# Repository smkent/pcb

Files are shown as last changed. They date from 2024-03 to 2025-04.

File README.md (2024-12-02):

# PCB designs

A monorepository of my PCB designs created with [KiCAD][kicad] 8.

## Layout and Workflow

Custom symbols and footprints are located in [`libraries`][dir-libraries], which
is shared between PCB projects using [`${KIPRJMOD}`][docs-kiprjmod].

Individual PCB projects (e.g. `*.kicad_pro` and friends) are located within
within [`pcb`][dir-pcb] for active projects, or
[`pcb-archived`][dir-pcb-archived] for archived projects.

When a PCB is ordered from a project, fabrication outputs are created and
in the project's `fab` subdirectory and committed to the repository.

## Setup

Ensure [pipx][pipx] is installed:

```sh
pip install pipx
```

Install [scons][scons]:

```sh
pipx install scons
```

Install KiCAD-related dependencies using the system site packages directory:

```sh
pipx install --system-site-packages kikit interactivehtmlbom
```

## Build

To render all outputs, simply run `scons`.

To render outputs for a particular board, run `scons -u` within that board's
project subdirectory.

## Licenses

Individual hardware designs in this repository may use different licenses.
The following licenses apply unless an included design directory specifies
different license(s).

* Hardware materials and designs are licensed under [CERN Open Hardware License
  version 2.0 Permissive (CERN-OHL-P v2)][license-cern-ohl-p-2.0]
  ([text](/LICENSE.hardware)). The version control history of this repository
  serves as the changes file.
* Software is licensed under the
  [GNU General Public License v3.0 (GPL-3.0)][license-gpl-3.0]
  ([text](/LICENSE.software))
* All documentation is licensed under
  [Creative Commons Attribution-ShareAlike 4.0 International
  (CC-BY-SA-4.0)][license-cc-by-sa-4.0] ([text](/LICENSE.documentation))

The `lcsc` KiCAD [symbols][libraries-lcsc-symbols],
[footprints][libraries-lcsc-pretty], and [3D models][libraries-lcsc-3dshapes]
libraries were created using [easyeda2kicad][easyeda2kicad]
([pypi][easyeda2kicad-pypi]), which are from [LCSC][lcsc]. [More info about
easyeda2kicad][easyeda2kicad-post]

[dir-libraries]: /libraries
[dir-pcb-archived]: /pcb-archived
[dir-pcb]: /pcb
[docs-kiprjmod]: https://docs.kicad.org/8.0/it/pcbnew/pcbnew_footprints_and_libraries.html#fp-path-variable-substitution
[easyeda2kicad-post]: https://hackaday.com/2023/08/08/easyeda2kicad-never-draw-a-footprint-again/
[easyeda2kicad-pypi]: https://pypi.org/project/easyeda2kicad/
[easyeda2kicad]: https://github.com/uPesy/easyeda2kicad.py
[kicad]: https://kicad.org/
[lcsc]: https://lcsc.com
[libraries-lcsc-3dshapes]: /libraries/lcsc.3dshapes
[libraries-lcsc-pretty]: /libraries/lcsc.pretty
[libraries-lcsc-symbols]: /libraries/lcsc.kicad_sym
[license-cc-by-sa-4.0]: https://creativecommons.org/licenses/by-sa/4.0/
[license-cern-ohl-p-2.0]: https://ohwr.org/cern_ohl_p_v2.pdf
[license-gpl-3.0]: https://www.gnu.org/licenses/gpl-3.0.html
[pipx]: https://pipx.pypa.io
[scons]: https://www.scons.org

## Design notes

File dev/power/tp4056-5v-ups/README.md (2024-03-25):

# Li-ion 5V UPS

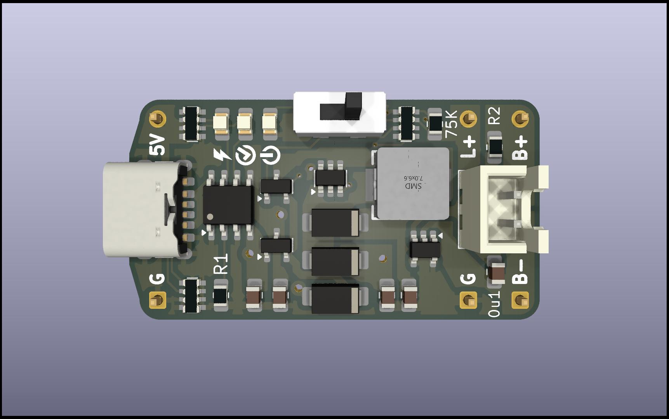
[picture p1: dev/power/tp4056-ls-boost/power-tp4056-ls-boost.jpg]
Render


Features:

* 1A Li-Ion battery charger ([TP4056][tp4056])
* Battery protection with 3V discharge cutoff ([XB5350D0][xb5350d0],
  [english translation](/datasheets/XySemi-XB5307H-en.pdf))
* Load-sharing circuit
* 5V boost converter ([MT3608][mt3608])

## Acknowledgements

Built from scratch using the IC datasheet application circuits, but inspired by
[@wagiminator][wagiminator-power-boards]'s [TP4056 LiPo Charger LS][wagiminator-tp4056-lipo-charger-ls] and
[MT3608 12V Boost Converter Stick][wagiminator-mt3608-12v-boost-converter].

[mt3608]: https://www.olimex.com/Products/Breadboarding/BB-PWR-3608/resources/MT3608.pdf
[tp4056]: https://dlnmh9ip6v2uc.cloudfront.net/datasheets/Prototyping/TP4056.pdf
[wagiminator-mt3608-12v-boost-converter]: https://github.com/wagiminator/Power-Boards/tree/master/Boost_Converter_MT3608
[wagiminator-power-boards]: https://github.com/wagiminator/Power-Boards
[wagiminator-tp4056-lipo-charger-ls]: https://github.com/wagiminator/Power-Boards/tree/master/LiPo_Charger_LS_TP4056
[xb5350d0]: https://www.lcsc.com/datasheet/lcsc_datasheet_2106062205_XySemi-XB5350D0_C2760002.pdf

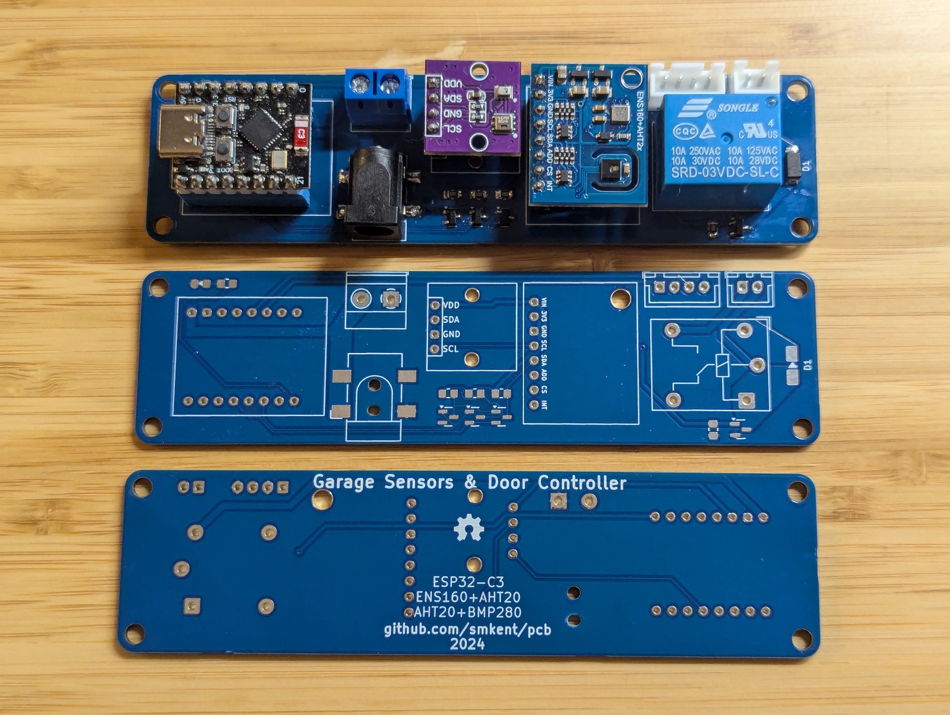
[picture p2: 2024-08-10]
pcb/esphome/garage-door-control/photo.jpg

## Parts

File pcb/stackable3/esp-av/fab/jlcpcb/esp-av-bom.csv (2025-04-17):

Comment | Designator | Footprint | LCSC
JST SH | J10,J17 | connector:JST_SH_SM05B-SRSS-TB_1x05-1MP_P1.00mm_Horizontal | C7433426
ESP32-C3-WROOM-02 | SM1 | module:ESP32-C3-WROOM-02
Qwiic | J12 | connector:Qwiic-SMD-horizontal-logo-bottom-pinout | C19270571
74HC595 | U12,U13 | Package_SO:SOIC-16_3.9x9.9mm_P1.27mm
Tactile 3.3mm | SW2 | electromechanical:SW_Push_1P1T_NO_3.3x3.3mm_MP
MAX809C263NR | U14 | Package_TO_SOT_SMD:SOT-23 | C5223646
GT0104SC | U16 | package:QFN-12-1EP_2x2mm_P0.4mm_EP1.1x1.1mm | C22356898
G2N7002X | Q2,Q8,Q17,Q19 | package:SOT-523 | C5258971
1u | C1,C2,C4,C5 | discrete:C_0603_1608Metric | C5199872
Pin socket | J14 | Connector_PinSocket_2.54mm:PinSocket_1x05_P2.54mm_Vertical
Qwiic | J13 | connector:Qwiic-SMD-vertical | C27636912
100K | RN3,RN4,RN7,RN8,RN9,RN10 | discrete:R_Array_Convex_4x0603 | C110374
Tactile, right-angle | SW1 | electromechanical:SW_Push_1P1T-MP_NO_4.6x3mm_Horizontal | C2888932
10u | C10,C11,C17 | discrete:C_0603_1608Metric | C22367825
22u | C14,C15 | discrete:C_0603_1608Metric | C86295
USBLC6-2P6 | U1 | Package_TO_SOT_SMD:SOT-666 | C29780639
USB_C_Receptacle_USB2.0_16P | J1 | connector:USB_C_Receptacle_GCT_USB4105-xx-A_16P_TopMnt_Horizontal | C2765186
DC-005 | J0 | connector:BarrelJack_DC-005_THT_Horizontal
5K1 | R1,R2,R16,R18,R19,R20,R22 | Resistor_SMD:R_0603_1608Metric | C23186
D_TVS | D0 | package:D_SOD-123F | C7473216
4u7 | L1 | discrete:L_1008_2520Metric | C22471106
1000u/6.3V | C6,C7,C8 | Capacitor_THT:CP_Radial_D8.0mm_P3.50mm | C5379966
100u/35V | C16 | Capacitor_THT:CP_Radial_D6.3mm_P2.50mm | C5379947
XL-1606SURC | LED0 | discrete:LED_SideEmitter_1.7x1.1mm | C965860
330u/6.3V | C9 | Capacitor_THT:CP_Radial_D5.0mm_P2.00mm | C217541
10K | R3,R9 | Resistor_SMD:R_0603_1608Metric | C25804
1K | R4 | Resistor_SMD:R_0603_1608Metric | C21190
DS8242-33SS3 | U2 | Package_TO_SOT_SMD:SOT-23 | C5884134
TPS563201 | U3 | Package_TO_SOT_SMD:SOT-23-6 | C116592
57K6 | R8 | Resistor_SMD:R_0603_1608Metric | C23082
16V 2A | F1 | discrete:Fuse_1206_3216Metric | C2982271
0u1 | C12,C13 | discrete:C_0603_1608Metric | C14663
5K1 | RN1,RN5,RN6,RN11 | discrete:R_Array_Convex_4x0603 | C711414
SK6812SIDE-A | PIX1,PIX2,PIX3,PIX4 | discrete:LED_SK6812SIDE-A_4.0x1.6mm | C2890037
PDNM6ET20V05 | Q1,Q7,Q9,Q10,Q15,Q16 | Package_TO_SOT_SMD:SOT-563 | C918811
XL-1606UGC | LED3,LED4 | discrete:LED_SideEmitter_1.7x1.1mm | C965863
XL-1606UWC | LED1,LED2 | discrete:LED_SideEmitter_1.7x1.1mm | C965866
13K | R37,R38 | Resistor_SMD:R_0603_1608Metric | C22797
Warm White | LED13 | discrete:LED_0603_1608Metric | C2827262
Pink | LED9,LED10,LED11,LED12,LED14,LED15,LED16,LED17,LED18 | discrete:LED_0603_1608Metric | C7496826
1N5819WT | D1,D2,D3,D4,D5,D6,D7 | package:D_SOD-523 | C20754784
SN74LVC1G157DC | U6,U7,U8,U9 | Package_TO_SOT_SMD:SOT-363_SC-70-6 | C22469913
PJ-327U | J2,J3,J4,J5,J6,J7,J8,J9 | connector:Jack_3.5mm_PJ-327U-SMT_Horizontal | C397453
100K | R5,R6,R7,R17,R30,R32,R33,R34,R35 | Resistor_SMD:R_0603_1608Metric | C25803
15R4 | R12,R13,R14,R15,R24,R25,R26,R27 | Resistor_SMD:R_1206_3216Metric | C3013373
Ice Blue | LED5,LED6,LED7,LED8,LED19 | discrete:LED_0603_1608Metric | C7496823
SP2006KT5 | Q11,Q14 | package:SOT-523 | C41355141
24V 50mA | F2,F3,F4,F5 | Fuse:Fuse_0603_1608Metric | C369141
DY-IRMHA384 | U10 | package:IRM_5.0mmx4.2mm_P1.27mm_Horizontal | C6071554
SN74AHC1G08DC | U15 | Package_TO_SOT_SMD:SOT-353_SC-70-5 | C22469964
NC7WZ14P6X | U4,U5 | Package_TO_SOT_SMD:SOT-363_SC-70-6 | C5207816
SP2301DTS | Q3,Q4,Q5,Q6 | Package_TO_SOT_SMD:SOT-23-6 | C41355155
2K2 | R10,R11 | Resistor_SMD:R_0603_1608Metric | C4190
Pin socket | J11 | Connector_PinSocket_2.54mm:PinSocket_1x03_P2.54mm_Vertical

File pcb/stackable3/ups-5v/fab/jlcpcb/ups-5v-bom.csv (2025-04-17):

Comment | Designator | Footprint | LCSC
SW_SPDT_MountingPin | SW1,SW2,SW3 | electromechanical:SW_SPDT_PCM12 | C319020
10K | R1,R2,R6,R7,R8,R9,R13 | Resistor_SMD:R_0603_1608Metric | C25804
2u2 | L1 | discrete:L_1008_2520Metric | C5832372
SP2006KT5 | Q4,Q5 | package:SOT-523 | C41355141
5K1 | R11,R14,R15,R16,R17,R20,R21 | Resistor_SMD:R_0603_1608Metric | C25905
22u | C1 | discrete:C_0603_1608Metric | C86295
10u | C5,C7 | discrete:C_0603_1608Metric | C22367825
22u | C3 | discrete:C_0805_2012Metric | C602037
100K | R18,R19 | Resistor_SMD:R_0603_1608Metric | C25803
22K | R22,R23 | Resistor_SMD:R_0603_1608Metric | C31850
JST SH | J5,J6 | connector:JST_SH_SM02B-SRSS-TB_1x02-1MP_P1.00mm_Horizontal | C7433423
D_TVS | D2,D4 | Diode_SMD:D_SOD-882 | C45961
68u/16V | C8,C9 | Capacitor_THT:CP_Radial_D6.3mm_P2.50mm | C2976197
Red | LED5,LED6 | discrete:LED_0603_1608Metric | C7371906
100R | R12 | Resistor_SMD:R_0603_1608Metric | C25076
USB_C_Receptacle_PowerOnly_6P | J1,J2 | connector:USB_C_Receptacle_GCT_USB4125-xx-x_6P_TopMnt_Horizontal_HandSolder | C2927029
MAX17048 | U3 | package:TDFN-8-1EP_2x2mm_P0.5mm_EP0.8x1.2mm | C2682616
Qwiic | J3 | connector:Qwiic-SMD-horizontal-logo | C19270571
G2N7002X | Q3 | package:SOT-523 | C5258971
XL-1606UBC | LED4 | discrete:LED_SideEmitter_1.7x1.1mm | C965865
1u | C2,C4,C6 | discrete:C_0603_1608Metric | C5199872
75K | R10 | Resistor_SMD:R_0603_1608Metric | C23242
18650 | BT1 | connector:BatteryHolder_1x18650_THT
10V | D3 | package:D_SOD-523 | C2832579
1N5819WT | D5,D6 | package:D_SOD-523 | C20754784
XB3306D | U2 | Package_TO_SOT_SMD:SOT-23 | C2759992
470R | R5 | Resistor_SMD:R_0603_1608Metric | C23179
XL-1606SURC | LED3 | discrete:LED_SideEmitter_1.7x1.1mm | C965860
4u7 | L2 | discrete:L_1008_2520Metric | C22471106
BAT60A | D1 | package:D_SOD-323 | C7502695
XL-1606UWC | LED1 | discrete:LED_SideEmitter_1.7x1.1mm | C965866
ETA6003 | U1 | package:QFN-16-1EP_3x3mm_P0.5mm_EP1.7x1.7mm_ThermalVias_ETA6003 | C5455585
2K2 | R4 | Resistor_SMD:R_0603_1608Metric | C4190
DMP1045U | Q1,Q2 | Package_TO_SOT_SMD:SOT-23 | C177033
MT3608 | U4 | Package_TO_SOT_SMD:SOT-23-6 | C84817
5K1 | R3 | Resistor_SMD:R_0603_1608Metric | C23186
JST PH | J4 | connector:JST_PH_S2B-PH-SM4-TB_1x02-1MP_P2.00mm_Horizontal | C18221575
XL-1606UGC | LED2 | discrete:LED_SideEmitter_1.7x1.1mm | C965863

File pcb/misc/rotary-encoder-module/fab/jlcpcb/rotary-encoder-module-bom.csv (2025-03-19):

Comment | Designator | Footprint | LCSC
Green | LED3 | LED_SMD:LED_0402_1005Metric_Pad0.77x0.64mm_HandSolder | C7496801
RotaryEncoder_Switch_MP | SW1 | electromechanical:RotaryEncoder_Alps_EC11E-Switch_Vertical_H20mm
Ice Blue | LED1 | LED_SMD:LED_0402_1005Metric_Pad0.77x0.64mm_HandSolder | C7496805
White | LED2 | LED_SMD:LED_0402_1005Metric_Pad0.77x0.64mm_HandSolder | C20613596
10K | RN1,RN2 | discrete:R_Array_Convex_4x0603 | C110924
JST SH | J1 | connector:JST_SH_SM05B-SRSS-TB_1x05-1MP_P1.00mm_Horizontal | C7433426
10n | C2,C3 | discrete:C_0603_1608Metric_Pad1.08x0.95mm_HandSolder | C1589
Pin headers | J2 | custom:PinHeader_1x05_P2.54mm_Vertical_simple_pad1gnd
1u | C1 | discrete:C_0603_1608Metric_Pad1.08x0.95mm_HandSolder | C5199872

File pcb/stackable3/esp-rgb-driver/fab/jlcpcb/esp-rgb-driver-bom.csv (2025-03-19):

Comment | Designator | Footprint | LCSC
30V 2A | F1 | Fuse:Fuse_1812_4532Metric | C22366122
13K | R2 | Resistor_SMD:R_0603_1608Metric | C22797
INA226 | U2 | Package_SO:VSSOP-10_3x3mm_P0.5mm | C49851
22u | C5,C6,C7 | discrete:C_0603_1608Metric | C86295
5K1 | R3,R6 | Resistor_SMD:R_0402_1005Metric | C25905
0u1 | C3,C4,C8 | discrete:C_0402_1005Metric | C152814
1u | C9 | discrete:C_0402_1005Metric | C52923
SW_Push | SW1 | Button_Switch_SMD:SW_SPST_PTS647_Sx50 | C22459537
2N7002DW | Q4 | Package_TO_SOT_SMD:SOT-363_SC-70-6 | C5190214
Ice Blue | LED1 | discrete:LED_0603_1608Metric | C7496823
22u | L1 | discrete:L_1008_2520Metric | C5832391
Red | LED2 | discrete:LED_0402_1005Metric | C779449
Pink | LED3 | discrete:LED_0402_1005Metric
Qwiic | J8 | connector:Qwiic-SMD-horizontal-logo | C19270571
~ | SM1 | module:ESP32-C3-Super-Mini-Castellated-SMD-only
JST SH | J3 | connector:JST_SH_SM05B-SRSS-TB_1x05-1MP_P1.00mm_Horizontal | C7433426
10u | C1,C2 | discrete:C_0603_1608Metric | C22367825
3.3mm | SW2,SW3,SW4 | electromechanical:SW_Push_1P1T_NO_3.3x3.3mm_MP
100K | R1 | Resistor_SMD:R_0603_1608Metric | C25803
10K | RN1,RN2,RN3,RN4 | discrete:R_Array_Convex_4x0603 | C110924
DC-005 | J0 | connector:BarrelJack_DC-005_THT_Horizontal
IRM | U5 | package:IRM_5.0x5.0mm_SIP-3_P1.27mm_THT | C7433078
10R | R5,R8 | Resistor_SMD:R_0402_1005Metric | C25077
1K | R4,R7,R11,R12,R13,R14,R15 | Resistor_SMD:R_0402_1005Metric | C11702
D_TVS | D1 | package:D_SOD-123F | C7473232
R020 | SR1 | Resistor_SMD:R_2512_6332Metric_Pad1.40x3.35mm_HandSolder | C5375467
100u | C0 | Capacitor_THT:CP_Radial_D6.3mm_P2.50mm | C5379947
TPS54202DDCR | U1 | Package_TO_SOT_SMD:SOT-23-6 | C191884
WS2811F | U3,U4 | package:FSOP-8_3.3x1.7mm_P0.80mm | C5446692
ZC010DNG | Q1,Q2,Q3 | package:PDFN-8_L3.2-W3.1-P0.65-LS3.4-BL-EP2 | C36499170
JST PH | J1,J2 | connector:JST_PH_S4B-PH-SM4-TB_1x04-1MP_P2.00mm_Horizontal | C5343396
NC7WZ14P6X | U7,U8,U9 | Package_TO_SOT_SMD:SOT-363_SC-70-6 | C5207816
STEMMA-Signal | J5,J6 | connector:STEMMA-Signal-SMD-horizontal | C5372880
10K | R9,R10 | Resistor_SMD:R_0402_1005Metric | C25744
XL-B1010RGBT-HF | LED4,LED5 | discrete:LED_RGB_XL-B1010RGBT-HF_1.0x1.0mm | C22464515
SP2006KT5 | Q6 | package:SOT-523 | C41355141
G2N7002X | Q5 | package:SOT-523 | C5258971

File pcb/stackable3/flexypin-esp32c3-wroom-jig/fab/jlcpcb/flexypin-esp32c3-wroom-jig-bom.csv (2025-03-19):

Comment | Designator | Footprint | LCSC
5K1 | RN3,RN4,RN5,RN6 | discrete:R_Array_Convex_4x0402_HandSolder | C425290
Ice Blue | LED2,LED3,LED4,LED5,LED6,LED7,LED8,LED9,LED10,LED11,LED14,LED15,LED16 | discrete:LED_0402_1005Metric | C7496805
10u | C1,C2 | discrete:C_0402_1005Metric | C315248
G2N7002X | Q1 | package:SOT-523 | C5258971
Pin socket | J2,J3 | Connector_PinSocket_2.54mm:PinSocket_1x08_P2.54mm_Vertical
White | LED12,LED13 | discrete:LED_0402_1005Metric | C20613596
ME6211C33M5 | U1 | Package_TO_SOT_SMD:SOT-23-5 | C82942
Boot | SW1,SW2 | electromechanical:SW_Push_1P1T_NO_3.3x3.3mm_MP
5K1 | R1,R2 | Resistor_SMD:R_0603_1608Metric | C23186
USB_C_Receptacle_USB2.0_16P | J1 | connector:USB_C_Receptacle_GCT_USB4105-xx-A_16P_TopMnt_Horizontal | C2765186
Pink | LED0,LED1 | discrete:LED_0402_1005Metric | C779449
5K1 | R3 | Resistor_SMD:R_0402_1005Metric | C25905
SK6812 | PIX1 | discrete:LED_SK6812_PLCC4_5.0x5.0mm_P3.2mm
ESP32-C3-WROOM-02 | SM1 | module:ESP32-C3-WROOM-02-FlexyPin
10K | R4,R5 | Resistor_SMD:R_0603_1608Metric | C25804
USBLC6-2P6 | U2 | Package_TO_SOT_SMD:SOT-666 | C29780639
100K | RN2 | discrete:R_Array_Convex_4x0402_HandSolder | C110374
1u | C3 | discrete:C_0402_1005Metric | C52923

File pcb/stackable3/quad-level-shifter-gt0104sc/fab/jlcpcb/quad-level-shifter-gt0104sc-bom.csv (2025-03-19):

Comment | Designator | Footprint | LCSC
LED | LED1,LED2,LED3,LED4,LED5,LED6,LED7,LED8 | discrete:LED_0603_1608Metric
5K1 | RN3,RN4 | discrete:R_Array_Convex_4x0402_HandSolder | C425290
Pin socket | J2,J3 | Connector_PinSocket_2.54mm:PinSocket_1x06_P2.54mm_Vertical
10u | C1,C2 | discrete:C_0402_1005Metric | C315248
ME6211C33M5 | U1 | Package_TO_SOT_SMD:SOT-23-5 | C82942
G2N7002X | Q1,Q2 | package:SOT-523 | C5258971
100K | RN1,RN2 | discrete:R_Array_Convex_4x0402_HandSolder | C326786
MAX809C263NR | U3 | Package_TO_SOT_SMD:SOT-23 | C5223646
10K | R3,R4 | Resistor_SMD:R_0402_1005Metric | C25744
100K | R5 | Resistor_SMD:R_0402_1005Metric | C25741
SW_SPDT_MountingPin | SW1 | electromechanical:SW_SPDT_PCM12 | C319020
5K1 | R1,R2 | Resistor_SMD:R_0603_1608Metric | C23186
USB_C_Receptacle_PowerOnly_6P | J1 | connector:USB_C_Receptacle_GCT_USB4125-xx-x_6P_TopMnt_Horizontal_HandSolder | C2927029
GT0104SC | U2 | package:QFN-12-1EP_2x2mm_P0.4mm_EP1.1x1.1mm | C22356898

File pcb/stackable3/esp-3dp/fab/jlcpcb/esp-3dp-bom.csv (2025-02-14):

Comment | Designator | Footprint | LCSC
0u1 | C3,C4,C10,C11 | discrete:C_0402_1005Metric
SN74LVC1T45Z6 | U4,U5 | Package_TO_SOT_SMD:SOT-563 | C441819
22u | L1 | discrete:L_Power_7.0x6.6mm_0630
SK6812SIDE-A | PIX1,PIX2,PIX3,PIX4,PIX5 | discrete:LED_SK6812SIDE-A_4.0x1.6mm | C2890037
TPS563201 | U2 | Package_TO_SOT_SMD:SOT-23-6 | C116592
DC-005 | J0,J1 | connector:BarrelJack_DC-005_THT_Horizontal
22u | C5,C6 | discrete:C_0805_2012Metric
~ | SM1 | module:ESP32-C3-Super-Mini-Castellated-SMD
100u | C14,C16 | Capacitor_SMD:CP_Elec_5x5.4 | C4054379
XL-1606SURC | LED2 | discrete:LED_SideEmitter_1.7x1.1mm | C965860
5K1 | R0,R2 | Resistor_SMD:R_0603_1608Metric
4u7 | L2 | discrete:L_1008_2520Metric | C22471106
57K6 | R4 | Resistor_SMD:R_0603_1608Metric | C23082
10u | C1,C2,C8,C9 | discrete:C_0603_1608Metric
Qwiic | J5 | connector:Qwiic-SMD-horizontal | C19270571
17K4 | R12 | Resistor_SMD:R_0603_1608Metric | C22819
100R | RN2 | discrete:R_Array_Convex_4x0603_HandSolder | C270393
2N7002DW | Q1 | package:SOT-363_SC-70-6_HandSolder | C5190214
10K | RN1 | discrete:R_Array_Convex_4x0603_HandSolder | C110924
30V 2A | F1 | Fuse:Fuse_1812_4532Metric | C22366122
JST SH | J2,J3 | connector:JST_SH_SM05B-SRSS-TB_1x05-1MP_P1.00mm_Horizontal | C7433426
DSK34W | D1 | package:D_SOD-123F | C3014041
470u | C7 | Capacitor_SMD:CP_Elec_8x10 | C7471889
100K | R1 | Resistor_SMD:R_0603_1608Metric
AO3401A | Q3 | Package_TO_SOT_SMD:SOT-23
10V | D3 | package:D_SOD-523 | C2832579
TPS54202DDCR | U1 | Package_TO_SOT_SMD:SOT-23-6 | C191884
1000u | C15 | Capacitor_SMD:CP_Elec_8x10 | C311227
22u | C12,C13 | discrete:C_0603_1608Metric
D_TVS | D2 | package:D_SOD-123F | C7473232
10K | R6,R7 | Resistor_SMD:R_0603_1608Metric
KF2510 | M1 | connector:FanPinHeader_1x04_P2.54mm_Horizontal
XL-1606UWC | LED1 | discrete:LED_SideEmitter_1.7x1.1mm | C965866
STEMMA-Signal | J4 | connector:STEMMA-Signal-SMD-horizontal | C5372880
1K | R3 | Resistor_SMD:R_0603_1608Metric

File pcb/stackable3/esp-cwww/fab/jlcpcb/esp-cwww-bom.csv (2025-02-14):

Comment | Designator | Footprint | LCSC
STEMMA-Signal | J5 | connector:STEMMA-Signal-SMD-horizontal | C5372880
100u | C12 | Capacitor_SMD:CP_Elec_5x5.4 | C4054379
XL-1606UWC | LED0 | discrete:LED_SideEmitter_1.7x1.1mm | C965866
D_TVS | D1 | package:D_SOD-123F | C7473216
JST SH | J3 | connector:JST_SH_SM05B-SRSS-TB_1x05-1MP_P1.00mm_Horizontal | C7433426
~ | SM1 | module:ESP32-C3-Super-Mini-Castellated-SMD
2N7002DW | Q2 | package:SOT-363_SC-70-6_HandSolder | C5190214
SK6812SIDE-A | PIX1,PIX2,PIX3,PIX4,PIX5,PIX6 | discrete:LED_SK6812SIDE-A_4.0x1.6mm | C2890037
57K6 | R1 | Resistor_SMD:R_0603_1608Metric | C23082
0u1 | C3,C4 | discrete:C_0603_1608Metric
5K1 | R0 | Resistor_SMD:R_0603_1608Metric
10K | RN1,RN2 | discrete:R_Array_Convex_4x0603_HandSolder | C110924
0u1 | C9 | discrete:C_0402_1005Metric | C152814
10u | C1,C2 | discrete:C_0603_1608Metric
16V 2A | F1 | discrete:Fuse_1206_3216Metric | C2982271
DC-005 | J0 | connector:BarrelJack_DC-005_THT_Horizontal
22u | C5,C6 | discrete:C_0603_1608Metric
10n | C7,C8 | discrete:C_0603_1608Metric
Qwiic | J2 | connector:Qwiic-SMD-horizontal-logo | C19270571
INA226 | U2 | Package_SO:VSSOP-10_3x3mm_P0.5mm | C49851
10R | R6,R7 | Resistor_SMD:R_0402_1005Metric | C25077
4u7 | L1 | discrete:L_1008_2520Metric | C22471106
XL-1606SURC | LED1 | discrete:LED_SideEmitter_1.7x1.1mm | C965860
R020 | SR1 | Resistor_SMD:R_2512_6332Metric_Pad1.40x3.35mm_HandSolder | C5375467
470u | C11 | Capacitor_SMD:CP_Elec_8x10 | C7471889
JST PH | J1 | connector:STEMMA-Signal-SMD-horizontal | C5372880
1K | R8 | Resistor_SMD:R_0603_1608Metric
ZC010DNG | Q1 | package:PDFN-8_L3.2-W3.1-P0.65-LS3.4-BL-EP2 | C36499170
10K | R4,R5 | Resistor_SMD:R_0402_1005Metric
10K | R2,R3 | Resistor_SMD:R_0603_1608Metric
JST PH | J6 | connector:JST_PH_S4B-PH-SM4-TB_1x04-1MP_P2.00mm_Horizontal | C5343396
JST PH | J4 | connector:JST_PH_S6B-PH-SM4-TB_1x06-1MP_P2.00mm_Horizontal | C7433652
RotaryEncoder_Switch_MP | SW1 | electromechanical:RotaryEncoder_Alps_EC11-Switch_Horizontal_H20mm
TPS563201 | U1 | package:SOT-23-6 | C116592
1u | C10 | discrete:C_0402_1005Metric

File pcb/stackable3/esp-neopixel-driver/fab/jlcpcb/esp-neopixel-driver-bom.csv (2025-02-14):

Comment | Designator | Footprint | LCSC
JST SH | J4,J5 | connector:JST_SH_SM05B-SRSS-TB_1x05-1MP_P1.00mm_Horizontal | C7433426
5K1 | R0,R1 | Resistor_SMD:R_0402_1005Metric | C25905
XL-1606UWC | LED0 | discrete:LED_SideEmitter_1.7x1.1mm | C965866
100u | C1 | Capacitor_SMD:CP_Elec_5x5.4 | C4054379
XL-1606UGC | LED2 | discrete:LED_SideEmitter_1.7x1.1mm | C965863
Qwiic | J1 | connector:Qwiic-SMD-horizontal-logo | C19270571
~ | SM1 | module:ESP32-C3-Super-Mini-Castellated-SMD-only
5K36 | RN2 | Resistor_SMD:R_Array_Convex_2x0402 | C425352
XL-1606UBC | LED1 | discrete:LED_SideEmitter_1.7x1.1mm | C965865
10K | RN1 | Resistor_SMD:R_Array_Convex_4x0402 | C7422173
STEMMA-Signal | J2,J3 | connector:STEMMA-Signal-SMD-horizontal | C5372880
PDNM6ET20V05 | Q1 | Package_TO_SOT_SMD:SOT-563 | C918811
VEML7700 | U1 | discrete:Sensor_VEML7700-TR | C504893
10K | R2 | Resistor_SMD:R_0402_1005Metric | C25744

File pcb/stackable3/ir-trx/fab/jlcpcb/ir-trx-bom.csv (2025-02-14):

Comment | Designator | Footprint | LCSC
51R | R1,R2,R3,R4,R5,R6,R7,R8,R9,R10 | Resistor_SMD:R_1206_3216Metric | C149687
PJ-327U | J1 | connector:Jack_3.5mm_PJ-327U-SMT_Horizontal_EdgeCut | C397453
1N4148WS | D1 | package:D_SOD-323
SW_SPDT_MountingPin | SW1 | electromechanical:SW_Slide_SPDT_Straight_CK_OS102011MS2Q
DMG6968U | Q3 | Package_TO_SOT_SMD:SOT-23 | C150759
1K | R11,R12,R13,R15 | Resistor_SMD:R_0402_1005Metric
DY-IR333-A | LED7,LED8,LED9,LED10 | LED_THT:LED_D5.0mm_IRGrey | C396674
DMP1045U | Q2 | Package_TO_SOT_SMD:SOT-23 | C177033
100u | C1 | Capacitor_SMD:CP_Elec_5x5.4
G2N7002X | Q1 | package:SOT-523 | C5258971
DY-IRMHA384 | U1 | package:IRM_5.0mmx4.2mm_P1.27mm_Horizontal | C6071554
XL-1606SURC | LED11 | discrete:LED_SideEmitter_1.7x1.1mm | C965860
100R | R14 | Resistor_SMD:R_0603_1608Metric
5K1 | R0,R16 | Resistor_SMD:R_0402_1005Metric
XYC-IR26C-LX4 | LED1,LED2,LED3,LED4,LED5,LED6 | discrete:LED_IR_SideEmitter_1206_3216Metric | C396674
XL-1606UBC | LED0 | discrete:LED_SideEmitter_1.7x1.1mm | C965865
Warm White | LED12 | discrete:LED_0603_1608Metric
1u | C2 | discrete:C_0402_1005Metric

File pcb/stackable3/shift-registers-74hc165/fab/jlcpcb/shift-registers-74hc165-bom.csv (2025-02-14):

Comment | Designator | Footprint | LCSC
Tactile 3.3mm | SW2,SW3,SW4,SW5,SW6,SW7 | electromechanical:SW_Push_1P1T_NO_3.3x3.3mm_MP
LED | LED1,LED2,LED3,LED4,LED5,LED6,LED7,LED8 | discrete:LED_0402_1005Metric
AO3401A | Q1 | Package_TO_SOT_SMD:SOT-23
74HC165 | U1 | Package_SO:SO-16_3.9x9.9mm_P1.27mm
JST SH | J6,J7 | connector:JST_SH_SM05B-SRSS-TB_1x05-1MP_P1.00mm_Horizontal | C7433426
10K | RN3,RN4 | discrete:R_Array_Convex_4x0402 | C7422173
Tactile, right-angle | SW1,SW8 | electromechanical:SW_Push_1P1T-MP_NO_4.6x3mm_Horizontal | C2888932
10K | RN0 | discrete:R_Array_Convex_4x0603_HandSolder | C110924
SW_SPDT_MountingPin | SW0 | electromechanical:SW_SPDT_PCM12 | C319020
10K | R1 | Resistor_SMD:R_0402_1005Metric
Pin headers | J1 | connector:PinHeader_1x07_P2.54mm_Horizontal
5K1 | RN1,RN2 | discrete:R_Array_Convex_4x0402 | C425290
Pin socket | J2 | connector:PinSocket_1x07_P2.54mm_Horizontal
Pin headers | J3 | connector:PinHeader_2x08_P2.54mm_Vertical

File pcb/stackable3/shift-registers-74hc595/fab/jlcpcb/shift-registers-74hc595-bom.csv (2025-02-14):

Comment | Designator | Footprint | LCSC
74HC595 | U1,U2 | Package_SO:SOIC-16_3.9x9.9mm_P1.27mm
LED | LED1,LED2,LED3,LED4,LED5,LED6,LED7,LED8,LED9,LED10,LED11,LED12,LED13,LED14,LED15,LED16 | discrete:LED_0603_1608Metric
JST SH | J3,J4 | connector:JST_SH_SM05B-SRSS-TB_1x05-1MP_P1.00mm_Horizontal | C7433426
2K2 | RN1,RN2,RN3,RN4 | discrete:R_Array_Convex_4x0603_HandSolder
10K | RN0 | discrete:R_Array_Convex_4x0402 | C110924
Pin headers | J1 | connector:PinHeader_1x07_P2.54mm_Horizontal
10K | R1 | Resistor_SMD:R_0402_1005Metric
DMG6968U | Q1 | Package_TO_SOT_SMD:SOT-23 | C150759
Pin socket | J2 | connector:PinSocket_1x07_P2.54mm_Horizontal
SW_SPDT_MountingPin | SW0 | electromechanical:SW_SPDT_PCM12 | C319020
Pin socket | J5 | connector:PinHeader_2x10_P2.54mm_Vertical
G2N7002X | Q2 | package:SOT-523 | C5258971

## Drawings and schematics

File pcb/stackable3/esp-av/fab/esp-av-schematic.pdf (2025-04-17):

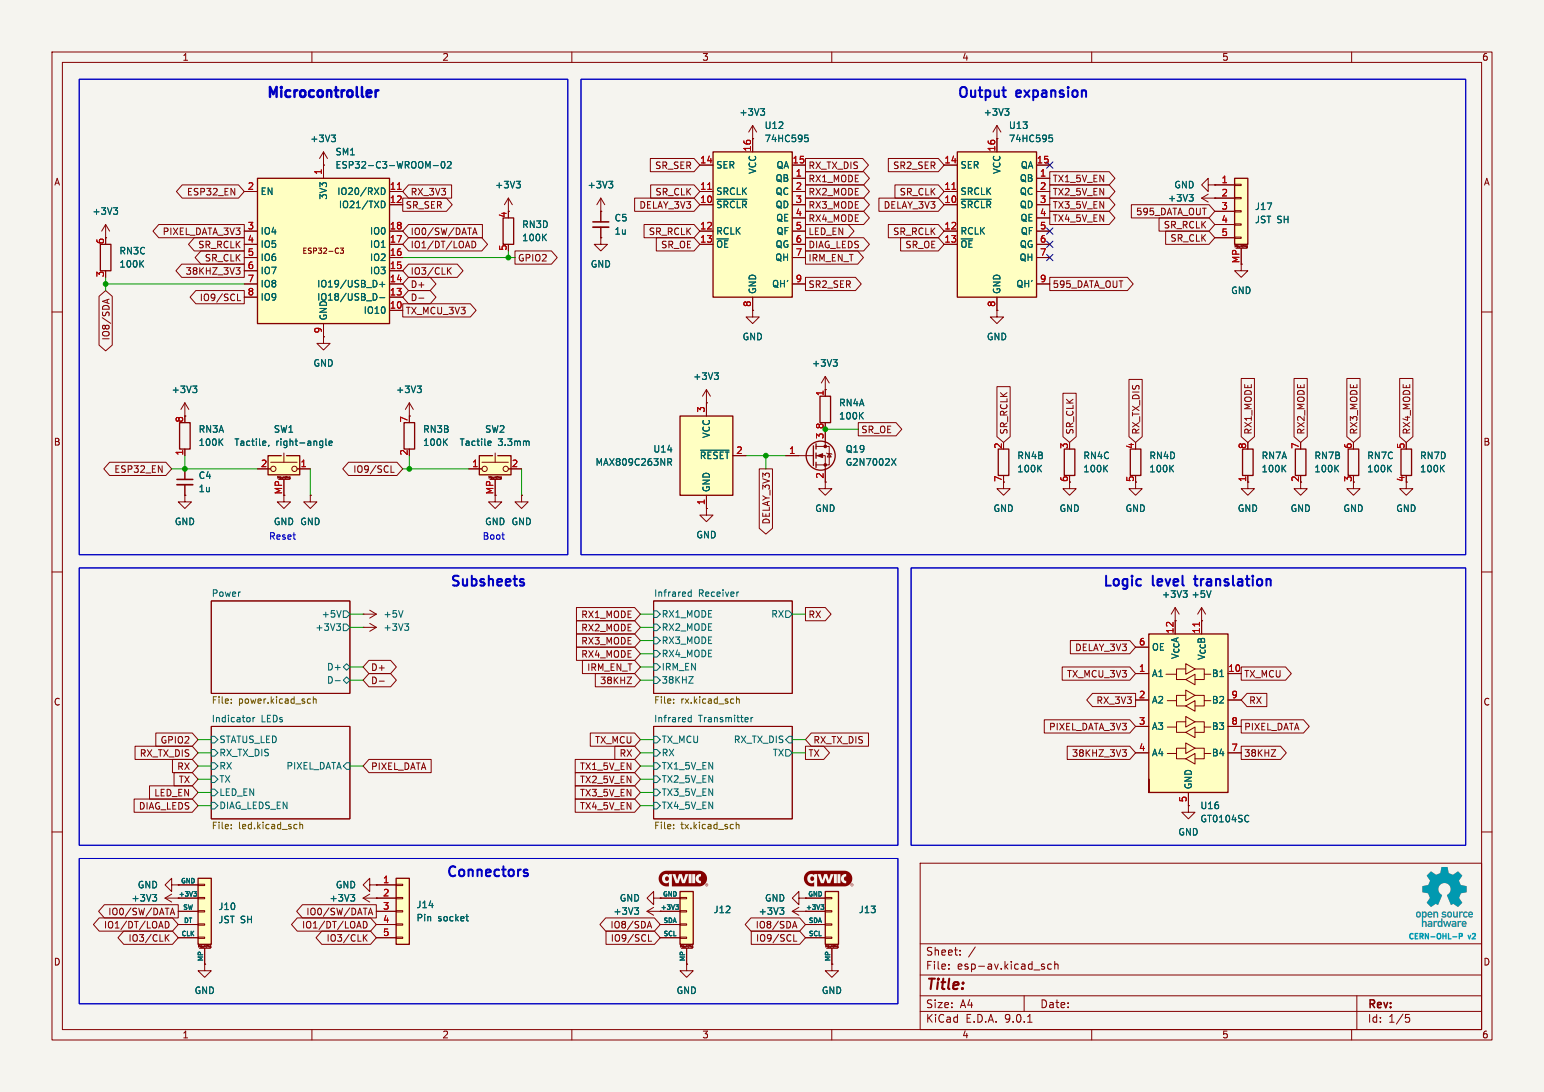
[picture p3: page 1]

8 QA 15 QB 1 QC 2 QD 3 QE 4 QF 5 QG 6 QH 7 QH' 9 +3V3 GND

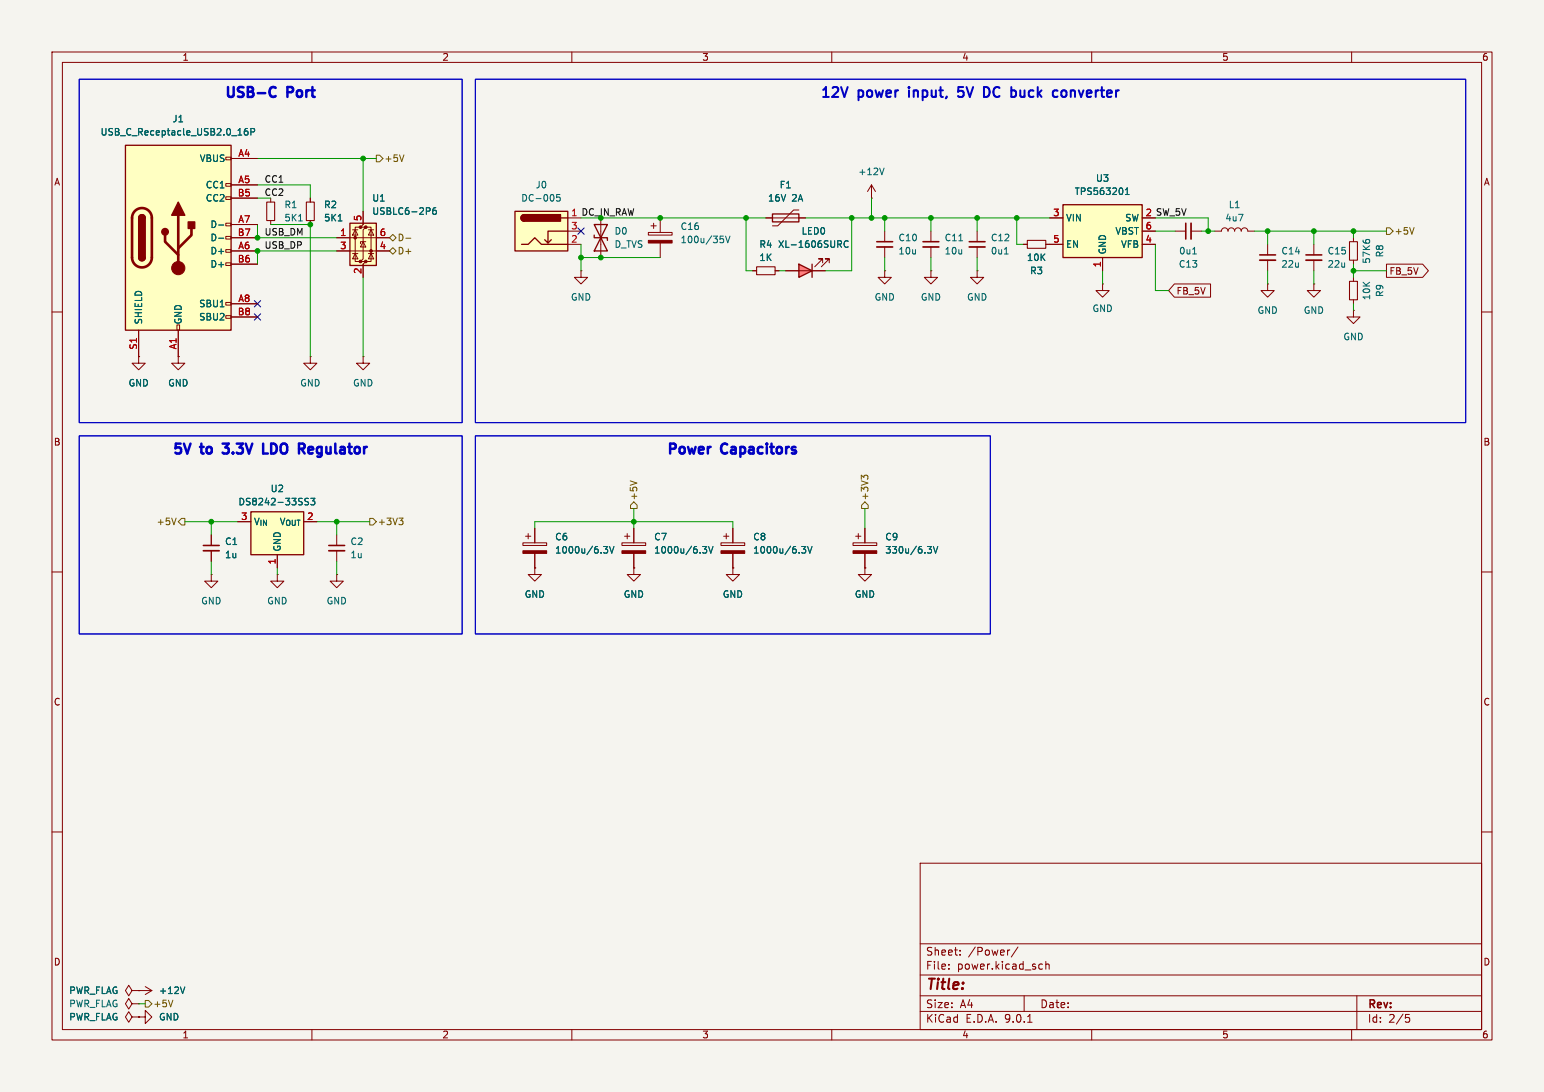
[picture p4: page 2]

12V power input, 5V DC buck converter

1 SW 2 VBST 6 VFB 4 U3 TPS563201 GND R8 57K6 C14

Id: 2/5 Title: File: power.kicad_sch Sheet: /Power/

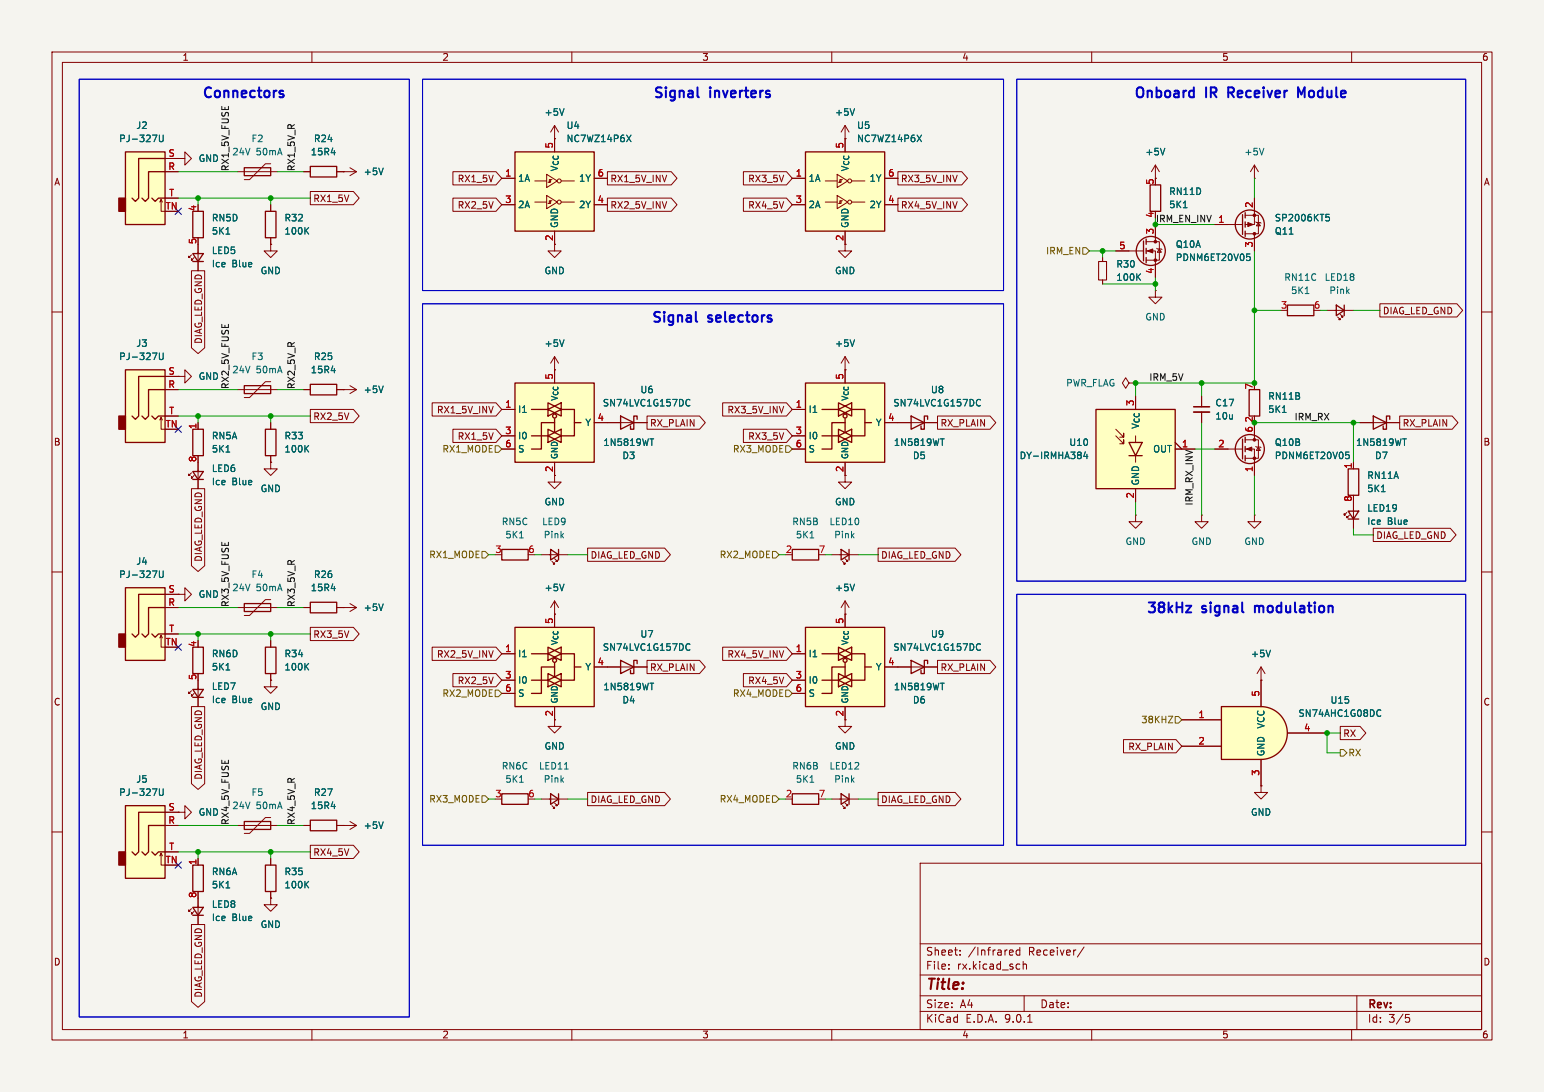
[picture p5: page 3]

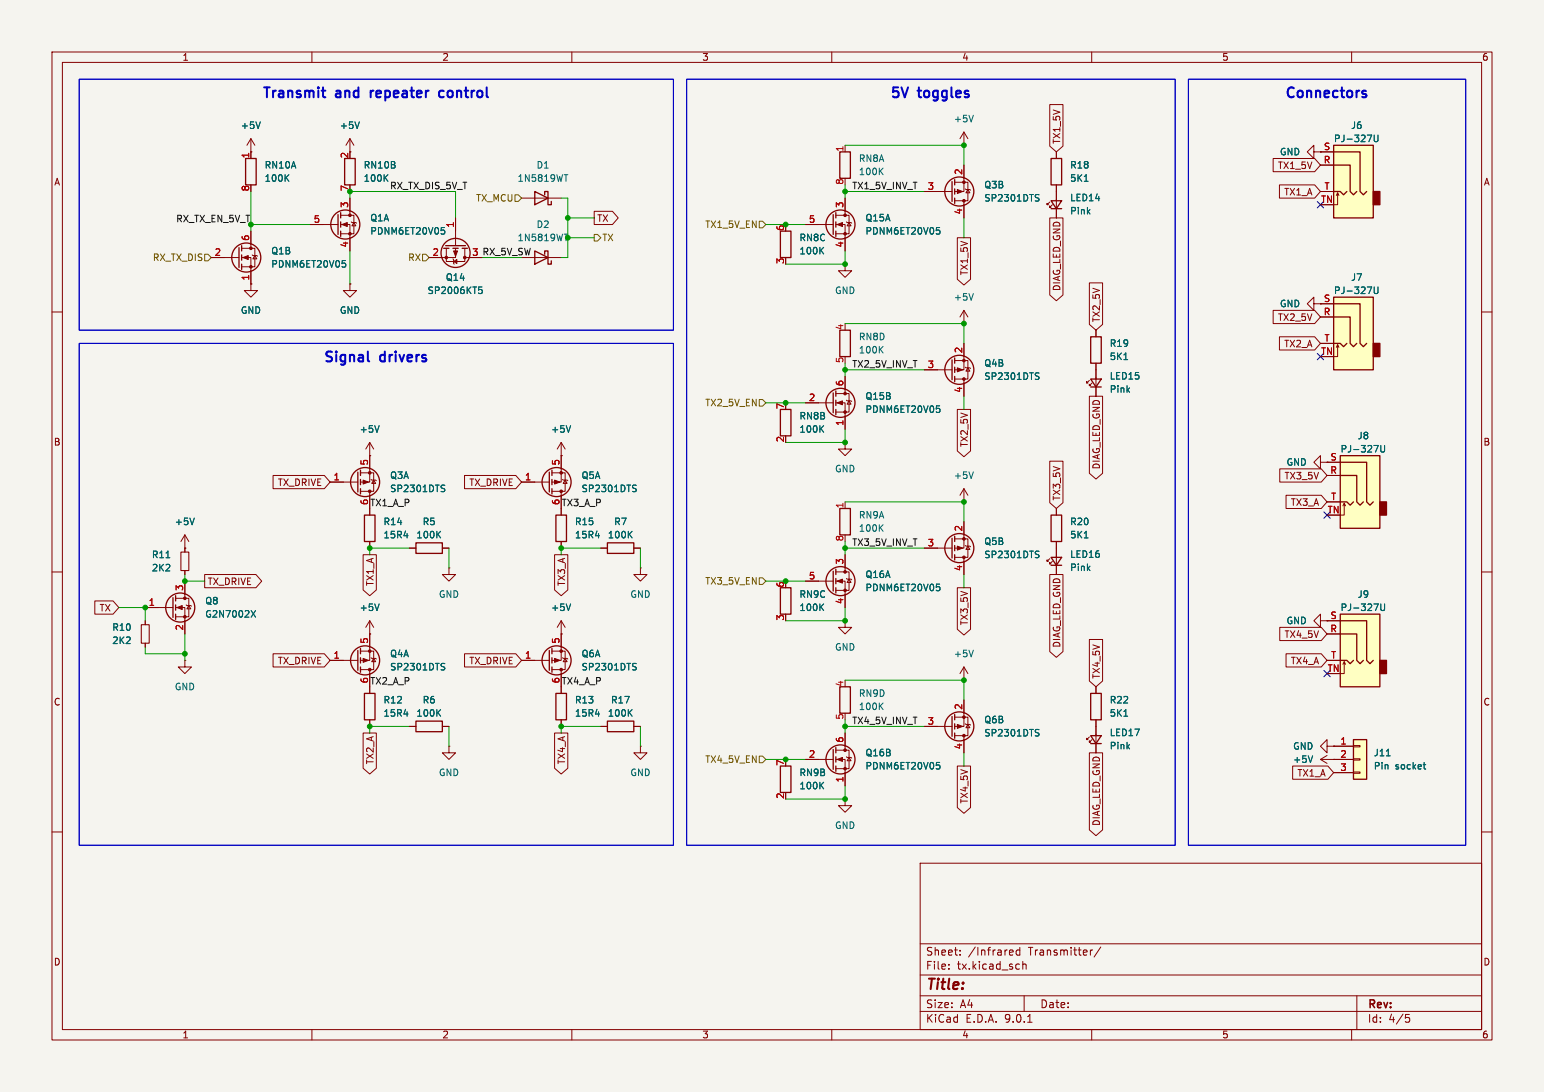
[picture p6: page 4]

J6 PJ-327U SRT
J8 PJ-327U SRT
J7 PJ-327U GND GND GNDGND

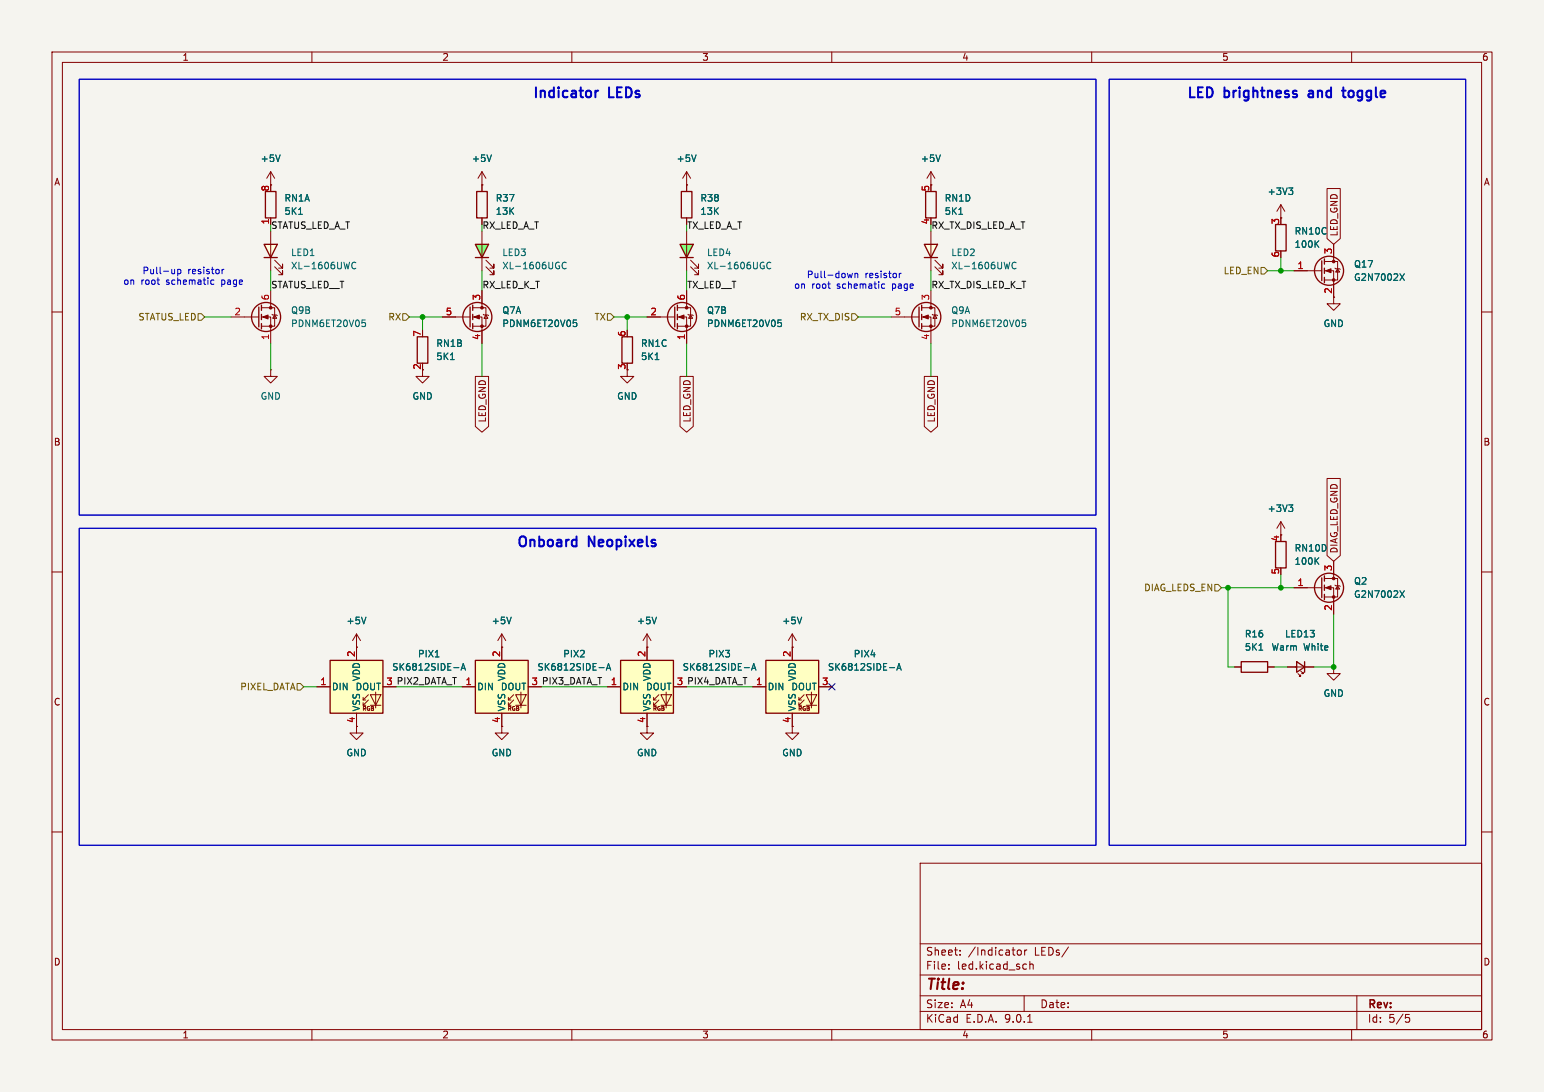
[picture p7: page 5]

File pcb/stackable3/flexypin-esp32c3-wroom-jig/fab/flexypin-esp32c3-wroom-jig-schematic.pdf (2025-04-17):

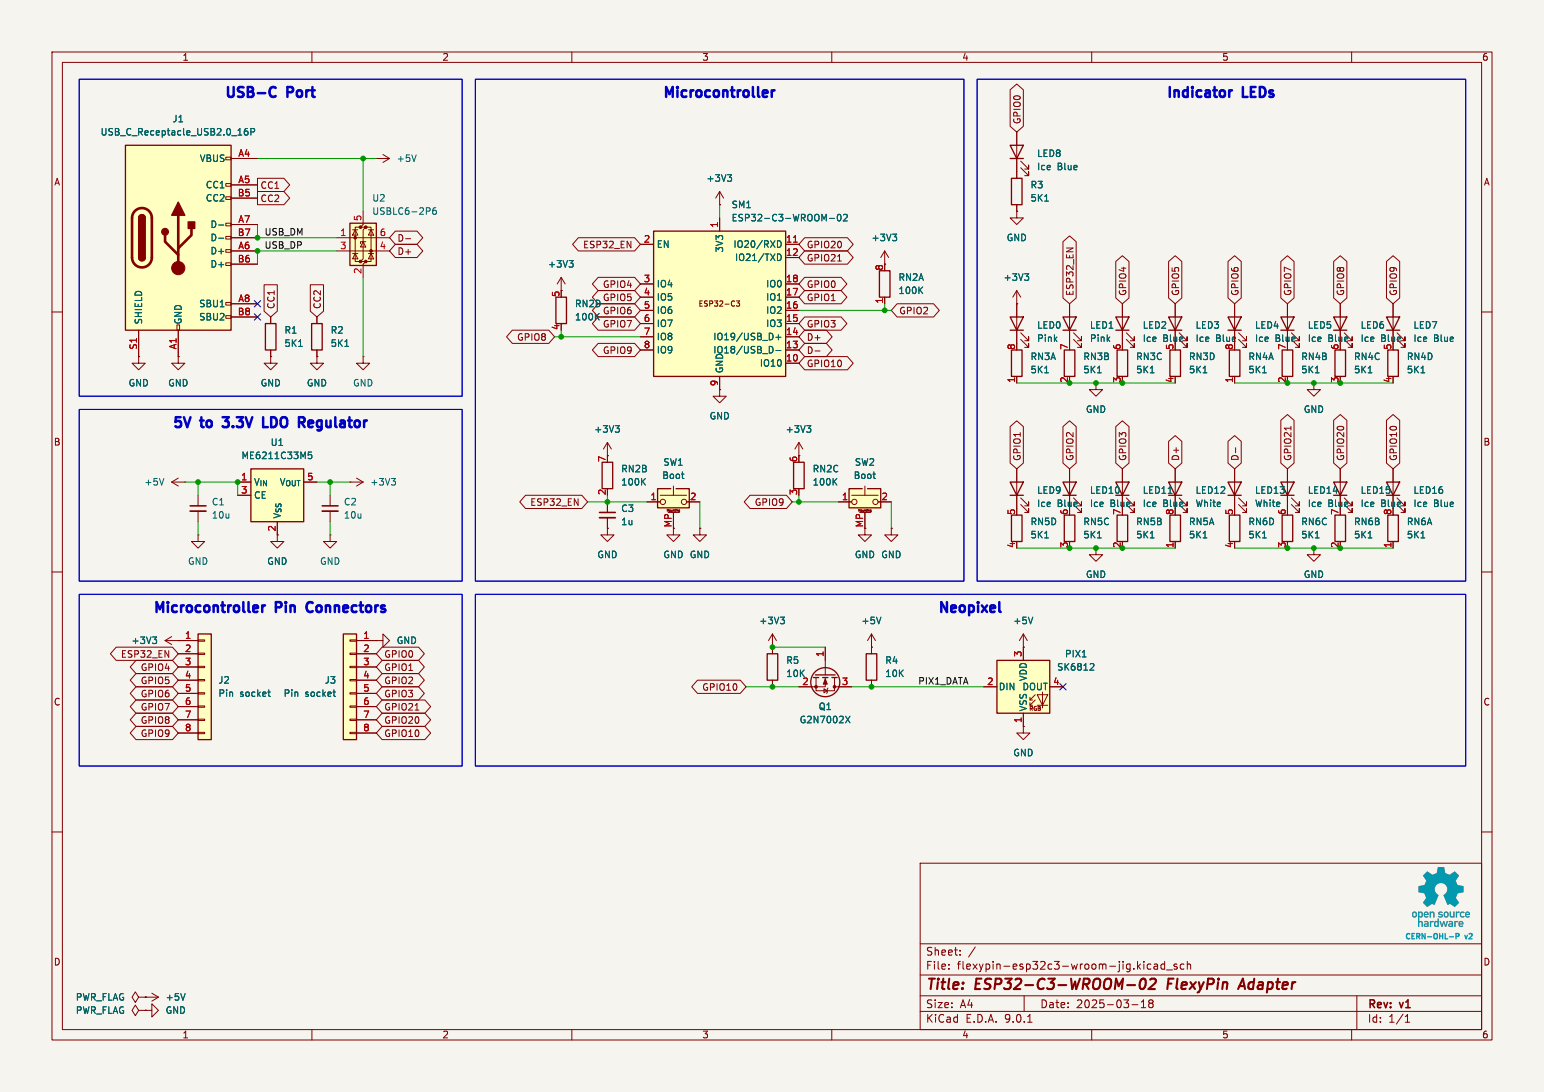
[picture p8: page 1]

Ice Blue SM1 ESP32-C3-WROOM-02 EN 2

Ice Blue GND GND GND

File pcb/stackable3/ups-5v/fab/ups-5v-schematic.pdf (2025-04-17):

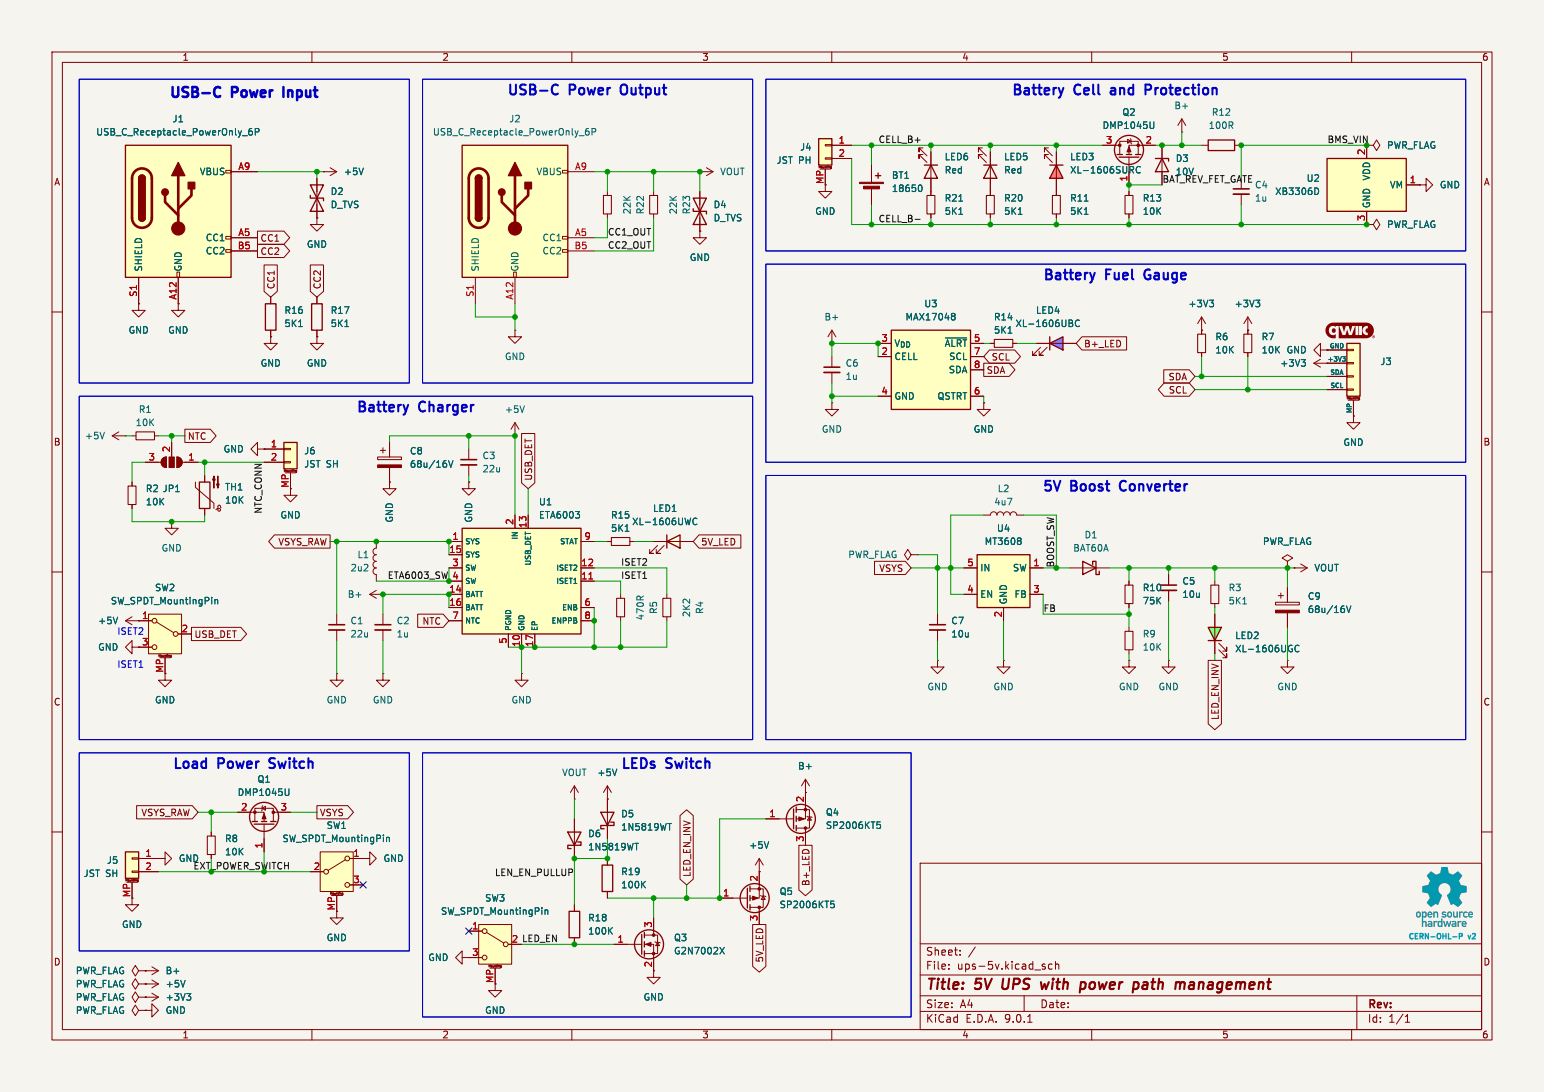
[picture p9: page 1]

Battery Cell and Protection

Id: 1/1 Title: 5V UPS with power path management File: ups-5v.kicad_sch Sheet: /

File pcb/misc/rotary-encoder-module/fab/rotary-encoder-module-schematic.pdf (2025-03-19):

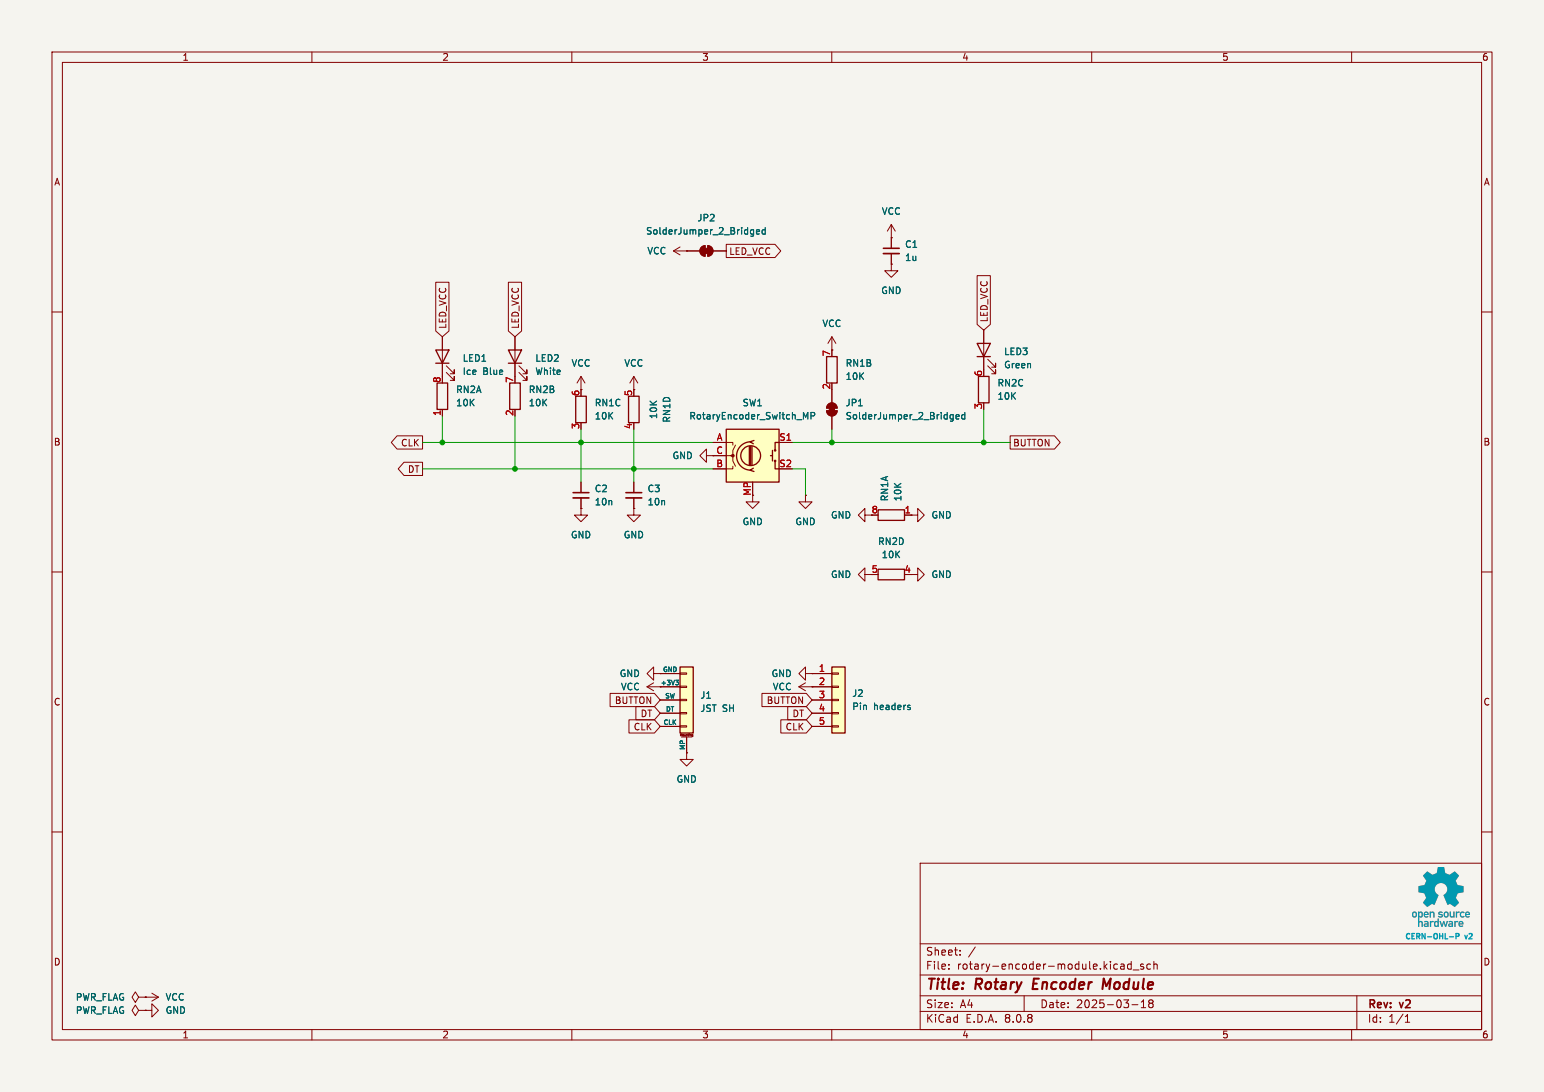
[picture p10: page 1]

Id: 1/1 Title: Rotary Encoder Module

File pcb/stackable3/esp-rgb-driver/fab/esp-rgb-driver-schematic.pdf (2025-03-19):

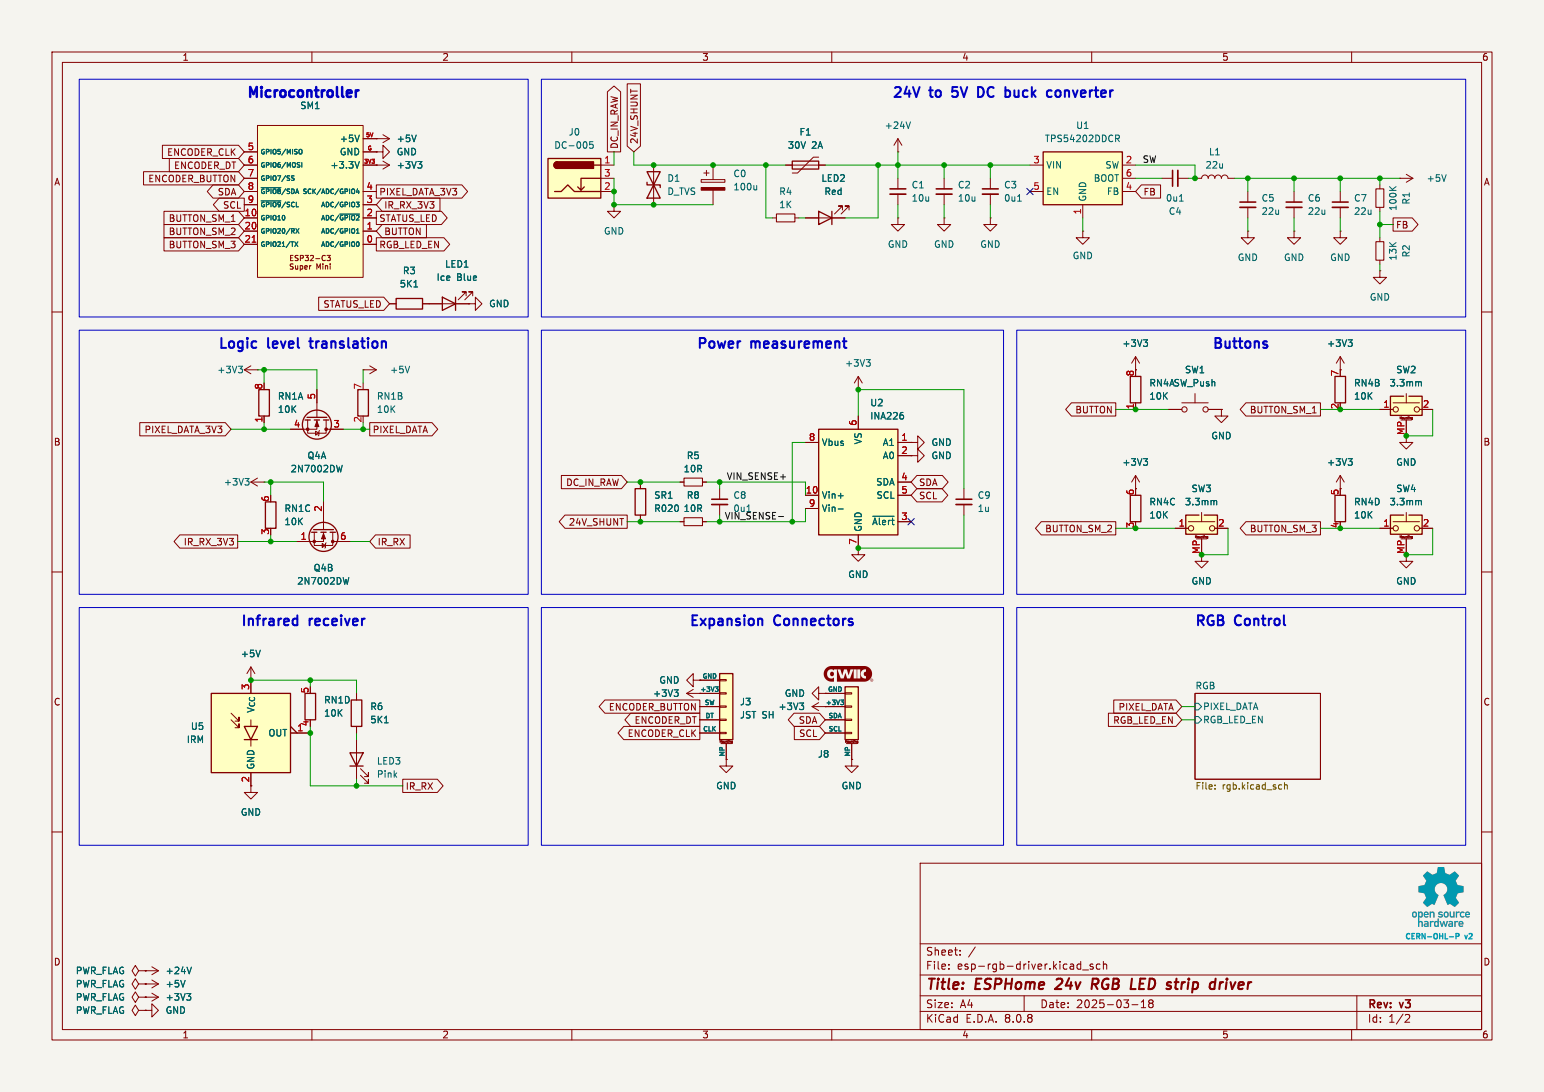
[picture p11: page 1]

24V to 5V DC buck converter F1
10u GND GND

1 SW 2 VIN 3 FB 4 EN 5 BOOT 6 U1 TPS54202DDCR GND
1uGND GND

7 Vbus 8 Vin- 9 +3V3 GND GND GND

DT CLK MP GND

JST SH OUT 1 GND

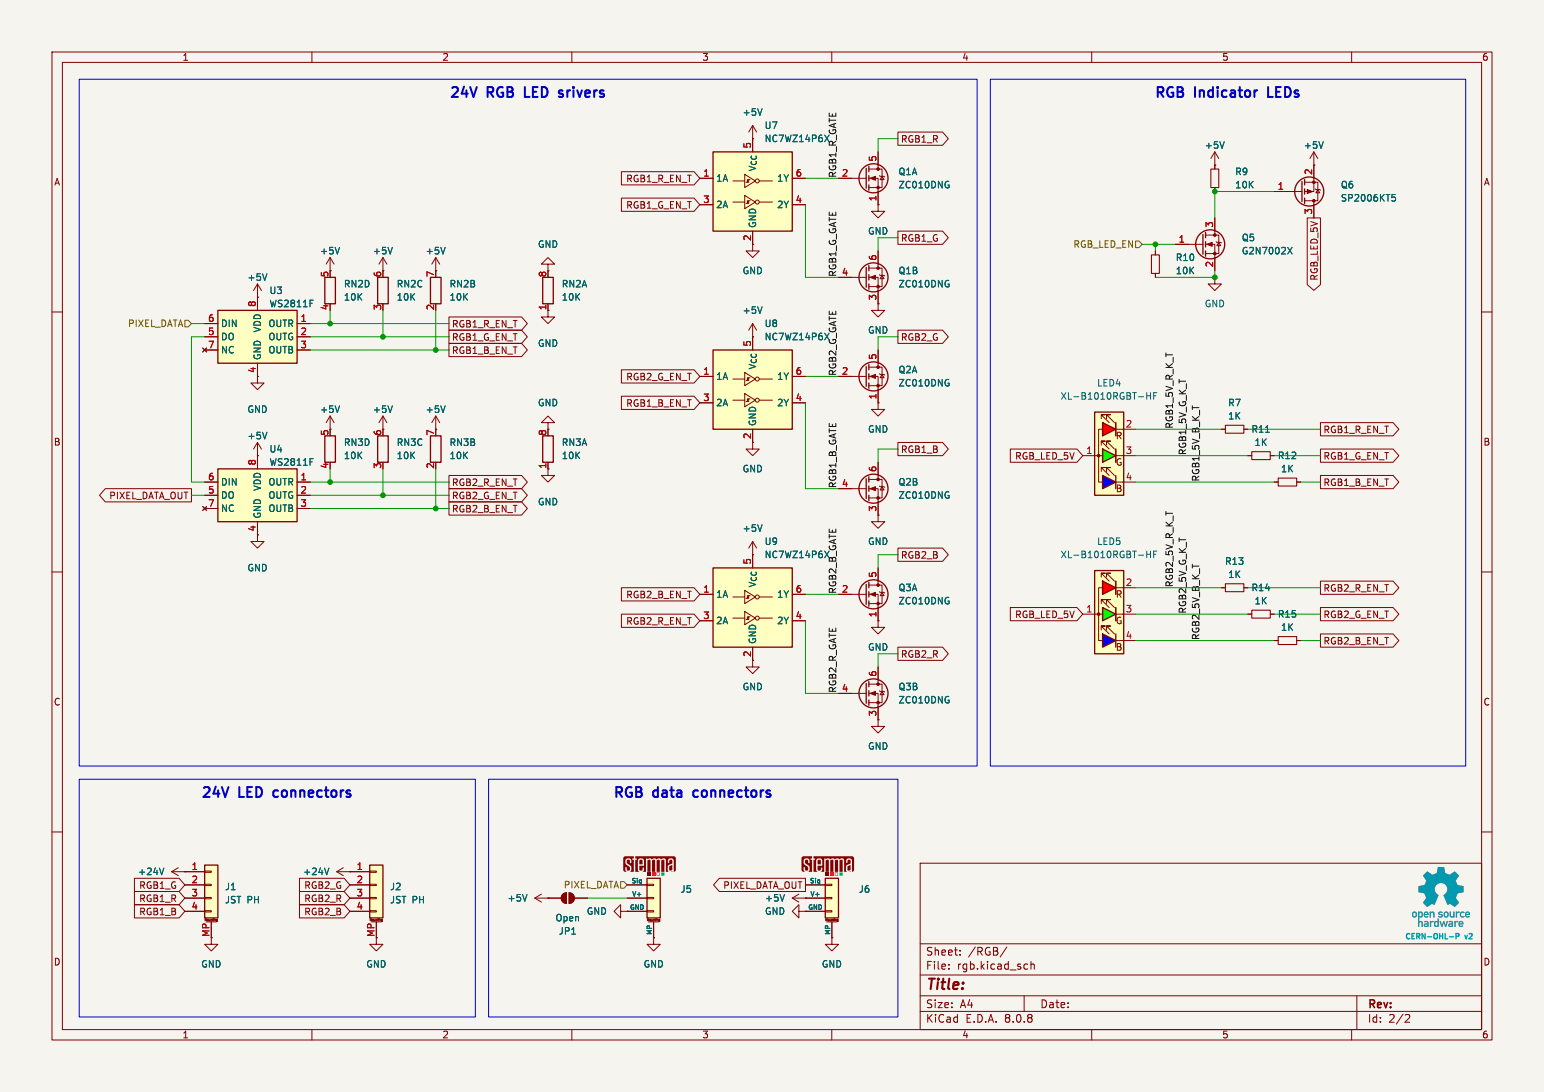
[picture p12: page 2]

2 7 U3 WS2811F OUTR 1 OUTG 2 OUTB 3 GND

4 DO 5 DIN 6 NC 7 VDD

Sig V+ GND MP GND

Id: 2/2 Title: File: rgb.kicad_sch Sheet: /RGB/

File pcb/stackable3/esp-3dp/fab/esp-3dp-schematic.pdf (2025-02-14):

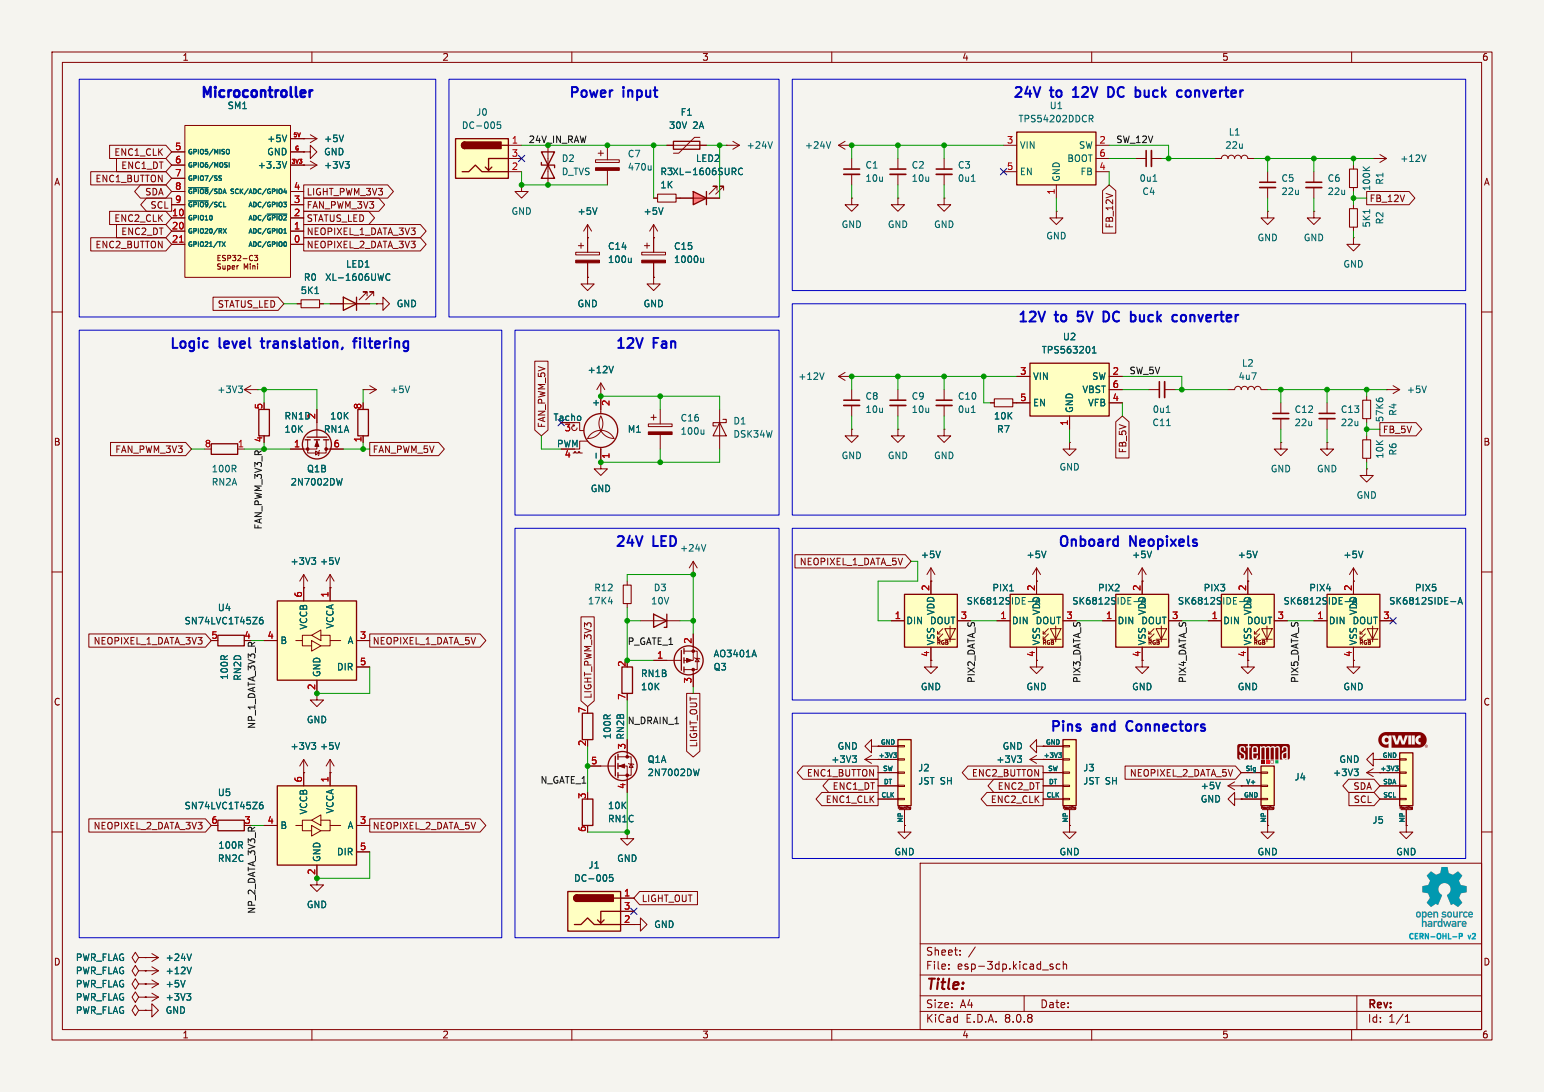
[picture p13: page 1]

1 SW 2 VIN 3 FB 4 EN 5 BOOT 6 U1 TPS54202DDCR

1 SW 2 VIN 3 VFB 4 EN 5 VBST 6 U2 TPS563201 GND

12V to 5V DC buck converter

1 SW 2 VIN 3 VFB 4 EN 5 VBST 6 +5V +5V R7
NEOPIXEL_2_DATA_5V FB_5V

Id: 1/1 Title: File: esp-3dp.kicad_sch Sheet: /

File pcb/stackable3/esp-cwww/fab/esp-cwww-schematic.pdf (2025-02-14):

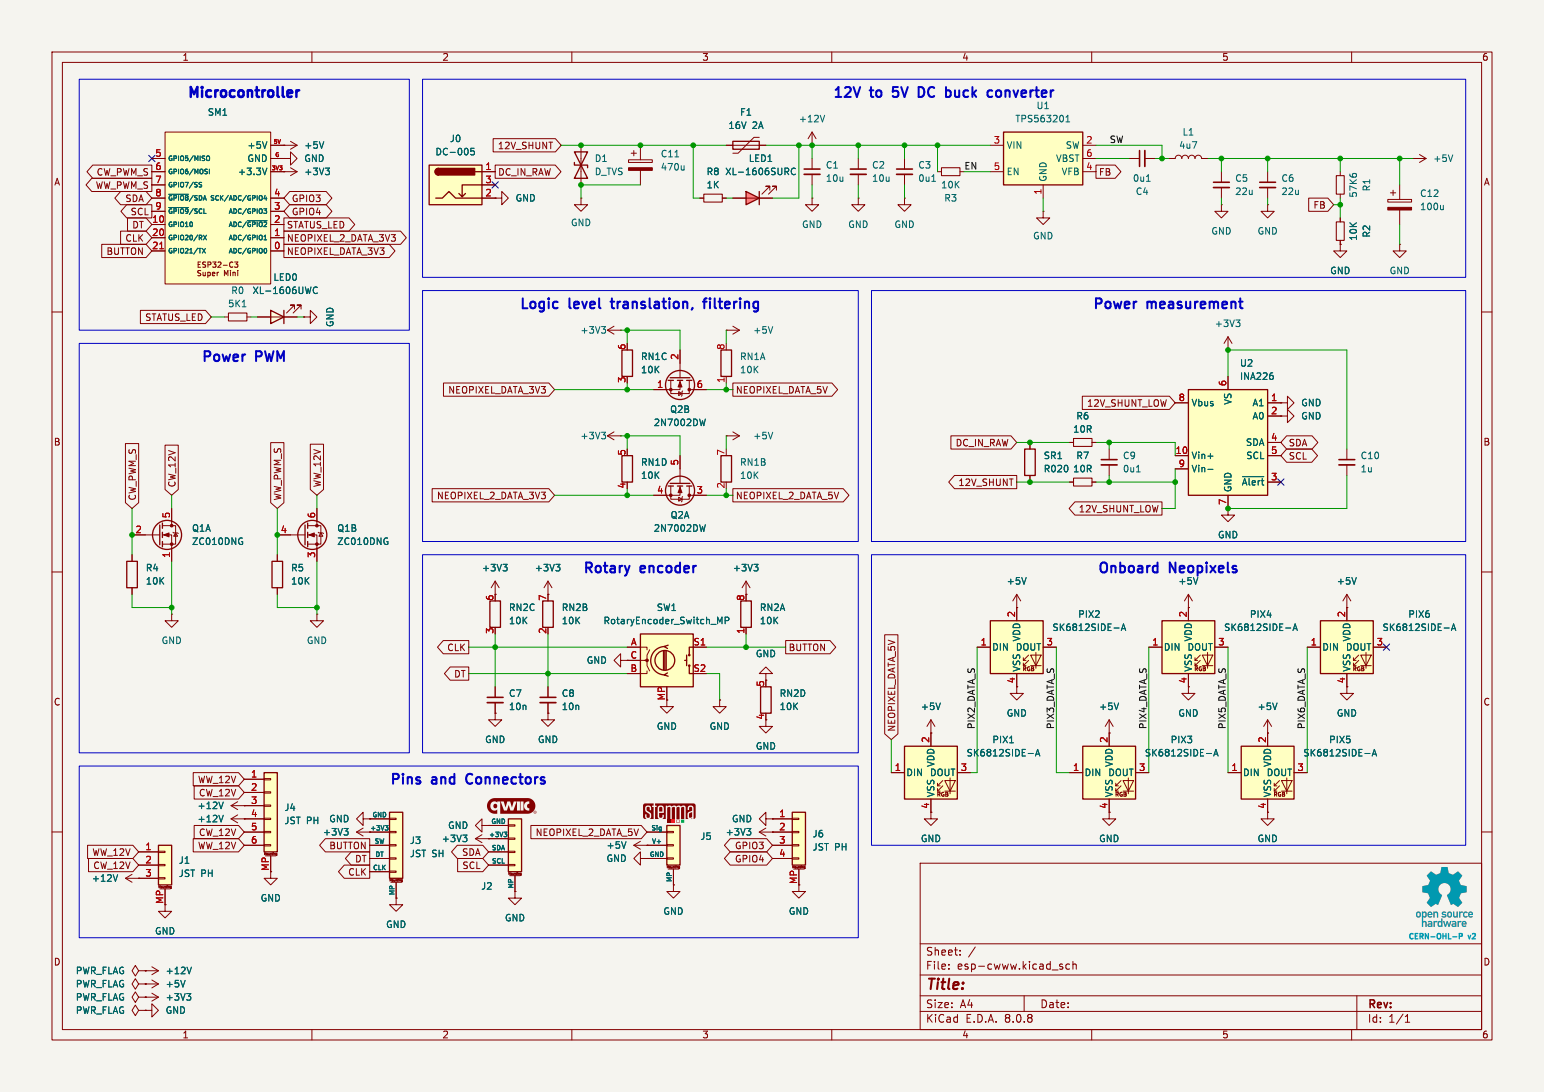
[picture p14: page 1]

12V to 5V DC buck converter

1 SW 2 VIN 3 VFB 4 EN 5 VBST 6 U1 TPS563201 GND

GND GND GND R2 10K GND

Id: 1/1 Title: File: esp-cwww.kicad_sch Sheet: / R5

4 5 GND GND GND GND

4 MP GND GND
Sig V+ GND MP GND

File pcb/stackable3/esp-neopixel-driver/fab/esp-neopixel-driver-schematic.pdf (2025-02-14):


DT CLK MP GND

Id: 1/1 Title: File: esp-neopixel-driver.kicad_sch Sheet: /

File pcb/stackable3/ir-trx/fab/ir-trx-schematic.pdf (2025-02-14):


Id: 1/1 Title: File: ir-trx.kicad_sch Sheet: / VCC

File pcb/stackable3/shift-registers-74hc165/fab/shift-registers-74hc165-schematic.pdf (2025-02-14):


Id: 1/1 Title: File: shift-registers-74hc165.kicad_sch Sheet: /

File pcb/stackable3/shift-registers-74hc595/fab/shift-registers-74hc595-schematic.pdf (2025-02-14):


File: shift-registers-74hc595.kicad_sch Sheet: /
Id: 1/1 Title: Shift Registers 74HC595


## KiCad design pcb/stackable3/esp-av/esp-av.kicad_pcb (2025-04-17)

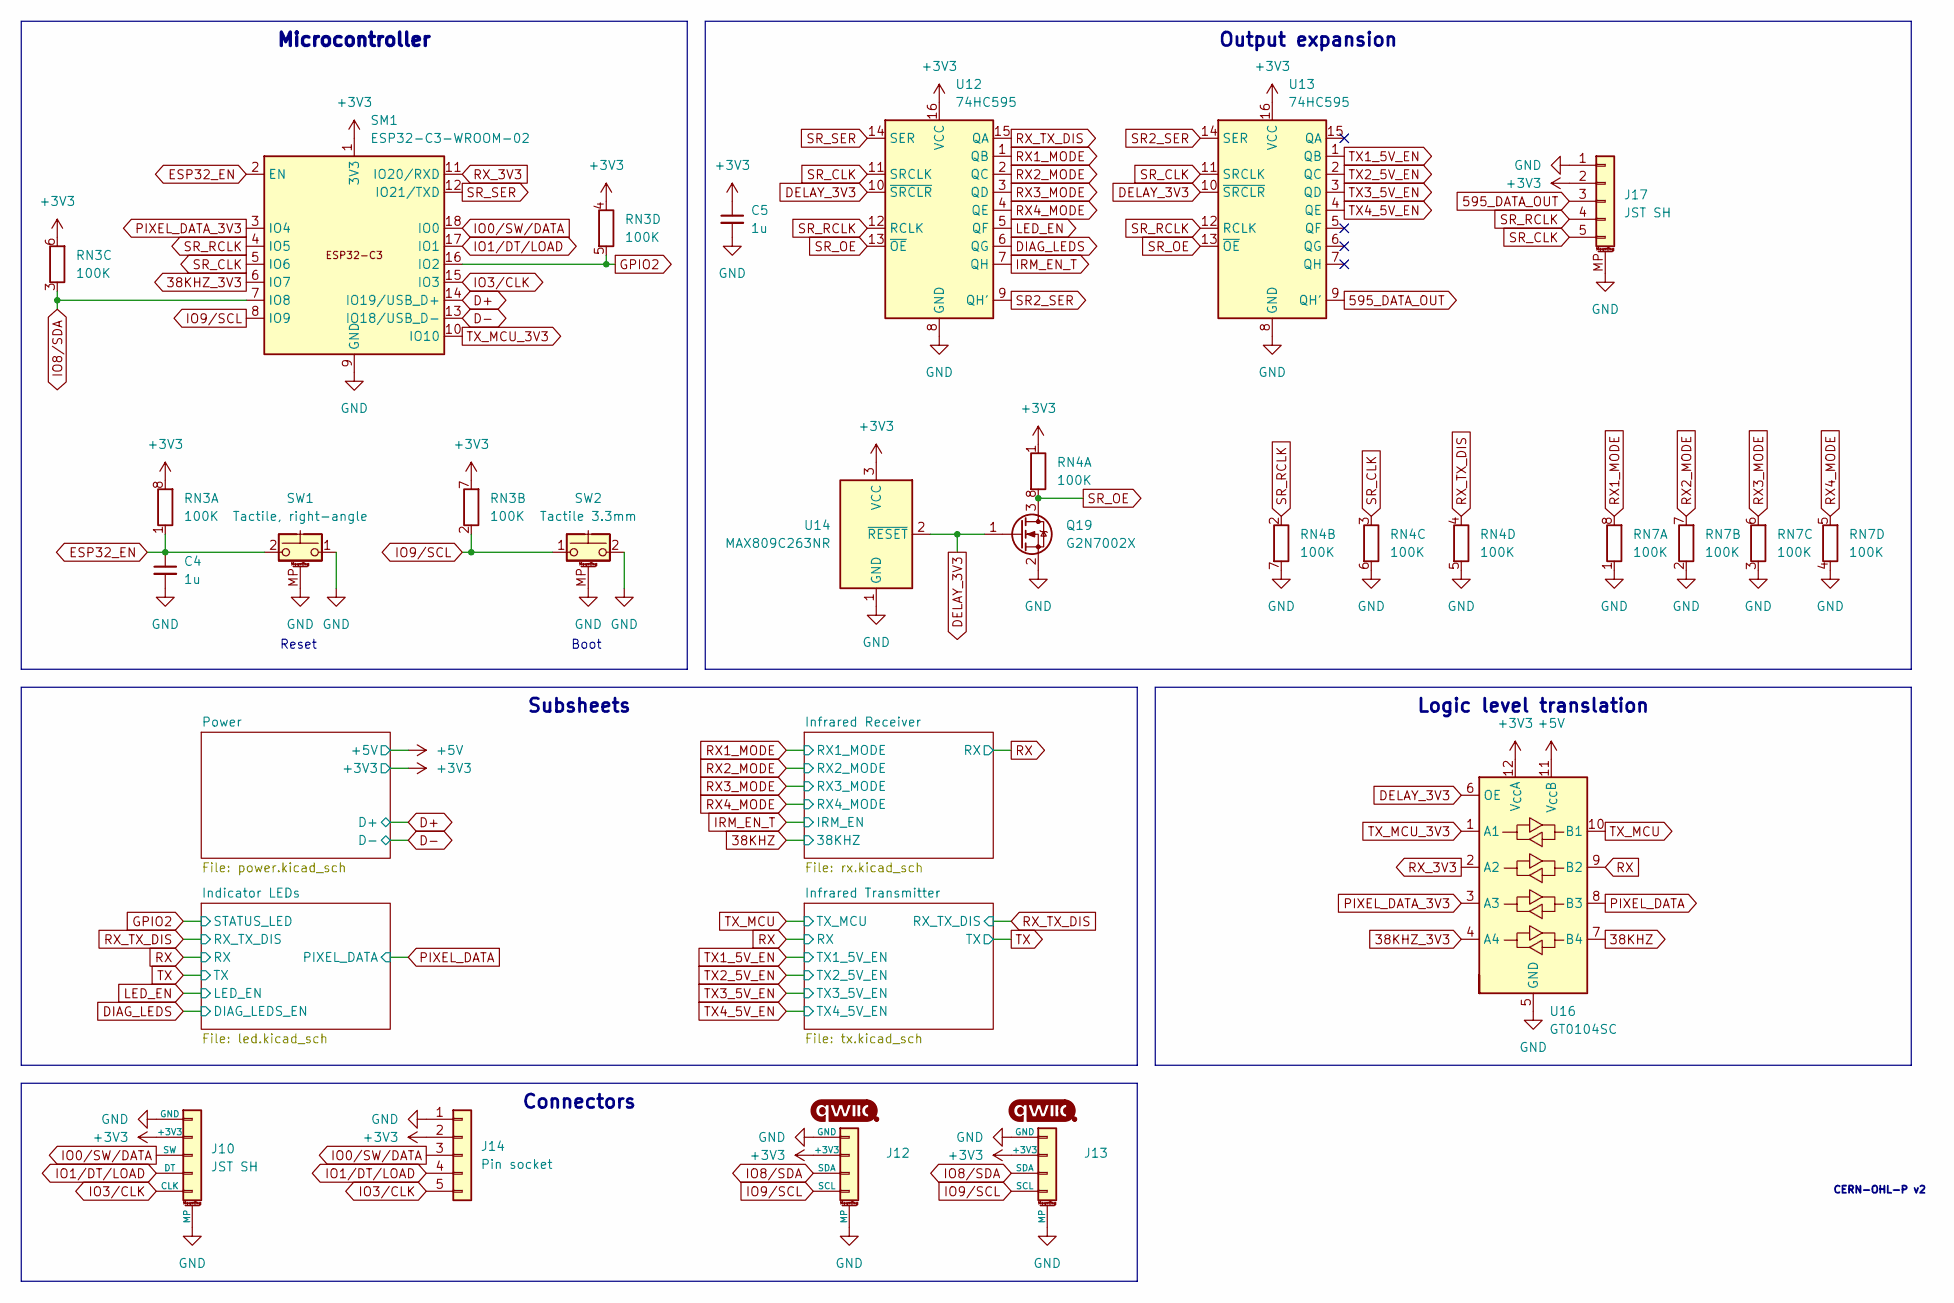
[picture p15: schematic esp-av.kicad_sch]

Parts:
C4, C5: 1u; C_0603_1608Metric; LCSC Part C5199872
J10, J17: JST SH; JST_SH_SM05B-SRSS-TB_1x05-1MP_P1.00mm_Horizontal; LCSC Part C7433426
J12: Qwiic; Qwiic-SMD-horizontal-logo-bottom-pinout; LCSC Part C19270571
J13: Qwiic; Qwiic-SMD-vertical; LCSC Part C27636912
J14: Pin socket; PinSocket_1x05_P2.54mm_Vertical
Q19: G2N7002X; SOT-523; LCSC Part C5258971
RN3, RN4, RN7: 100K; R_Array_Convex_4x0603; LCSC Part C110374
SM1: ESP32-C3-WROOM-02
SW1: Tactile, right-angle; SW_Push_1P1T-MP_NO_4.6x3mm_Horizontal; LCSC Part C2888932
SW2: Tactile 3.3mm; SW_Push_1P1T_NO_3.3x3.3mm_MP
U12, U13: 74HC595; SOIC-16_3.9x9.9mm_P1.27mm
U14: MAX809C263NR; SOT-23; LCSC Part C5223646
U16: GT0104SC; QFN-12-1EP_2x2mm_P0.4mm_EP1.1x1.1mm; LCSC Part C22356898

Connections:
38KHZ: U16.7 (B4); also elsewhere on the board
38KHZ_3V3: SM1.6 (IO7), U16.4 (A4)
595_DATA_OUT: J17.3, U13.9 (QH')
+3V3: C5.1, J10.2 (+3V3), J12.2 (+3V3), J13.2 (+3V3), J14.2, J17.2, RN3.4 (R4.1), RN3.6 (R3.2), RN3.7 (R2.2), RN3.8 (R1.2), RN4.1 (R1.1), SM1.1 (3V3), U12.16 (VCC), U13.16 (VCC), U14.3 (VCC), U16.12 (V_{CC}A); also elsewhere on the board
+5V: U16.11 (V_{CC}B); also elsewhere on the board
D+: SM1.14 (IO19/USB_D+); also elsewhere on the board
D-: SM1.13 (IO18/USB_D-); also elsewhere on the board
DELAY_3V3: Q19.1 (G), U12.10 (~SRCLR), U13.10 (~SRCLR), U14.2 (~RESET), U16.6 (OE)
DIAG_LEDS: U12.6 (QG); also elsewhere on the board
ESP32_EN: C4.1, RN3.1 (R1.1), SM1.2 (EN), SW1.2
GND: C4.2, C5.2, J10.1 (GND), J10.MP, J12.1 (GND), J12.MP, J13.1 (GND), J13.MP, J14.1, J17.1, J17.MP (MountPin), Q19.2 (S), RN4.5 (R4.2), RN4.6 (R3.2), RN4.7 (R2.2), RN7.1 (R1.1), RN7.2 (R2.1), RN7.3 (R3.1), RN7.4 (R4.1), SM1.9 (GND), SM1.19 (GND), SW1.1, SW1.MP (MountPin), SW2.2, SW2.MP (MountPin), U12.8 (GND), U13.8 (GND), U14.1 (GND), U16.5 (GND), U16.13 (Pad); also elsewhere on the board
GPIO2: RN3.5 (R4.2), SM1.16 (IO2); also elsewhere on the board
IO0/SW/DATA: J10.3 (SW), J14.3, SM1.18 (IO0)
IO1/DT/LOAD: J10.4 (DT), J14.4, SM1.17 (IO1)
IO3/CLK: J10.5 (CLK), J14.5, SM1.15 (IO3)
IO8/SDA: J12.3 (SDA), J13.3 (SDA), RN3.3 (R3.1), SM1.7 (IO8)
IO9/SCL: J12.4 (SCL), J13.4 (SCL), RN3.2 (R2.1), SM1.8 (IO9), SW2.1
IRM_EN_T: U12.7 (QH); also elsewhere on the board
LED_EN: U12.5 (QF); also elsewhere on the board
PIXEL_DATA: U16.8 (B3); also elsewhere on the board
PIXEL_DATA_3V3: SM1.3 (IO4), U16.3 (A3)
RX: U16.9 (B2); also elsewhere on the board
RX1_MODE: RN7.8 (R1.2), U12.1 (QB); also elsewhere on the board
RX2_MODE: RN7.7 (R2.2), U12.2 (QC); also elsewhere on the board
RX3_MODE: RN7.6 (R3.2), U12.3 (QD); also elsewhere on the board
RX4_MODE: RN7.5 (R4.2), U12.4 (QE); also elsewhere on the board
RX_3V3: SM1.11 (IO20/RXD), U16.2 (A2)
RX_TX_DIS: RN4.4 (R4.1), U12.15 (QA); also elsewhere on the board
SR2_SER: U12.9 (QH'), U13.14 (SER)
SR_CLK: J17.5, RN4.3 (R3.1), SM1.5 (IO6), U12.11 (SRCLK), U13.11 (SRCLK)
SR_OE: Q19.3 (D), RN4.8 (R1.2), U12.13 (~OE), U13.13 (~OE)
SR_RCLK: J17.4, RN4.2 (R2.1), SM1.4 (IO5), U12.12 (RCLK), U13.12 (RCLK)
SR_SER: SM1.12 (IO21/TXD), U12.14 (SER)
TX1_5V_EN: U13.1 (QB); also elsewhere on the board
TX2_5V_EN: U13.2 (QC); also elsewhere on the board
TX3_5V_EN: U13.3 (QD); also elsewhere on the board
TX4_5V_EN: U13.4 (QE); also elsewhere on the board
TX_MCU: U16.10 (B1); also elsewhere on the board
TX_MCU_3V3: SM1.10 (IO10), U16.1 (A1)

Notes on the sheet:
Boot
CERN-OHL-P v2
Reset
Connectors
Output expansion
Subsheets
Logic level translation
Microcontroller

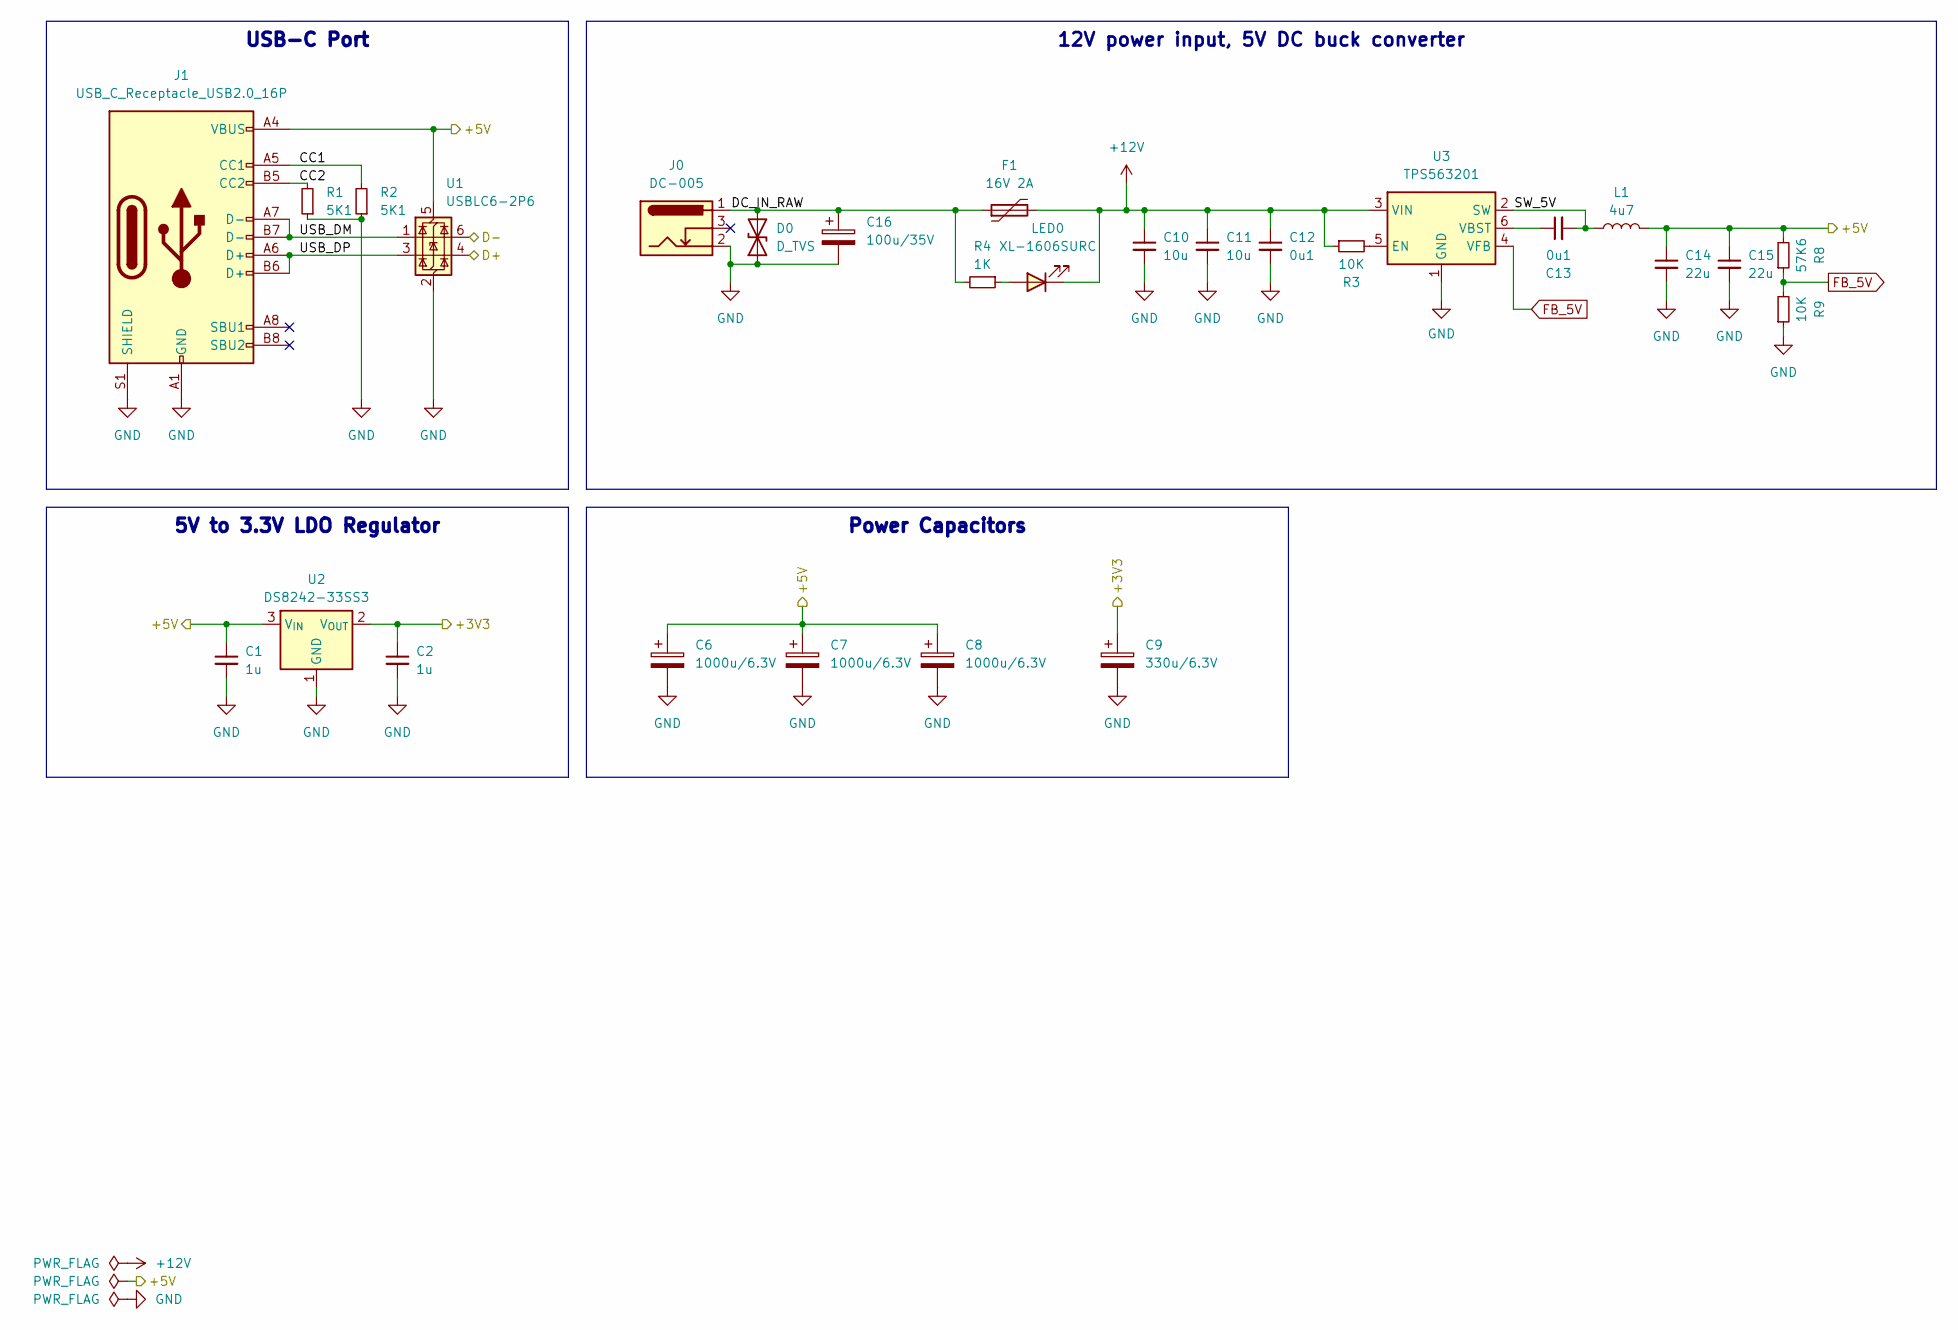
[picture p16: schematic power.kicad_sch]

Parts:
C1, C2: 1u; C_0603_1608Metric; LCSC Part C5199872
C6, C7, C8: 1000u/6.3V; CP_Radial_D8.0mm_P3.50mm; LCSC Part C5379966
C9: 330u/6.3V; CP_Radial_D5.0mm_P2.00mm; LCSC Part C217541
C10, C11: 10u; C_0603_1608Metric; LCSC Part C22367825
C12, C13: 0u1; C_0603_1608Metric; LCSC Part C14663
C14, C15: 22u; C_0603_1608Metric; LCSC Part C86295
C16: 100u/35V; CP_Radial_D6.3mm_P2.50mm; LCSC Part C5379947
D0: D_TVS; D_SOD-123F; LCSC Part C7473216
F1: 16V 2A; Fuse_1206_3216Metric; LCSC Part C2982271
J0: DC-005; BarrelJack_DC-005_THT_Horizontal
J1: USB_C_Receptacle_USB2.0_16P; USB_C_Receptacle_GCT_USB4105-xx-A_16P_TopMnt_Horizontal; LCSC Part C2765186
L1: 4u7; L_1008_2520Metric; LCSC Part C22471106
LED0: XL-1606SURC; LED_SideEmitter_1.7x1.1mm; LCSC Part C965860
R1, R2: 5K1; R_0603_1608Metric; LCSC Part C23186
R3, R9: 10K; R_0603_1608Metric; LCSC Part C25804
R4: 1K; R_0603_1608Metric; LCSC Part C21190
R8: 57K6; R_0603_1608Metric; LCSC Part C23082
U1: USBLC6-2P6; SOT-666; LCSC Part C29780639
U2: DS8242-33SS3; SOT-23; LCSC Part C5884134
U3: TPS563201; SOT-23-6; LCSC Part C116592

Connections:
+3V3: C2.1, C9.1, U2.2 (V_{OUT}); also elsewhere on the board
+5V: C1.1, C6.1, C7.1, C8.1, C14.1, C15.1, J1.A4 (VBUS), J1.A9 (VBUS), J1.B4 (VBUS), J1.B9 (VBUS), L1.2, R8.2, U1.5 (VBUS), U2.3 (V_{IN}); also elsewhere on the board
+12V: C10.1, C11.1, C12.1, F1.2, LED0.1 (K), R3.1, U3.3 (VIN)
/Power/CC1: J1.A5 (CC1), R2.2
/Power/CC2: J1.B5 (CC2), R1.2
/Power/DC_IN_RAW: C16.1, D0.2 (A2), F1.1, J0.1, R4.2
/Power/SW_5V: C13.2, L1.1, U3.2 (SW)
/Power/USB_DM: J1.A7 (D-), J1.B7 (D-), U1.1 (I/O1)
/Power/USB_DP: J1.A6 (D+), J1.B6 (D+), U1.3 (I/O2)
D+: U1.4 (I/O2); also elsewhere on the board
D-: U1.6 (I/O1); also elsewhere on the board
FB_5V: R8.1, R9.2, U3.4 (VFB)
GND: C1.2, C2.2, C6.2, C7.2, C8.2, C9.2, C10.2, C11.2, C12.2, C14.2, C15.2, C16.2, D0.1 (A1), J0.2, J1.A1 (GND), J1.A12 (GND), J1.B1 (GND), J1.B12 (GND), J1.S1 (SHIELD), R1.1, R2.1, R9.1, U1.2 (GND), U2.1 (GND), U3.1 (GND); also elsewhere on the board
unnamed: LED0.2 (A), R4.1
unnamed: R3.2, U3.5 (EN)
unnamed: C13.1, U3.6 (VBST)

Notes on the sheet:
12V power input, 5V DC buck converter
Power Capacitors
USB-C Port
5V to 3.3V LDO Regulator

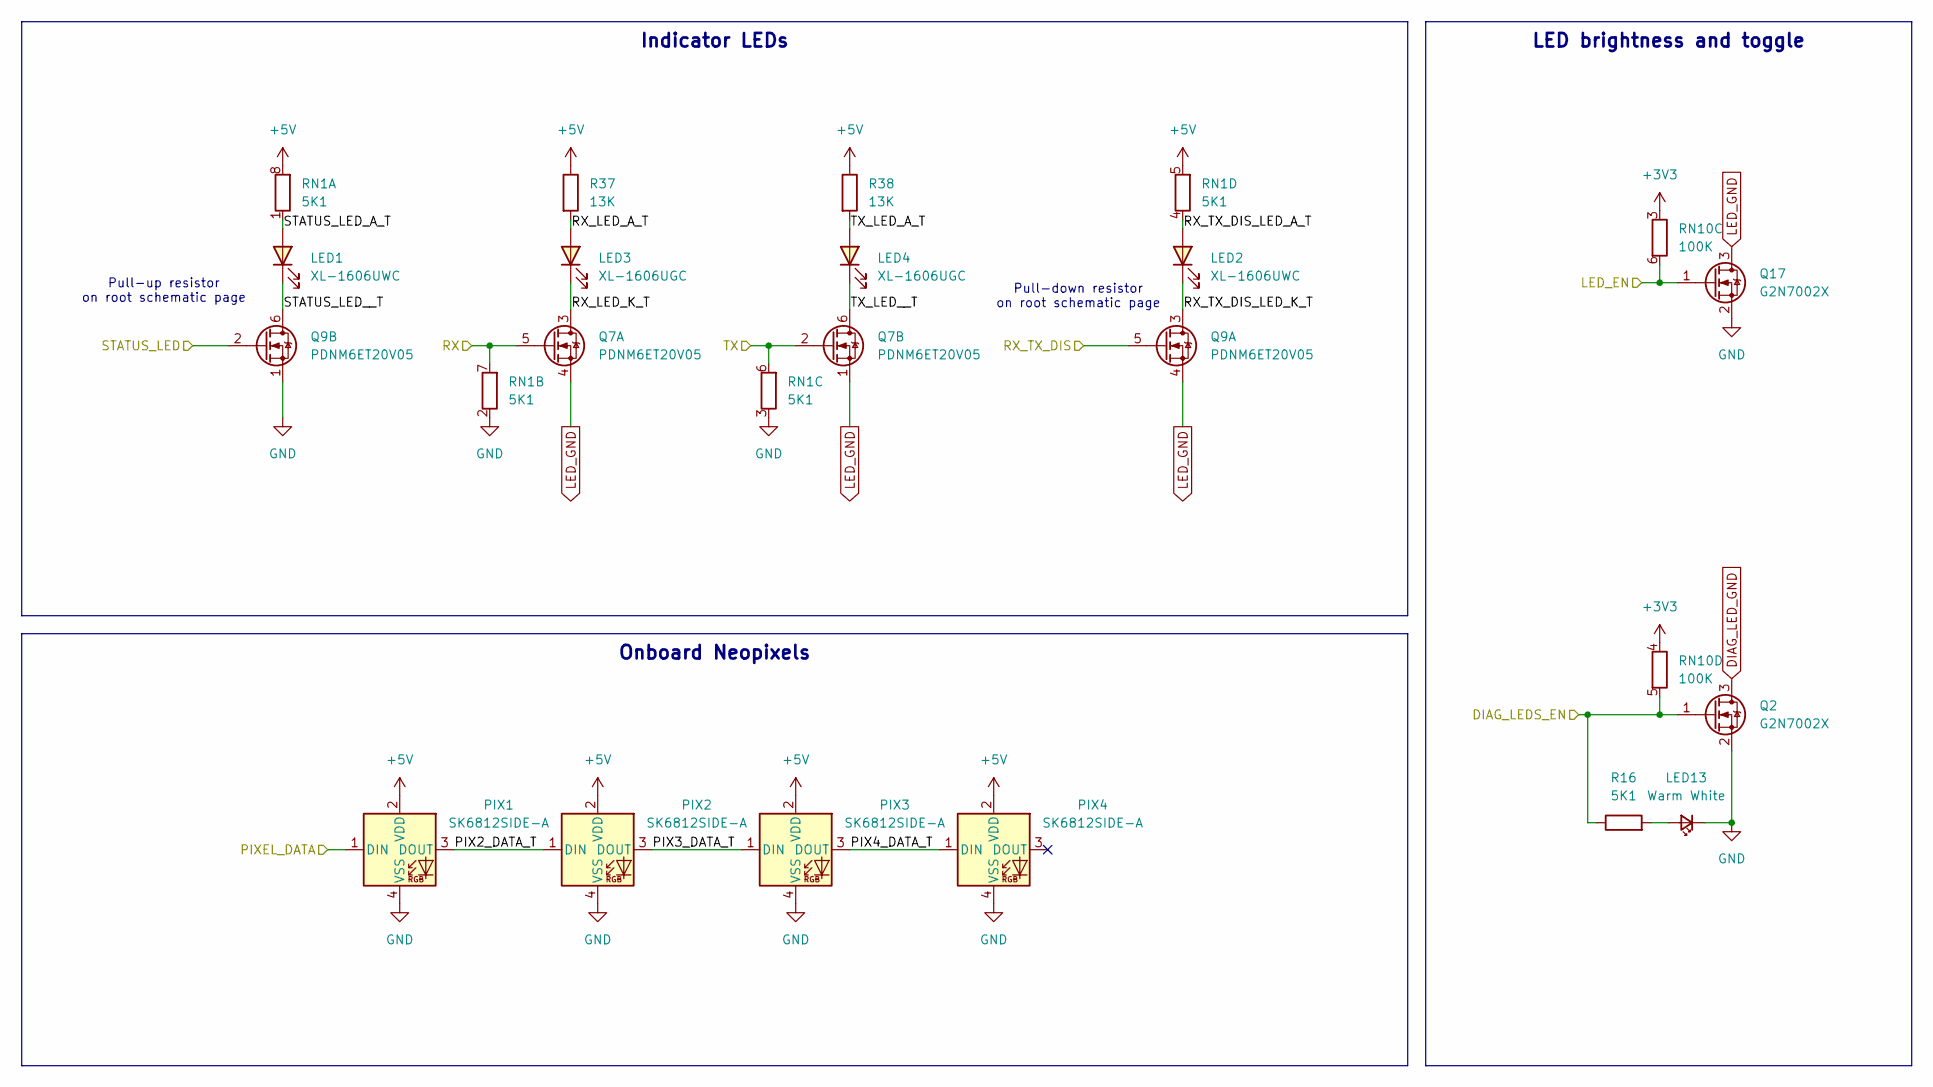
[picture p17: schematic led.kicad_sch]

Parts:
LED1, LED2: XL-1606UWC; LED_SideEmitter_1.7x1.1mm; LCSC Part C965866
LED3, LED4: XL-1606UGC; LED_SideEmitter_1.7x1.1mm; LCSC Part C965863
LED13: Warm White; LED_0603_1608Metric; LCSC Part C2827262
PIX1, PIX2, PIX3, PIX4: SK6812SIDE-A; LED_SK6812SIDE-A_4.0x1.6mm; LCSC Part C2890037
Q2, Q17: G2N7002X; SOT-523; LCSC Part C5258971
Q7, Q9: PDNM6ET20V05; SOT-563; LCSC Part C918811
R16: 5K1; R_0603_1608Metric; LCSC Part C23186
R37, R38: 13K; R_0603_1608Metric; LCSC Part C22797
RN1: 5K1; R_Array_Convex_4x0603; LCSC Part C711414
RN10: 100K; R_Array_Convex_4x0603; LCSC Part C110374

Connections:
+3V3: RN10.3 (R3.1), RN10.4 (R4.1); also elsewhere on the board
+5V: PIX1.2 (VDD), PIX2.2 (VDD), PIX3.2 (VDD), PIX4.2 (VDD), R37.1, R38.1, RN1.5 (R4.2), RN1.8 (R1.2); also elsewhere on the board
/Indicator LEDs/PIX2_DATA_T: PIX1.3 (DOUT), PIX2.1 (DIN)
/Indicator LEDs/PIX3_DATA_T: PIX2.3 (DOUT), PIX3.1 (DIN)
/Indicator LEDs/PIX4_DATA_T: PIX3.3 (DOUT), PIX4.1 (DIN)
/Indicator LEDs/RX_LED_A_T: LED3.2 (A), R37.2
/Indicator LEDs/RX_LED_K_T: LED3.1 (K), Q7.3 (D)
/Indicator LEDs/RX_TX_DIS_LED_A_T: LED2.2 (A), RN1.4 (R4.1)
/Indicator LEDs/RX_TX_DIS_LED_K_T: LED2.1 (K), Q9.3 (D)
/Indicator LEDs/STATUS_LED_A_T: LED1.2 (A), RN1.1 (R1.1)
/Indicator LEDs/STATUS_LED__T: LED1.1 (K), Q9.6 (D)
/Indicator LEDs/TX_LED_A_T: LED4.2 (A), R38.2
/Indicator LEDs/TX_LED__T: LED4.1 (K), Q7.6 (D)
DIAG_LEDS: Q2.1 (G), R16.1, RN10.5 (R4.2); also elsewhere on the board
DIAG_LED_GND: Q2.3 (D); also elsewhere on the board
GND: LED13.1 (K), PIX1.4 (VSS), PIX2.4 (VSS), PIX3.4 (VSS), PIX4.4 (VSS), Q2.2 (S), Q9.1 (S), Q17.2 (S), RN1.2 (R2.1), RN1.3 (R3.1); also elsewhere on the board
GPIO2: Q9.2 (G); also elsewhere on the board
LED_EN: Q17.1 (G), RN10.6 (R3.2); also elsewhere on the board
LED_GND: Q7.1 (S), Q7.4 (S), Q9.4 (S), Q17.3 (D)
unnamed: LED13.2 (A), R16.2
PIXEL_DATA: PIX1.1 (DIN); also elsewhere on the board
RX: Q7.5 (G), RN1.7 (R2.2); also elsewhere on the board
RX_TX_DIS: Q9.5 (G); also elsewhere on the board
TX: Q7.2 (G), RN1.6 (R3.2); also elsewhere on the board

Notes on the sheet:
Pull-up resistor on root schematic page
Pull-down resistor on root schematic page
LED brightness and toggle
Onboard Neopixels
Indicator LEDs

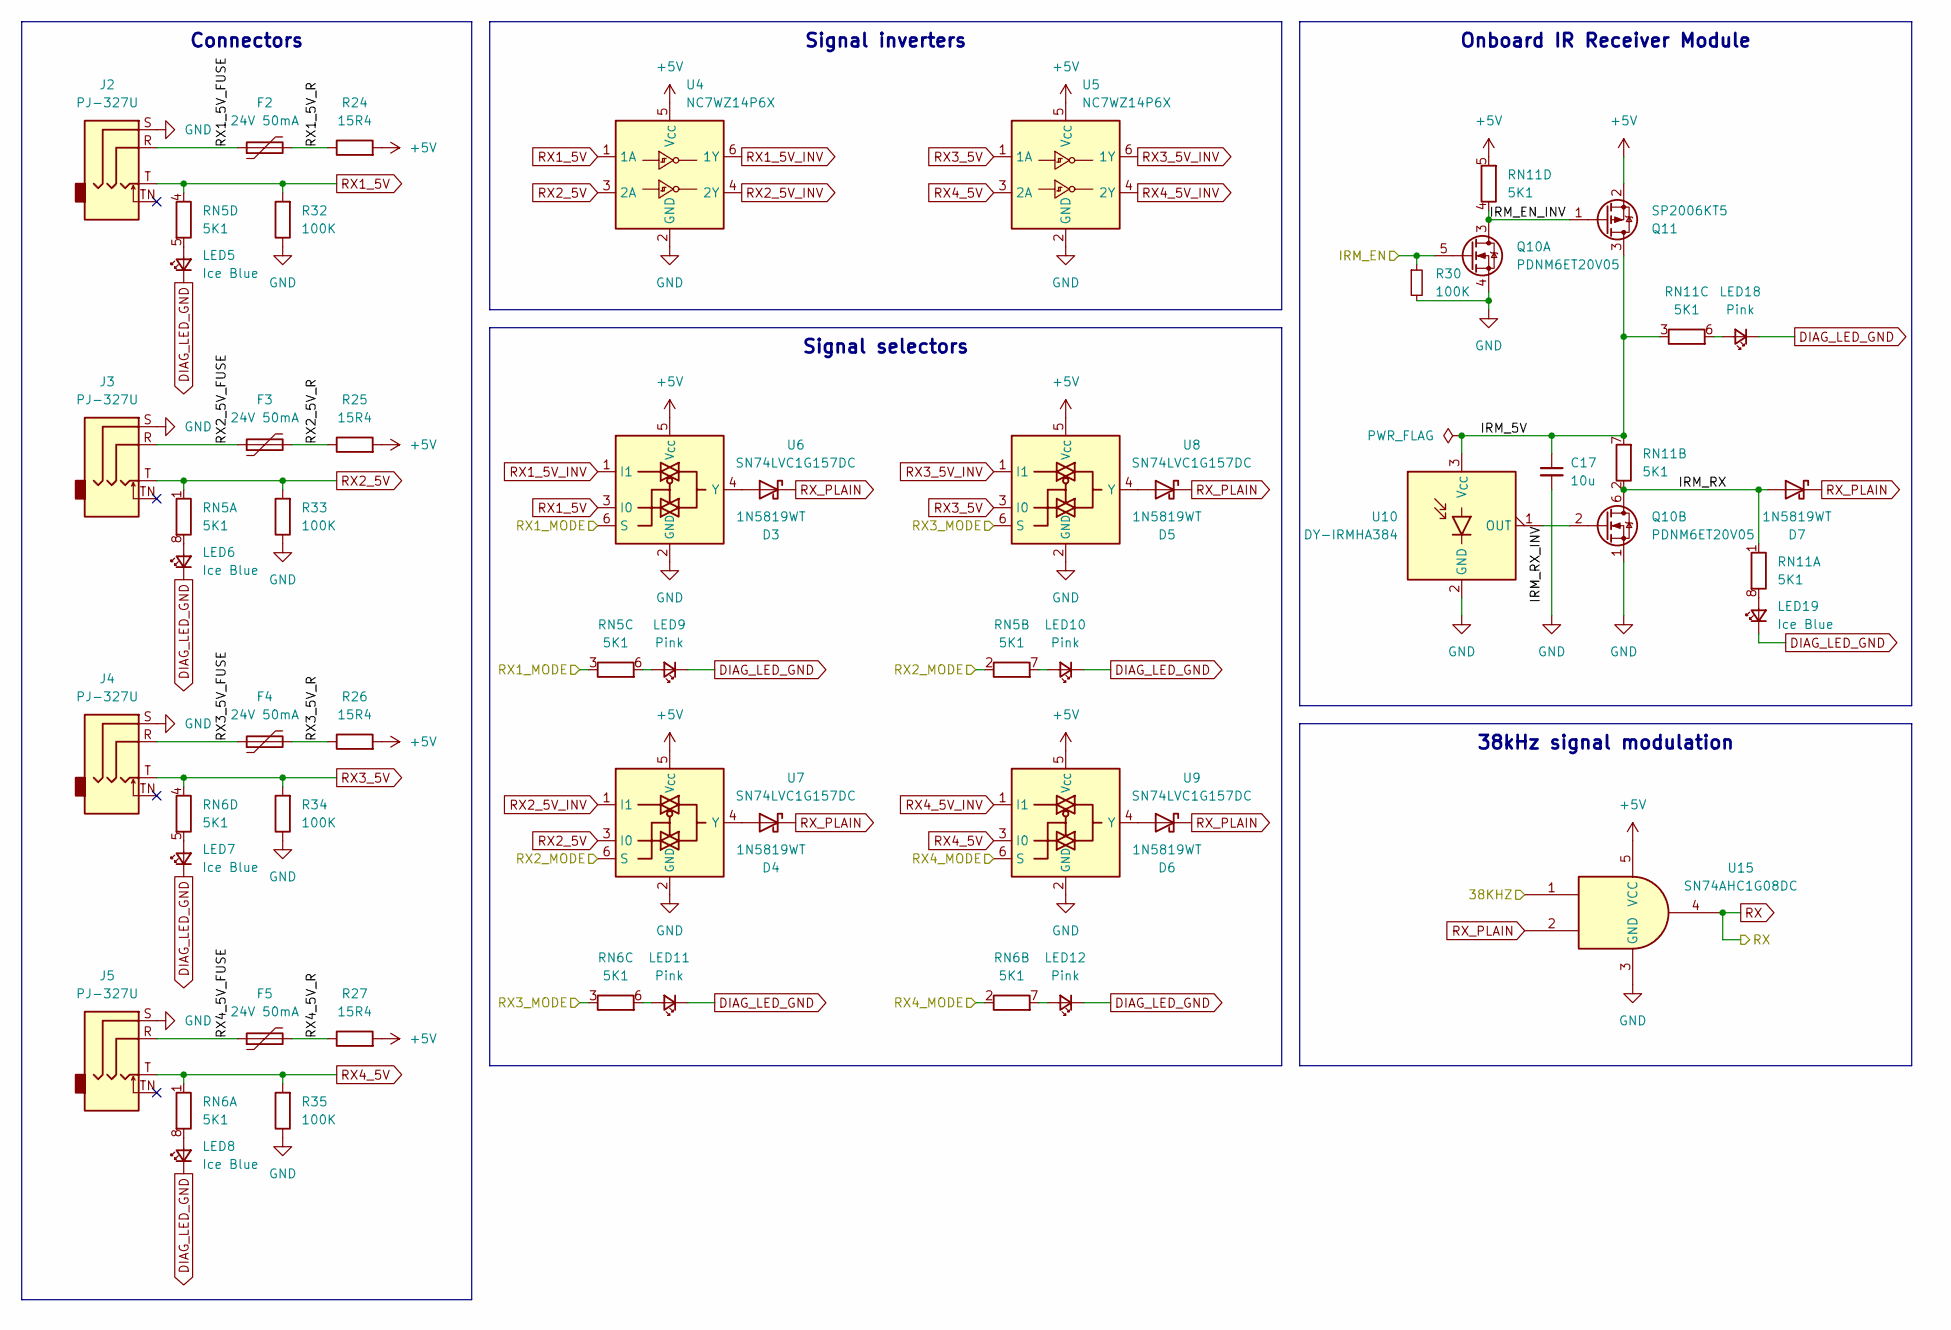
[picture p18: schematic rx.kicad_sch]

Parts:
C17: 10u; C_0603_1608Metric; LCSC Part C22367825
D3, D4, D5, D6, D7: 1N5819WT; D_SOD-523; LCSC Part C20754784
F2, F3, F4, F5: 24V 50mA; Fuse_0603_1608Metric; LCSC Part C369141
J2, J3, J4, J5: PJ-327U; Jack_3.5mm_PJ-327U-SMT_Horizontal; LCSC Part C397453
LED5, LED6, LED7, LED8, LED19: Ice Blue; LED_0603_1608Metric; LCSC Part C7496823
LED9, LED10, LED11, LED12, LED18: Pink; LED_0603_1608Metric; LCSC Part C7496826
Q10: PDNM6ET20V05; SOT-563; LCSC Part C918811
Q11: SP2006KT5; SOT-523; LCSC Part C41355141
R24, R25, R26, R27: 15R4; R_1206_3216Metric; LCSC Part C3013373
R30, R32, R33, R34, R35: 100K; R_0603_1608Metric; LCSC Part C25803
RN5, RN6, RN11: 5K1; R_Array_Convex_4x0603; LCSC Part C711414
U4, U5: NC7WZ14P6X; SOT-363_SC-70-6; LCSC Part C5207816
U6, U7, U8, U9: SN74LVC1G157DC; SOT-363_SC-70-6; LCSC Part C22469913
U10: DY-IRMHA384; IRM_5.0mmx4.2mm_P1.27mm_Horizontal; LCSC Part C6071554
U15: SN74AHC1G08DC; SOT-353_SC-70-5; LCSC Part C22469964

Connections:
38KHZ: U15.1; also elsewhere on the board
+5V: Q11.2 (S), R24.2, R25.2, R26.2, R27.2, RN11.5 (R4.2), U4.5 (V_{CC}), U5.5 (V_{CC}), U6.5 (V_{CC}), U7.5 (V_{CC}), U8.5 (V_{CC}), U9.5 (V_{CC}), U15.5 (VCC); also elsewhere on the board
/Infrared Receiver/IRM_5V: C17.1, Q11.3 (D), RN11.3 (R3.1), RN11.7 (R2.2), U10.3 (V_{CC})
/Infrared Receiver/IRM_EN_INV: Q10.3 (D), Q11.1 (G), RN11.4 (R4.1)
/Infrared Receiver/IRM_RX: D7.2 (A), Q10.6 (D), RN11.1 (R1.1), RN11.2 (R2.1)
/Infrared Receiver/IRM_RX_INV: Q10.2 (G), U10.1 (OUT)
/Infrared Receiver/RX1_5V_FUSE: F2.1, J2.R
/Infrared Receiver/RX1_5V_R: F2.2, R24.1
/Infrared Receiver/RX2_5V_FUSE: F3.1, J3.R
/Infrared Receiver/RX2_5V_R: F3.2, R25.1
/Infrared Receiver/RX3_5V_FUSE: F4.1, J4.R
/Infrared Receiver/RX3_5V_R: F4.2, R26.1
/Infrared Receiver/RX4_5V_FUSE: F5.1, J5.R
/Infrared Receiver/RX4_5V_R: F5.2, R27.1
DIAG_LED_GND: LED5.1 (K), LED6.1 (K), LED7.1 (K), LED8.1 (K), LED9.1 (K), LED10.1 (K), LED11.1 (K), LED12.1 (K), LED18.1 (K), LED19.1 (K); also elsewhere on the board
GND: C17.2, J2.S, J3.S, J4.S, J5.S, Q10.1 (S), Q10.4 (S), R30.2, R32.1, R33.1, R34.1, R35.1, U4.2 (GND), U5.2 (GND), U6.2 (GND), U7.2 (GND), U8.2 (GND), U9.2 (GND), U10.2 (GND), U15.3 (GND); also elsewhere on the board
IRM_EN_T: Q10.5 (G), R30.1; also elsewhere on the board
unnamed: D3.2 (A), U6.4 (Y)
unnamed: D4.2 (A), U7.4 (Y)
unnamed: D5.2 (A), U8.4 (Y)
unnamed: D6.2 (A), U9.4 (Y)
unnamed: LED5.2 (A), RN5.5 (R4.2)
unnamed: LED6.2 (A), RN5.8 (R1.2)
unnamed: LED7.2 (A), RN6.5 (R4.2)
unnamed: LED8.2 (A), RN6.8 (R1.2)
unnamed: LED9.2 (A), RN5.6 (R3.2)
unnamed: LED10.2 (A), RN5.7 (R2.2)
unnamed: LED11.2 (A), RN6.6 (R3.2)
unnamed: LED12.2 (A), RN6.7 (R2.2)
unnamed: LED18.2 (A), RN11.6 (R3.2)
unnamed: LED19.2 (A), RN11.8 (R1.2)
RX: U15.4; also elsewhere on the board
RX1_5V: J2.T, R32.2, RN5.4 (R4.1), U4.1 (1A), U6.3 (I0)
RX1_5V_INV: U4.6 (1Y), U6.1 (I1)
RX1_MODE: RN5.3 (R3.1), U6.6 (S); also elsewhere on the board
RX2_5V: J3.T, R33.2, RN5.1 (R1.1), U4.3 (2A), U7.3 (I0)
RX2_5V_INV: U4.4 (2Y), U7.1 (I1)
RX2_MODE: RN5.2 (R2.1), U7.6 (S); also elsewhere on the board
RX3_5V: J4.T, R34.2, RN6.4 (R4.1), U5.1 (1A), U8.3 (I0)
RX3_5V_INV: U5.6 (1Y), U8.1 (I1)
RX3_MODE: RN6.3 (R3.1), U8.6 (S); also elsewhere on the board
RX4_5V: J5.T, R35.2, RN6.1 (R1.1), U5.3 (2A), U9.3 (I0)
RX4_5V_INV: U5.4 (2Y), U9.1 (I1)
RX4_MODE: RN6.2 (R2.1), U9.6 (S); also elsewhere on the board
RX_PLAIN: D3.1 (K), D4.1 (K), D5.1 (K), D6.1 (K), D7.1 (K), U15.2

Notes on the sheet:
Signal inverters
Connectors
Onboard IR Receiver Module
38kHz signal modulation
Signal selectors

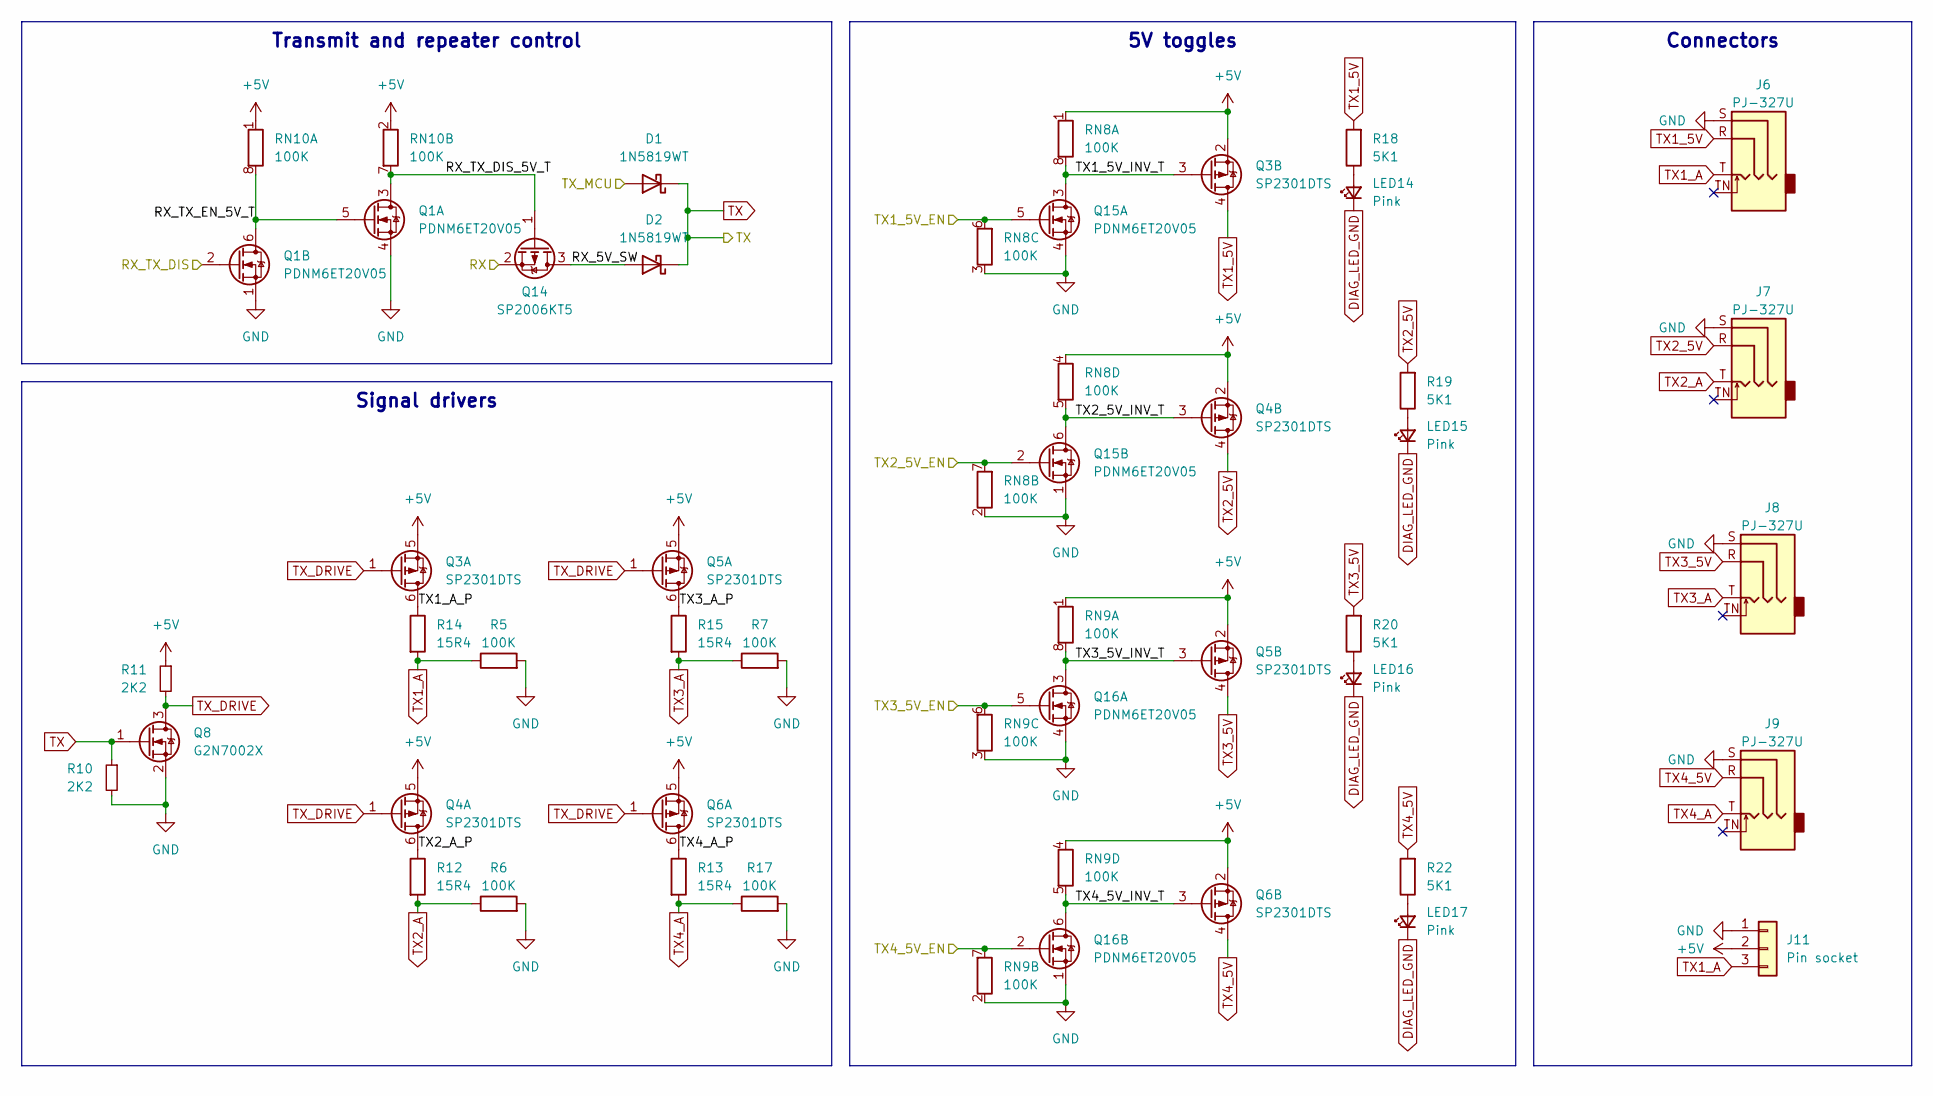
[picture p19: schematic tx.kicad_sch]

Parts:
D1, D2: 1N5819WT; D_SOD-523; LCSC Part C20754784
J6, J7, J8, J9: PJ-327U; Jack_3.5mm_PJ-327U-SMT_Horizontal; LCSC Part C397453
J11: Pin socket; PinSocket_1x03_P2.54mm_Vertical
LED14, LED15, LED16, LED17: Pink; LED_0603_1608Metric; LCSC Part C7496826
Q1, Q15, Q16: PDNM6ET20V05; SOT-563; LCSC Part C918811
Q3, Q4, Q5, Q6: SP2301DTS; SOT-23-6; LCSC Part C41355155
Q8: G2N7002X; SOT-523; LCSC Part C5258971
Q14: SP2006KT5; SOT-523; LCSC Part C41355141
R5, R6, R7, R17: 100K; R_0603_1608Metric; LCSC Part C25803
R10, R11: 2K2; R_0603_1608Metric; LCSC Part C4190
R12, R13, R14, R15: 15R4; R_1206_3216Metric; LCSC Part C3013373
R18, R19, R20, R22: 5K1; R_0603_1608Metric; LCSC Part C23186
RN8, RN9, RN10: 100K; R_Array_Convex_4x0603; LCSC Part C110374

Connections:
+5V: J11.2, Q3.2 (S2), Q3.5 (S1), Q4.2 (S2), Q4.5 (S1), Q5.2 (S2), Q5.5 (S1), Q6.2 (S2), Q6.5 (S1), R11.1, RN8.1 (R1.1), RN8.4 (R4.1), RN9.1 (R1.1), RN9.4 (R4.1), RN10.1 (R1.1), RN10.2 (R2.1); also elsewhere on the board
/Infrared Transmitter/RX_5V_SW: D2.2 (A), Q14.3 (D)
/Infrared Transmitter/RX_TX_DIS_5V_T: Q1.3 (D), Q14.1 (G), RN10.7 (R2.2)
/Infrared Transmitter/RX_TX_EN_5V_T: Q1.5 (G), Q1.6 (D), RN10.8 (R1.2)
/Infrared Transmitter/TX1_5V_INV_T: Q3.3 (G2), Q15.3 (D), RN8.8 (R1.2)
/Infrared Transmitter/TX1_A_P: Q3.6 (D1), R14.1
/Infrared Transmitter/TX2_5V_INV_T: Q4.3 (G2), Q15.6 (D), RN8.5 (R4.2)
/Infrared Transmitter/TX2_A_P: Q4.6 (D1), R12.1
/Infrared Transmitter/TX3_5V_INV_T: Q5.3 (G2), Q16.3 (D), RN9.8 (R1.2)
/Infrared Transmitter/TX3_A_P: Q5.6 (D1), R15.1
/Infrared Transmitter/TX4_5V_INV_T: Q6.3 (G2), Q16.6 (D), RN9.5 (R4.2)
/Infrared Transmitter/TX4_A_P: Q6.6 (D1), R13.1
DIAG_LED_GND: LED14.1 (K), LED15.1 (K), LED16.1 (K), LED17.1 (K); also elsewhere on the board
GND: J6.S, J7.S, J8.S, J9.S, J11.1, Q1.1 (S), Q1.4 (S), Q8.2 (S), Q15.1 (S), Q15.4 (S), Q16.1 (S), Q16.4 (S), R5.2, R6.2, R7.2, R10.2, R17.2, RN8.2 (R2.1), RN8.3 (R3.1), RN9.2 (R2.1), RN9.3 (R3.1); also elsewhere on the board
unnamed: LED14.2 (A), R18.1
unnamed: LED15.2 (A), R19.1
unnamed: LED16.2 (A), R20.1
unnamed: LED17.2 (A), R22.1
RX: Q14.2 (S); also elsewhere on the board
RX_TX_DIS: Q1.2 (G); also elsewhere on the board
TX: D1.1 (K), D2.1 (K), Q8.1 (G), R10.1; also elsewhere on the board
TX1_5V: J6.R, Q3.4 (D2), R18.2
TX1_5V_EN: Q15.5 (G), RN8.6 (R3.2); also elsewhere on the board
TX1_A: J6.T, J11.3, R5.1, R14.2
TX2_5V: J7.R, Q4.4 (D2), R19.2
TX2_5V_EN: Q15.2 (G), RN8.7 (R2.2); also elsewhere on the board
TX2_A: J7.T, R6.1, R12.2
TX3_5V: J8.R, Q5.4 (D2), R20.2
TX3_5V_EN: Q16.5 (G), RN9.6 (R3.2); also elsewhere on the board
TX3_A: J8.T, R7.1, R15.2
TX4_5V: J9.R, Q6.4 (D2), R22.2
TX4_5V_EN: Q16.2 (G), RN9.7 (R2.2); also elsewhere on the board
TX4_A: J9.T, R13.2, R17.1
TX_DRIVE: Q3.1 (G1), Q4.1 (G1), Q5.1 (G1), Q6.1 (G1), Q8.3 (D), R11.2
TX_MCU: D1.2 (A); also elsewhere on the board

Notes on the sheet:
Transmit and repeater control
Connectors
5V toggles
Signal drivers

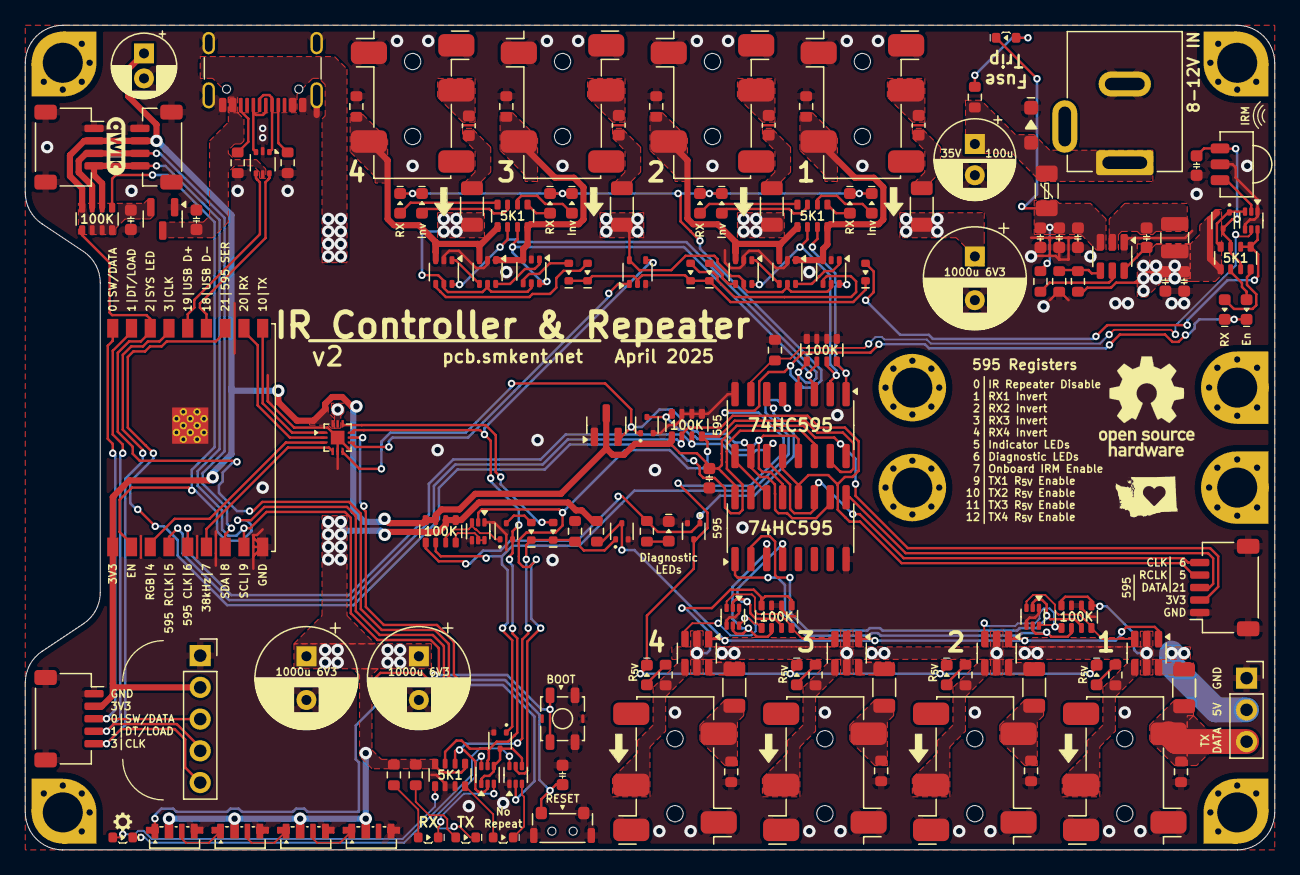
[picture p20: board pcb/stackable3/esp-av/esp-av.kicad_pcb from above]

Board: 2 copper layers, 100.0 x 66.0 mm, 146 parts (0 on the bottom side), 124 nets.

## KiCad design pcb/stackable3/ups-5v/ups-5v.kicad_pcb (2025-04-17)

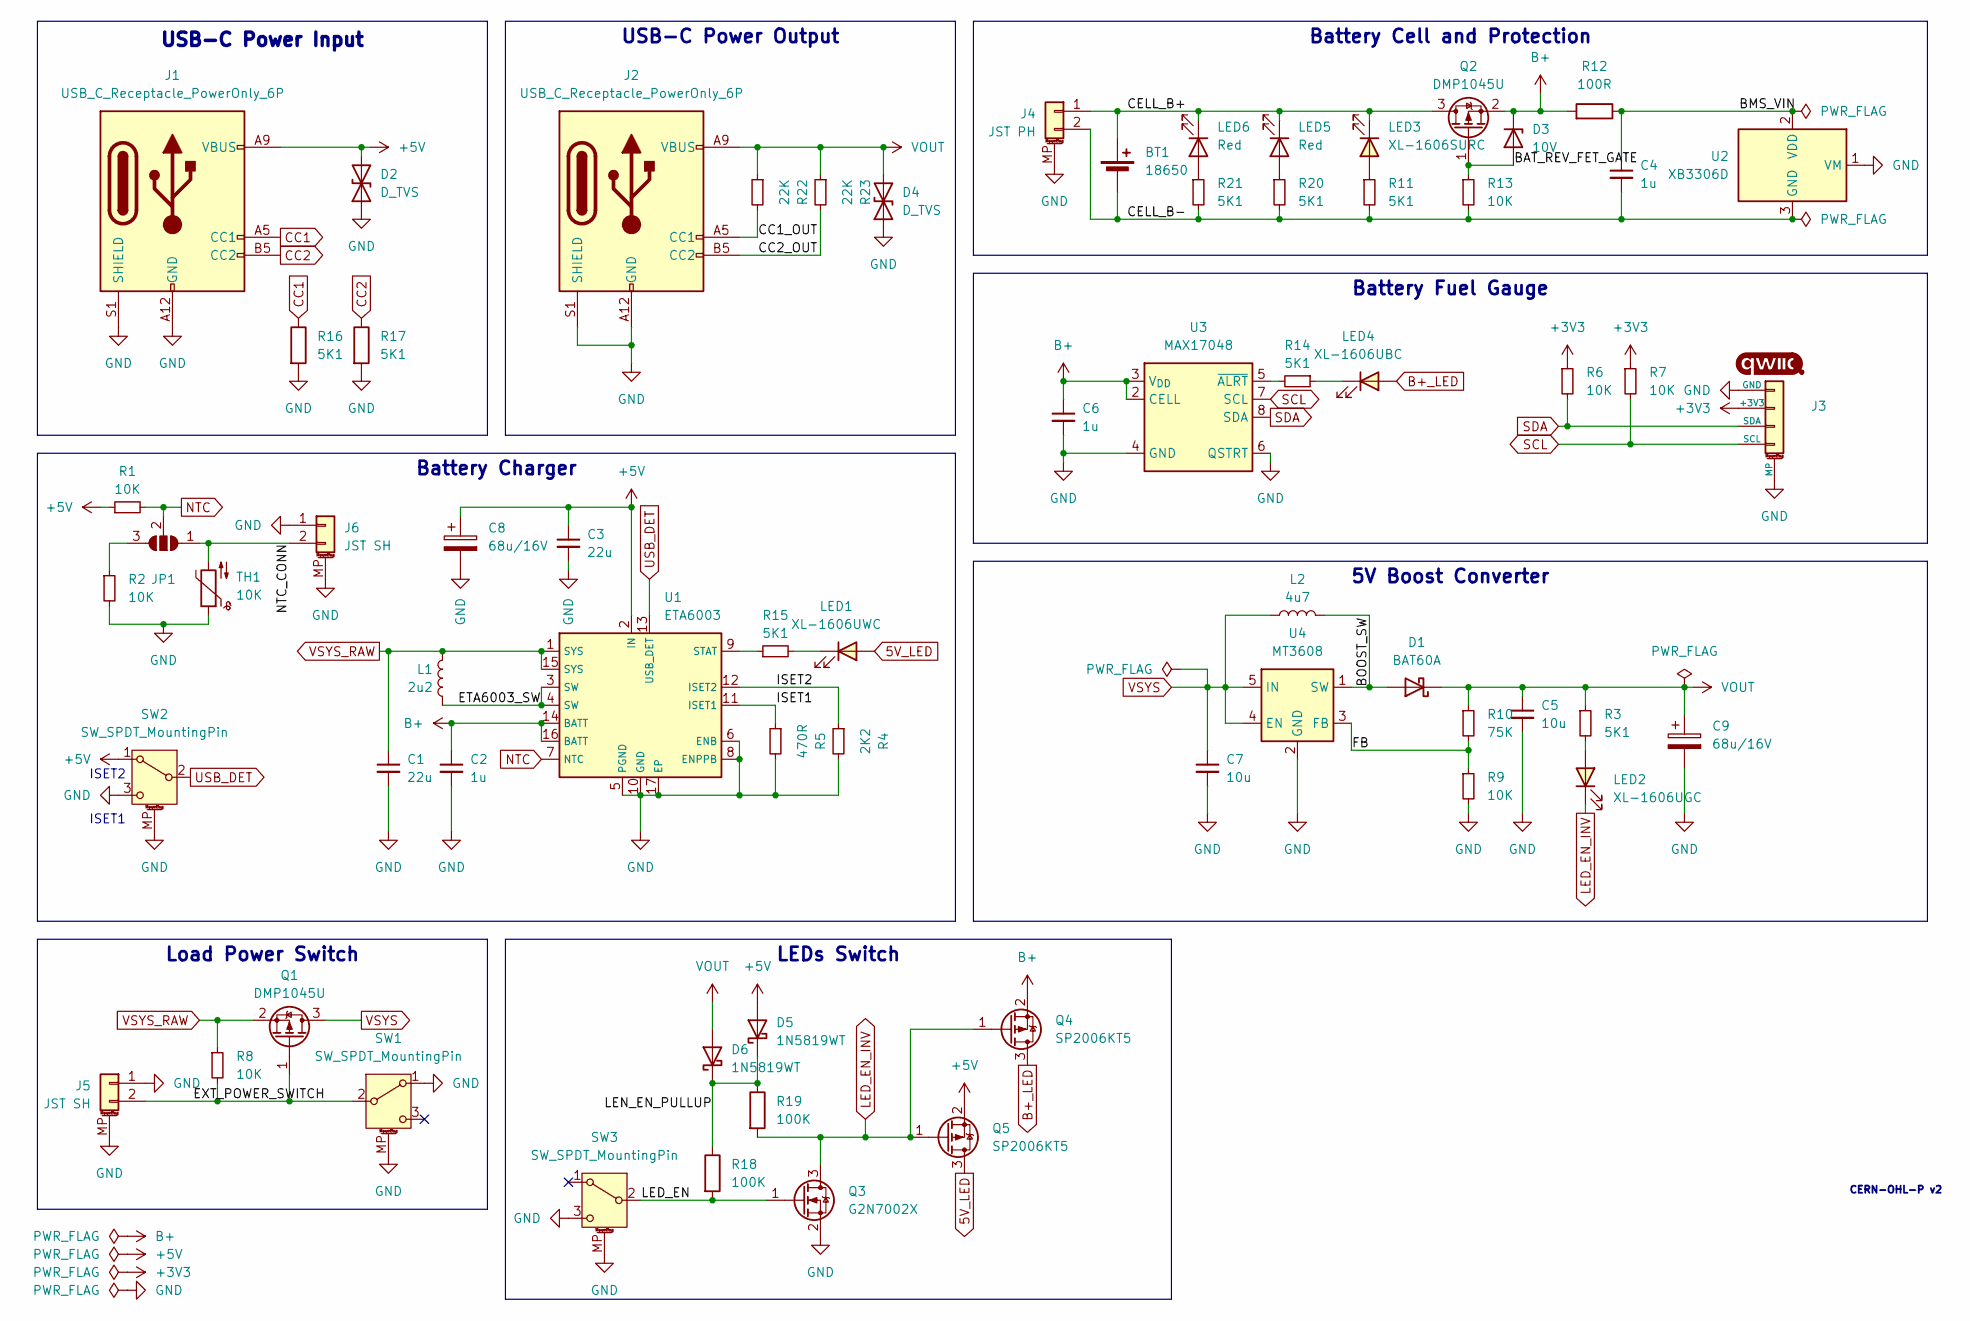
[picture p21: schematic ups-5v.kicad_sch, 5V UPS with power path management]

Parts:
BT1: 18650; BatteryHolder_1x18650_THT
C1: 22u; C_0603_1608Metric; LCSC Part C86295
C2, C4, C6: 1u; C_0603_1608Metric; LCSC Part C5199872
C3: 22u; C_0805_2012Metric; LCSC Part C602037
C5, C7: 10u; C_0603_1608Metric; LCSC Part C22367825
C8, C9: 68u/16V; CP_Radial_D6.3mm_P2.50mm; LCSC Part C2976197
D1: BAT60A; D_SOD-323; LCSC Part C7502695
D2, D4: D_TVS; D_SOD-882; LCSC Part C45961
D3: 10V; D_SOD-523; LCSC Part C2832579
D5, D6: 1N5819WT; D_SOD-523; LCSC Part C20754784
J1, J2: USB_C_Receptacle_PowerOnly_6P; USB_C_Receptacle_GCT_USB4125-xx-x_6P_TopMnt_Horizontal_Hand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; LCSC Part C2927029
J3: Qwiic; Qwiic-SMD-horizontal-logo; LCSC Part C19270571
J4: JST PH; JST_PH_S2B-PH-SM4-TB_1x02-1MP_P2.00mm_Horizontal; LCSC Part C18221575
J5, J6: JST SH; JST_SH_SM02B-SRSS-TB_1x02-1MP_P1.00mm_Horizontal; LCSC Part C7433423
JP1: SolderJumper_3_Open; SolderJumper-3_P1.3mm_Open_RoundedPad1.0x1.5mm
L1: 2u2; L_1008_2520Metric; LCSC Part C5832372
L2: 4u7; L_1008_2520Metric; LCSC Part C22471106
LED1: XL-1606UWC; LED_SideEmitter_1.7x1.1mm; LCSC Part C965866
LED2: XL-1606UGC; LED_SideEmitter_1.7x1.1mm; LCSC Part C965863
LED3: XL-1606SURC; LED_SideEmitter_1.7x1.1mm; LCSC Part C965860
LED4: XL-1606UBC; LED_SideEmitter_1.7x1.1mm; LCSC Part C965865
LED5, LED6: Red; LED_0603_1608Metric; LCSC Part C7371906
Q1, Q2: DMP1045U; SOT-23; LCSC Part C177033
Q3: G2N7002X; SOT-523; LCSC Part C5258971
Q4, Q5: SP2006KT5; SOT-523; LCSC Part C41355141
R1, R2, R6, R7, R8, R9, R13: 10K; R_0603_1608Metric; LCSC Part C25804
R3: 5K1; R_0603_1608Metric; LCSC Part C23186
R4: 2K2; R_0603_1608Metric; LCSC Part C4190
R5: 470R; R_0603_1608Metric; LCSC Part C23179
R10: 75K; R_0603_1608Metric; LCSC Part C23242
R11, R14, R15, R16, R17, R20, R21: 5K1; R_0603_1608Metric; LCSC Part C25905
R12: 100R; R_0603_1608Metric; LCSC Part C25076
R18, R19: 100K; R_0603_1608Metric; LCSC Part C25803
R22, R23: 22K; R_0603_1608Metric; LCSC Part C31850
SW1, SW2, SW3: SW_SPDT_MountingPin; SW_SPDT_PCM12; LCSC Part C319020
TH1: 10K; JST_SH_SM02B-SRSS-TB_1x02-1MP_P1.00mm_Horizontal
U1: ETA6003; QFN-16-1EP_3x3mm_P0.5mm_EP1.7x1.7mm_ThermalVias_ETA6003; LCSC Part C5455585
U2: XB3306D; SOT-23; LCSC Part C2759992
U3: MAX17048; TDFN-8-1EP_2x2mm_P0.5mm_EP0.8x1.2mm; LCSC Part C2682616
U4: MT3608; SOT-23-6; LCSC Part C84817

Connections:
5V_LED: LED1.2 (A), Q5.3 (D)
+3V3: J3.2 (+3V3), R6.1, R7.1
+5V: C3.1, C8.1, D2.2 (A2), D5.2 (A), J1.A9 (VBUS), J1.B9 (VBUS), Q5.2 (S), R1.1, SW2.1 (A), U1.2 (IN)
/BAT_REV_FET_GATE: D3.2 (A), Q2.1 (G), R13.1
/BMS_VIN: C4.1, R12.1, U2.2 (VDD)
/BOOST_SW: D1.2 (A), L2.2, U4.1 (SW)
/CC1_OUT: J2.A5 (CC1), R22.2
/CC2_OUT: J2.B5 (CC2), R23.2
/CELL_B+: BT1.1 (+), J4.1, LED3.1 (K), LED5.1 (K), LED6.1 (K), Q2.3 (D)
/CELL_B-: BT1.2 (-), C4.2, J4.2, R11.2, R13.2, R20.2, R21.2, U2.3 (GND)
/ETA6003_SW: L1.2, U1.3 (SW), U1.4 (SW)
/EXT_POWER_SWITCH: J5.2, Q1.1 (G), R8.2, SW1.2 (B)
/FB: R9.1, R10.2, U4.3 (FB)
/ISET1: R5.1, U1.11 (ISET1)
/ISET2: R4.1, U1.12 (ISET2)
/LED_EN: Q3.1 (G), R18.2, SW3.2 (B)
/LEN_EN_PULLUP: D5.1 (K), D6.1 (K), R18.1, R19.1
/NTC_CONN: J6.2, JP1.1 (A), TH1.2
B+: C2.1, C6.1, D3.1 (K), Q2.2 (S), Q4.2 (S), R12.2, U1.14 (BATT), U1.16 (BATT), U3.2 (CELL), U3.3 (V_{DD})
B+_LED: LED4.2 (A), Q4.3 (D)
CC1: J1.A5 (CC1), R16.1
CC2: J1.B5 (CC2), R17.1
GND: C1.2, C2.2, C3.2, C5.2, C6.2, C7.2, C8.2, C9.2, D2.1 (A1), D4.1 (A1), J1.A12 (GND), J1.B12 (GND), J1.S1 (SHIELD), J2.A12 (GND), J2.B12 (GND), J2.S1 (SHIELD), J3.1 (GND), J3.MP, J4.MP (MountPin), J5.1, J5.MP (MountPin), J6.1, J6.MP (MountPin), Q3.2 (S), R2.2, R4.2, R5.2, R9.2, R16.2, R17.2, SW1.1 (A), SW1.MP (MountPin), SW2.3 (C), SW2.MP (MountPin), SW3.3 (C), SW3.MP (MountPin), TH1.1, U1.5 (PGND), U1.6 (ENB), U1.8 (ENPPB), U1.10 (GND), U1.17 (EP), U2.1 (VM), U3.1 (CTG), U3.4 (GND), U3.6 (QSTRT), U3.9 (EP), U4.2 (GND)
LED_EN_INV: LED2.1 (K), Q3.3 (D), Q4.1 (G), Q5.1 (G), R19.2
NTC: JP1.2 (C), R1.2, U1.7 (NTC)
unnamed: JP1.3 (B), R2.1
unnamed: LED1.1 (K), R15.2
unnamed: LED2.2 (A), R3.2
unnamed: LED3.2 (A), R11.1
unnamed: LED4.1 (K), R14.1
unnamed: LED5.2 (A), R20.1
unnamed: LED6.2 (A), R21.1
unnamed: R15.1, U1.9 (STAT)
unnamed: R14.2, U3.5 (~ALRT)
SCL: J3.4 (SCL), R7.2, U3.7 (SCL)
SDA: J3.3 (SDA), R6.2, U3.8 (SDA)
USB_DET: SW2.2 (B), U1.13 (USB_DET)
VOUT: C5.1, C9.1, D1.1 (K), D4.2 (A2), D6.2 (A), J2.A9 (VBUS), J2.B9 (VBUS), R3.1, R10.1, R22.1, R23.1
VSYS: C7.1, L2.1, Q1.3 (D), U4.4 (EN), U4.5 (IN)
VSYS_RAW: C1.1, L1.1, Q1.2 (S), R8.1, U1.1 (SYS), U1.15 (SYS)

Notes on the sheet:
CERN-OHL-P v2
ISET1
ISET2
5V Boost Converter
USB-C Power Output
Battery Fuel Gauge
USB-C Power Input
Battery Cell and Protection
LEDs Switch
Load Power Switch
Battery Charger

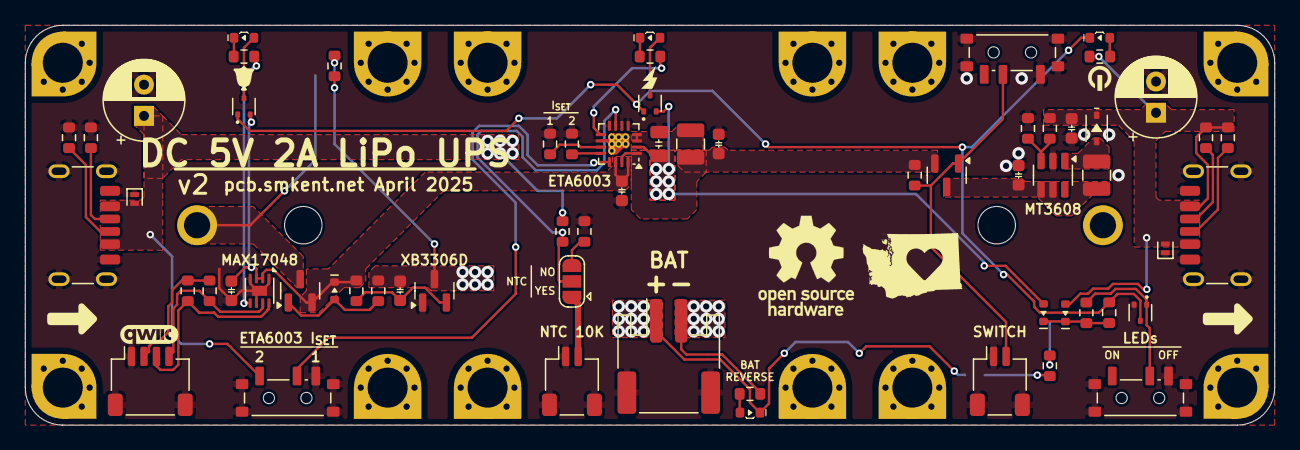
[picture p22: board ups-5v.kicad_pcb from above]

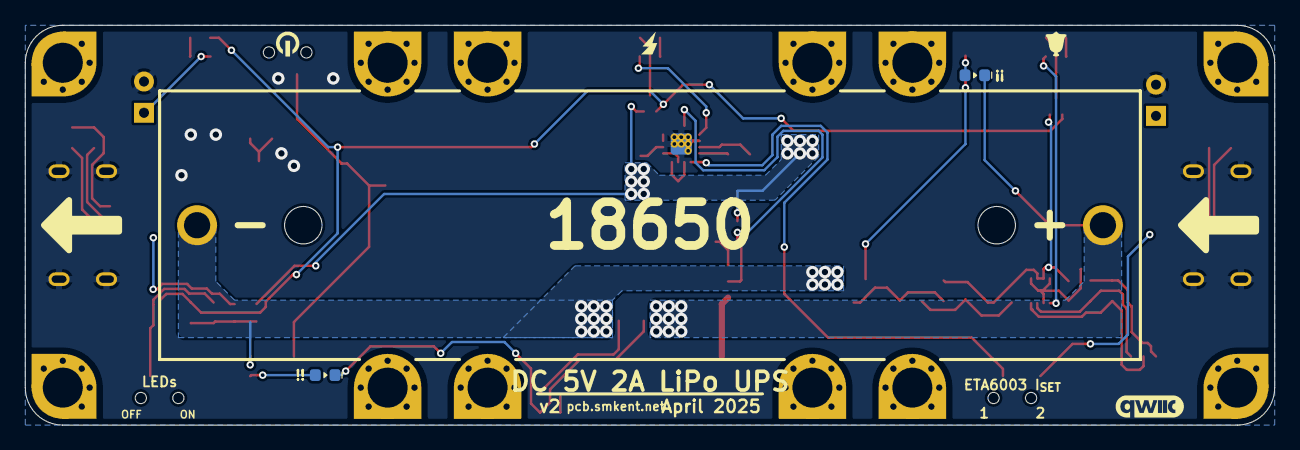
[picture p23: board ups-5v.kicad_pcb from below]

Board: 2 copper layers, 100.0 x 32.0 mm, 66 parts (3 on the bottom side), 40 nets.

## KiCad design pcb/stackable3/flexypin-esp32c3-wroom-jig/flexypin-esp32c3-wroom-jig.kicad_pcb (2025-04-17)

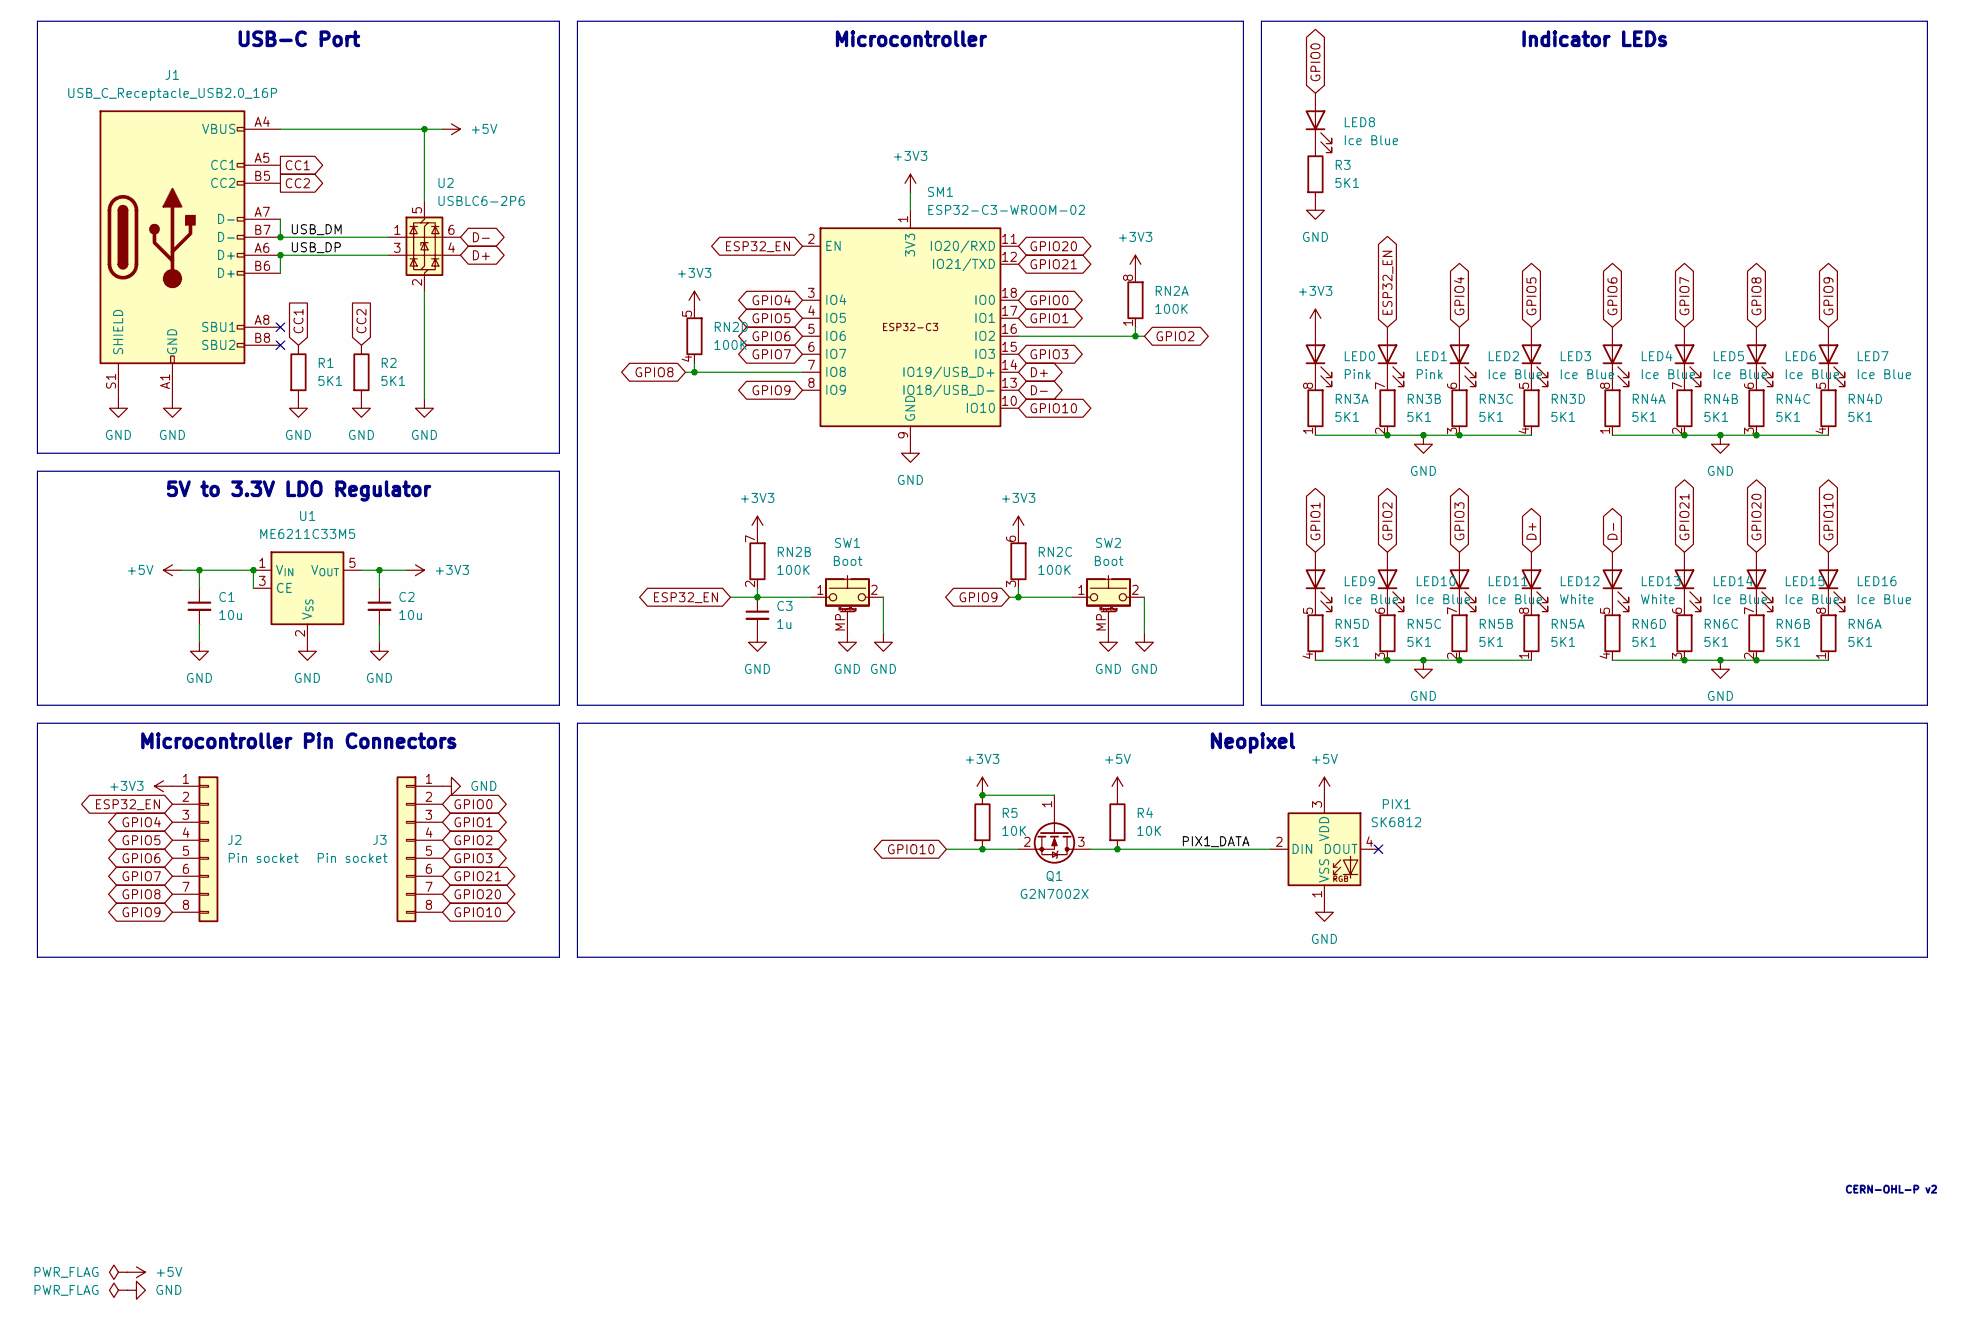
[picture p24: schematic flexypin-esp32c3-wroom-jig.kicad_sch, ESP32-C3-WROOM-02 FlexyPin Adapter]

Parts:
C1, C2: 10u; C_0402_1005Metric; LCSC Part C315248
C3: 1u; C_0402_1005Metric; LCSC Part C52923
J1: USB_C_Receptacle_USB2.0_16P; USB_C_Receptacle_GCT_USB4105-xx-A_16P_TopMnt_Horizontal; LCSC Part C2765186
J2, J3: Pin socket; PinSocket_1x08_P2.54mm_Vertical
LED0, LED1: Pink; LED_0402_1005Metric; LCSC Part C779449
LED2, LED3, LED4, LED5, LED6, LED7, LED8, LED9, LED10, LED11, LED14, LED15, LED16: Ice Blue; LED_0402_1005Metric; LCSC Part C7496805
LED12, LED13: White; LED_0402_1005Metric; LCSC Part C20613596
PIX1: SK6812; LED_SK6812_PLCC4_5.0x5.0mm_P3.2mm
Q1: G2N7002X; SOT-523; LCSC Part C5258971
R1, R2: 5K1; R_0603_1608Metric; LCSC Part C23186
R3: 5K1; R_0402_1005Metric; LCSC Part C25905
R4, R5: 10K; R_0603_1608Metric; LCSC Part C25804
RN2: 100K; R_Array_Convex_4x0402_HandSolder; LCSC Part C110374
RN3, RN4, RN5, RN6: 5K1; R_Array_Convex_4x0402_HandSolder; LCSC Part C425290
SM1: ESP32-C3-WROOM-02; ESP32-C3-WROOM-02-FlexyPin
SW1, SW2: Boot; SW_Push_1P1T_NO_3.3x3.3mm_MP
U1: ME6211C33M5; SOT-23-5; LCSC Part C82942
U2: USBLC6-2P6; SOT-666; LCSC Part C29780639

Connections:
+3V3: C2.1, J2.1, LED0.2 (A), Q1.1 (G), R5.1, RN2.5 (R4.2), RN2.6 (R3.2), RN2.7 (R2.2), RN2.8 (R1.2), SM1.1 (3V3), U1.5 (V_{OUT})
+5V: C1.1, J1.A4 (VBUS), J1.A9 (VBUS), J1.B4 (VBUS), J1.B9 (VBUS), PIX1.3 (VDD), R4.1, U1.1 (V_{IN}), U1.3 (CE), U2.5 (VBUS)
/PIX1_DATA: PIX1.2 (DIN), Q1.3 (D), R4.2
/USB_DM: J1.A7 (D-), J1.B7 (D-), U2.1 (I/O1)
/USB_DP: J1.A6 (D+), J1.B6 (D+), U2.3 (I/O2)
CC1: J1.A5 (CC1), R1.1
CC2: J1.B5 (CC2), R2.1
D+: LED12.2 (A), SM1.14 (IO19/USB_D+), U2.4 (I/O2)
D-: LED13.2 (A), SM1.13 (IO18/USB_D-), U2.6 (I/O1)
ESP32_EN: C3.1, J2.2, LED1.2 (A), RN2.2 (R2.1), SM1.2 (EN), SW1.1
GND: C1.2, C2.2, C3.2, J1.A1 (GND), J1.A12 (GND), J1.B1 (GND), J1.B12 (GND), J1.S1 (SHIELD), J3.1, PIX1.1 (VSS), R1.2, R2.2, R3.2, RN3.1 (R1.1), RN3.2 (R2.1), RN3.3 (R3.1), RN3.4 (R4.1), RN4.1 (R1.1), RN4.2 (R2.1), RN4.3 (R3.1), RN4.4 (R4.1), RN5.1 (R1.1), RN5.2 (R2.1), RN5.3 (R3.1), RN5.4 (R4.1), RN6.1 (R1.1), RN6.2 (R2.1), RN6.3 (R3.1), RN6.4 (R4.1), SM1.9 (GND), SM1.19 (GND), SW1.2, SW1.MP (MountPin), SW2.2, SW2.MP (MountPin), U1.2 (V_{SS}), U2.2 (GND)
GPIO0: J3.2, LED8.2 (A), SM1.18 (IO0)
GPIO1: J3.3, LED9.2 (A), SM1.17 (IO1)
GPIO2: J3.4, LED10.2 (A), RN2.1 (R1.1), SM1.16 (IO2)
GPIO3: J3.5, LED11.2 (A), SM1.15 (IO3)
GPIO4: J2.3, LED2.2 (A), SM1.3 (IO4)
GPIO5: J2.4, LED3.2 (A), SM1.4 (IO5)
GPIO6: J2.5, LED4.2 (A), SM1.5 (IO6)
GPIO7: J2.6, LED5.2 (A), SM1.6 (IO7)
GPIO8: J2.7, LED6.2 (A), RN2.4 (R4.1), SM1.7 (IO8)
GPIO9: J2.8, LED7.2 (A), RN2.3 (R3.1), SM1.8 (IO9), SW2.1
GPIO10: J3.8, LED16.2 (A), Q1.2 (S), R5.2, SM1.10 (IO10)
GPIO20: J3.7, LED15.2 (A), SM1.11 (IO20/RXD)
GPIO21: J3.6, LED14.2 (A), SM1.12 (IO21/TXD)
unnamed: LED0.1 (K), RN3.8 (R1.2)
unnamed: LED1.1 (K), RN3.7 (R2.2)
unnamed: LED2.1 (K), RN3.6 (R3.2)
unnamed: LED3.1 (K), RN3.5 (R4.2)
unnamed: LED4.1 (K), RN4.8 (R1.2)
unnamed: LED5.1 (K), RN4.7 (R2.2)
unnamed: LED6.1 (K), RN4.6 (R3.2)
unnamed: LED7.1 (K), RN4.5 (R4.2)
unnamed: LED8.1 (K), R3.1
unnamed: LED9.1 (K), RN5.5 (R4.2)
unnamed: LED10.1 (K), RN5.6 (R3.2)
unnamed: LED11.1 (K), RN5.7 (R2.2)
unnamed: LED12.1 (K), RN5.8 (R1.2)
unnamed: LED13.1 (K), RN6.5 (R4.2)
unnamed: LED14.1 (K), RN6.6 (R3.2)
unnamed: LED15.1 (K), RN6.7 (R2.2)
unnamed: LED16.1 (K), RN6.8 (R1.2)

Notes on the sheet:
CERN-OHL-P v2
Indicator LEDs
Neopixel
Microcontroller Pin Connectors
5V to 3.3V LDO Regulator
USB-C Port
Microcontroller

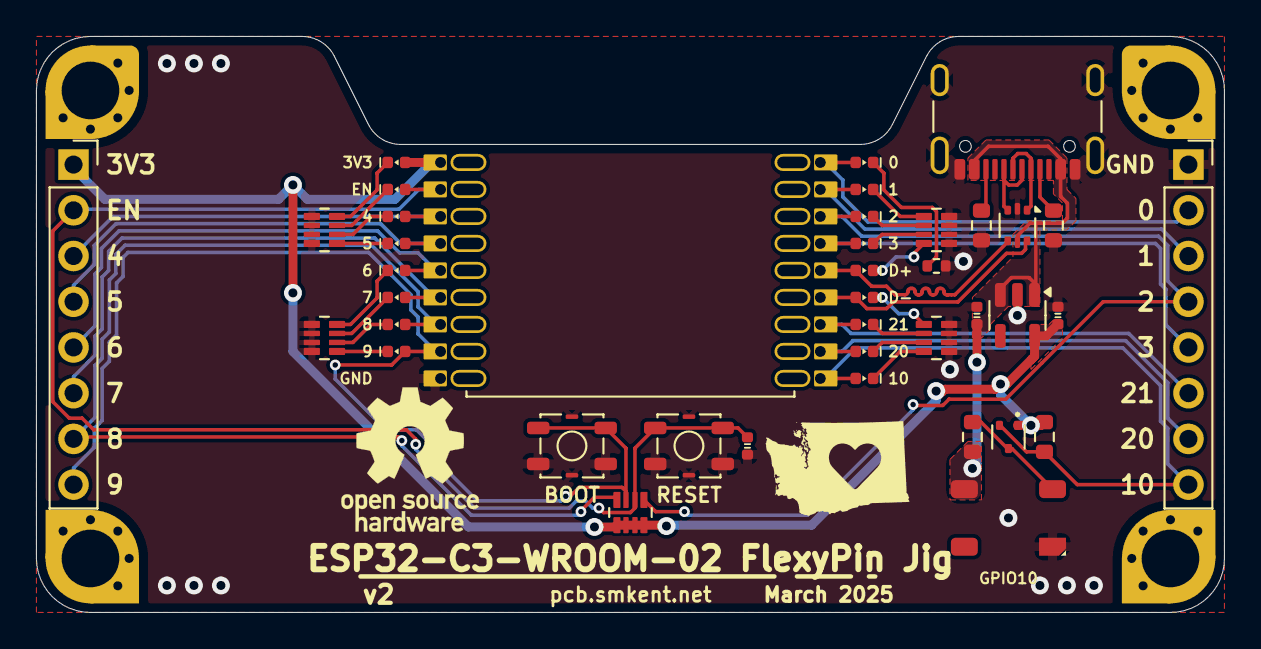
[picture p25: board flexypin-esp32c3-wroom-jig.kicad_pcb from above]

Board: 2 copper layers, 66.0 x 32.0 mm, 40 parts (0 on the bottom side), 41 nets.

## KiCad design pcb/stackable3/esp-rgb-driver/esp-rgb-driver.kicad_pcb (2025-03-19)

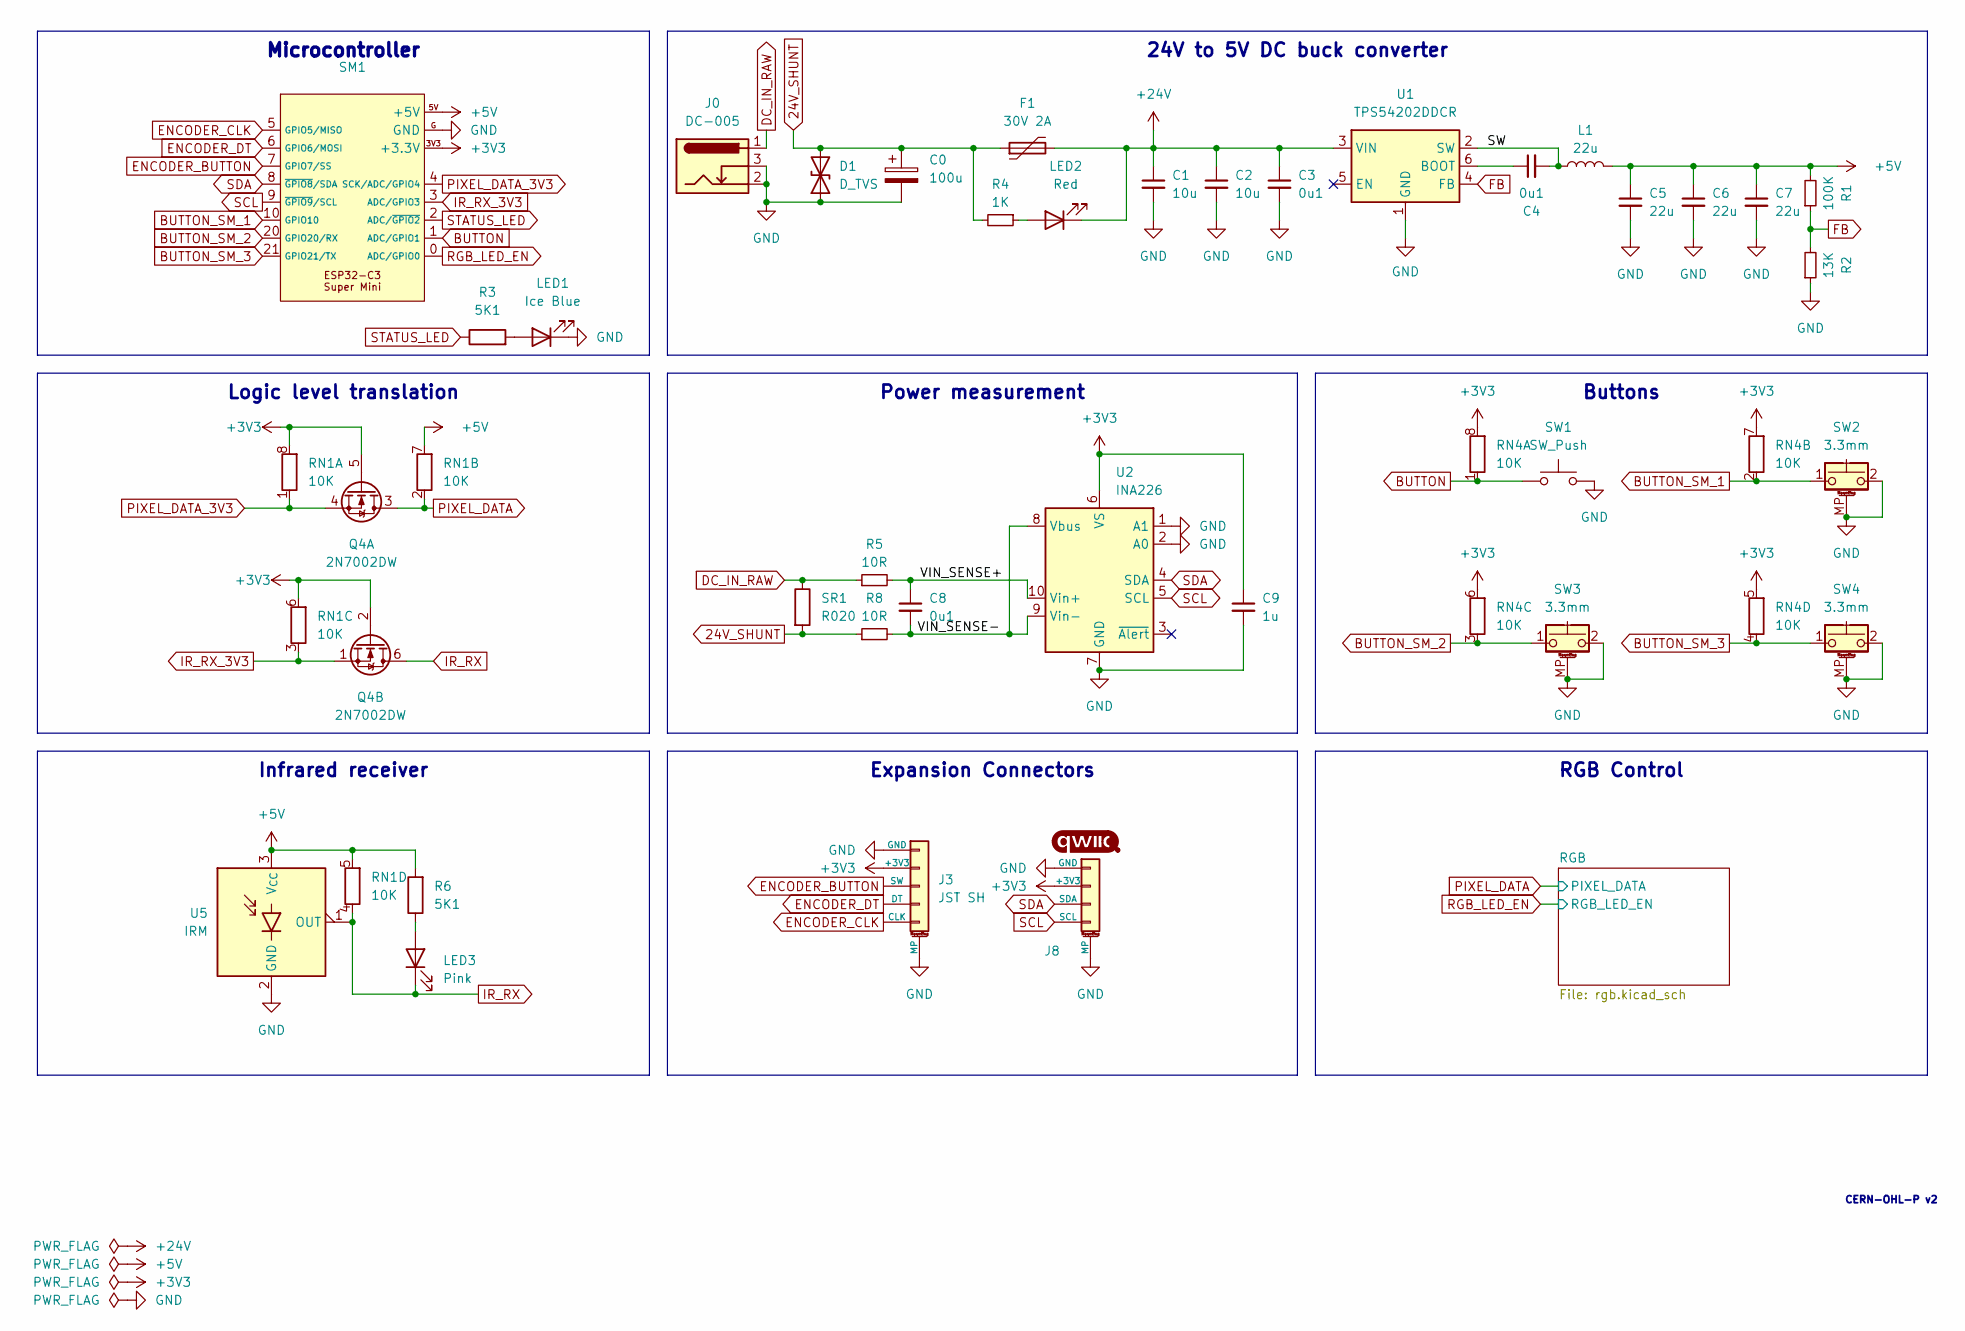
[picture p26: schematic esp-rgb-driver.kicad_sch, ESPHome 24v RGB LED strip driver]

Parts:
C0: 100u; CP_Radial_D6.3mm_P2.50mm; LCSC Part C5379947
C1, C2: 10u; C_0603_1608Metric; LCSC Part C22367825
C3, C4, C8: 0u1; C_0402_1005Metric; LCSC Part C152814
C5, C6, C7: 22u; C_0603_1608Metric; LCSC Part C86295
C9: 1u; C_0402_1005Metric; LCSC Part C52923
D1: D_TVS; D_SOD-123F; LCSC Part C7473232
F1: 30V 2A; Fuse_1812_4532Metric; LCSC Part C22366122
J0: DC-005; BarrelJack_DC-005_THT_Horizontal
J3: JST SH; JST_SH_SM05B-SRSS-TB_1x05-1MP_P1.00mm_Horizontal; LCSC Part C7433426
J8: Qwiic; Qwiic-SMD-horizontal-logo; LCSC Part C19270571
L1: 22u; L_1008_2520Metric; LCSC Part C5832391
LED1: Ice Blue; LED_0603_1608Metric; LCSC Part C7496823
LED2: Red; LED_0402_1005Metric; LCSC Part C779449
LED3: Pink; LED_0402_1005Metric
Q4: 2N7002DW; SOT-363_SC-70-6; LCSC Part C5190214
R1: 100K; R_0603_1608Metric; LCSC Part C25803
R2: 13K; R_0603_1608Metric; LCSC Part C22797
R3, R6: 5K1; R_0402_1005Metric; LCSC Part C25905
R4: 1K; R_0402_1005Metric; LCSC Part C11702
R5, R8: 10R; R_0402_1005Metric; LCSC Part C25077
RN1, RN4: 10K; R_Array_Convex_4x0603; LCSC Part C110924
SM1: ESP32-C3-Super-Mini-Castellated-SMD-only
SR1: R020; R_2512_6332Metric_Pad1.40x3.35mm_HandSolder; LCSC Part C5375467
SW1: SW_Push; SW_SPST_PTS647_Sx50; LCSC Part C22459537
SW2, SW3, SW4: 3.3mm; SW_Push_1P1T_NO_3.3x3.3mm_MP
U1: TPS54202DDCR; SOT-23-6; LCSC Part C191884
U2: INA226; VSSOP-10_3x3mm_P0.5mm; LCSC Part C49851
U5: IRM; IRM_5.0x5.0mm_SIP-3_P1.27mm_THT; LCSC Part C7433078

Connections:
24V_SHUNT: C0.1, D1.2 (A2), F1.1, R4.2, R8.1, SR1.2
+3V3: C9.1, J3.2 (+3V3), J8.2 (+3V3), Q4.2 (G), Q4.5 (G), RN1.6 (R3.2), RN1.8 (R1.2), RN4.5 (R4.2), RN4.6 (R3.2), RN4.7 (R2.2), RN4.8 (R1.2), SM1.3V3 (+3.3V), U2.6 (VS)
+5V: C5.1, C6.1, C7.1, L1.2, R1.2, R6.2, RN1.5 (R4.2), RN1.7 (R2.2), SM1.5V (+5V), U5.3 (V_{CC}); also elsewhere on the board
+24V: C1.1, C2.1, C3.1, F1.2, LED2.1 (K), U1.3 (VIN); also elsewhere on the board
/SW: C4.2, L1.1, U1.2 (SW)
/VIN_SENSE+: C8.1, R5.2, U2.10 (Vin+)
/VIN_SENSE-: C8.2, R8.2, U2.8 (Vbus), U2.9 (Vin-)
BUTTON: RN4.1 (R1.1), SM1.1 (ADC/GPIO1), SW1.1
BUTTON_SM_1: RN4.2 (R2.1), SM1.10 (GPIO10), SW2.1
BUTTON_SM_2: RN4.3 (R3.1), SM1.20 (GPIO20/RX), SW3.1
BUTTON_SM_3: RN4.4 (R4.1), SM1.21 (GPIO21/TX), SW4.1
DC_IN_RAW: J0.1, R5.1, SR1.1
ENCODER_BUTTON: J3.3 (SW), SM1.7 (GPIO7/SS)
ENCODER_CLK: J3.5 (CLK), SM1.5 (GPIO5/MISO)
ENCODER_DT: J3.4 (DT), SM1.6 (GPIO6/MOSI)
FB: R1.1, R2.2, U1.4 (FB)
GND: C0.2, C1.2, C2.2, C3.2, C5.2, C6.2, C7.2, C9.2, D1.1 (A1), J0.2, J0.3, J3.1 (GND), J3.MP, J8.1 (GND), J8.MP, LED1.1 (K), R2.1, SM1.G (GND), SW1.2, SW2.2, SW2.MP (MountPin), SW3.2, SW3.MP (MountPin), SW4.2, SW4.MP (MountPin), U1.1 (GND), U2.1 (A1), U2.2 (A0), U2.7 (GND), U5.2 (GND); also elsewhere on the board
IR_RX: LED3.1 (K), Q4.6 (D), RN1.4 (R4.1), U5.1 (OUT)
IR_RX_3V3: Q4.1 (S), RN1.3 (R3.1), SM1.3 (ADC/GPIO3)
unnamed: LED1.2 (A), R3.2
unnamed: LED2.2 (A), R4.1
unnamed: LED3.2 (A), R6.1
unnamed: C4.1, U1.6 (BOOT)
PIXEL_DATA: Q4.3 (D), RN1.2 (R2.1); also elsewhere on the board
PIXEL_DATA_3V3: Q4.4 (S), RN1.1 (R1.1), SM1.4 (SCK/ADC/GPIO4)
RGB_LED_EN: SM1.0 (ADC/GPIO0); also elsewhere on the board
SCL: J8.4 (SCL), SM1.9 (~GPIO9/SCL), U2.5 (SCL)
SDA: J8.3 (SDA), SM1.8 (~GPIO8/SDA), U2.4 (SDA)
STATUS_LED: R3.1, SM1.2 (ADC/~GPIO2)

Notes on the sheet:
Power measurement
Logic level translation
24V to 5V DC buck converter
Infrared receiver
Expansion Connectors
RGB Control
Microcontroller
Buttons
CERN-OHL-P v2


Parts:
J1, J2: JST PH; JST_PH_S4B-PH-SM4-TB_1x04-1MP_P2.00mm_Horizontal; LCSC Part C5343396
J5, J6: STEMMA-Signal; STEMMA-Signal-SMD-horizontal; LCSC Part C5372880
JP1: Open; SolderJumper-2_P1.3mm_Open_TrianglePad1.0x1.5mm
LED4, LED5: XL-B1010RGBT-HF; LED_RGB_XL-B1010RGBT-HF_1.0x1.0mm; LCSC Part C22464515
Q1, Q2, Q3: ZC010DNG; PDFN-8_L3.2-W3.1-P0.65-LS3.4-BL-EP2; LCSC Part C36499170
Q5: G2N7002X; SOT-523; LCSC Part C5258971
Q6: SP2006KT5; SOT-523; LCSC Part C41355141
R7, R11, R12, R13, R14, R15: 1K; R_0402_1005Metric; LCSC Part C11702
R9, R10: 10K; R_0402_1005Metric; LCSC Part C25744
RN2, RN3: 10K; R_Array_Convex_4x0603; LCSC Part C110924
U3, U4: WS2811F; FSOP-8_3.3x1.7mm_P0.80mm; LCSC Part C5446692
U7, U8, U9: NC7WZ14P6X; SOT-363_SC-70-6; LCSC Part C5207816

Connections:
+5V: J6.2 (V+), JP1.1 (A), Q6.2 (S), R9.2, RN2.5 (R4.2), RN2.6 (R3.2), RN2.7 (R2.2), RN3.5 (R4.2), RN3.6 (R3.2), RN3.7 (R2.2), U3.8 (VDD), U4.8 (VDD), U7.5 (V_{CC}), U8.5 (V_{CC}), U9.5 (V_{CC}); also elsewhere on the board
+24V: J1.1, J2.1; also elsewhere on the board
/RGB/RGB1_5V_B_K_T: LED4.4 (BK), R12.2
/RGB/RGB1_5V_G_K_T: LED4.3 (GK), R11.2
/RGB/RGB1_5V_R_K_T: LED4.2 (RK), R7.2
/RGB/RGB1_B_GATE: Q2.4 (G), U8.4 (2Y)
/RGB/RGB1_G_GATE: Q1.4 (G), U7.4 (2Y)
/RGB/RGB1_R_GATE: Q1.2 (G), U7.6 (1Y)
/RGB/RGB2_5V_B_K_T: LED5.4 (BK), R15.2
/RGB/RGB2_5V_G_K_T: LED5.3 (GK), R14.2
/RGB/RGB2_5V_R_K_T: LED5.2 (RK), R13.2
/RGB/RGB2_B_GATE: Q3.2 (G), U9.6 (1Y)
/RGB/RGB2_G_GATE: Q2.2 (G), U8.6 (1Y)
/RGB/RGB2_R_GATE: Q3.4 (G), U9.4 (2Y)
GND: J1.MP (MountPin), J2.MP (MountPin), J5.3 (GND), J5.MP, J6.3 (GND), J6.MP, Q1.1 (S), Q1.3 (S), Q2.1 (S), Q2.3 (S), Q3.1 (S), Q3.3 (S), Q5.2 (S), R10.1, RN2.1 (R1.1), RN2.8 (R1.2), RN3.1 (R1.1), RN3.8 (R1.2), U3.4 (GND), U4.4 (GND), U7.2 (GND), U8.2 (GND), U9.2 (GND); also elsewhere on the board
unnamed: J5.2 (V+), JP1.2 (B)
unnamed: Q5.3 (D), Q6.1 (G), R9.1
unnamed: U3.5 (DO), U4.6 (DIN)
PIXEL_DATA: J5.1 (Sig), U3.6 (DIN); also elsewhere on the board
PIXEL_DATA_OUT: J6.1 (Sig), U4.5 (DO)
RGB1_B: J1.4, Q2.6 (D)
RGB1_B_EN_T: R12.1, RN2.2 (R2.1), U3.3 (OUTB), U8.3 (2A)
RGB1_G: J1.2, Q1.6 (D)
RGB1_G_EN_T: R11.1, RN2.3 (R3.1), U3.2 (OUTG), U7.3 (2A)
RGB1_R: J1.3, Q1.5 (D)
RGB1_R_EN_T: R7.1, RN2.4 (R4.1), U3.1 (OUTR), U7.1 (1A)
RGB2_B: J2.4, Q3.5 (D)
RGB2_B_EN_T: R15.1, RN3.2 (R2.1), U4.3 (OUTB), U9.1 (1A)
RGB2_G: J2.2, Q2.5 (D)
RGB2_G_EN_T: R14.1, RN3.3 (R3.1), U4.2 (OUTG), U8.1 (1A)
RGB2_R: J2.3, Q3.6 (D)
RGB2_R_EN_T: R13.1, RN3.4 (R4.1), U4.1 (OUTR), U9.3 (2A)
RGB_LED_5V: LED4.1 (A), LED5.1 (A), Q6.3 (D)
RGB_LED_EN: Q5.1 (G), R10.2; also elsewhere on the board

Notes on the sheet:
24V LED connectors
RGB Indicator LEDs
24V RGB LED srivers
RGB data connectors
CERN-OHL-P v2

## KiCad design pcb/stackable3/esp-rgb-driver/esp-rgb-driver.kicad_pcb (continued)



Board: 2 copper layers, 66.0 x 32.0 mm, 65 parts (2 on the bottom side), 58 nets.

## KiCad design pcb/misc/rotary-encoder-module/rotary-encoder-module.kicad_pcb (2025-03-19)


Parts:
C1: 1u; C_0603_1608Metric_Pad1.08x0.95mm_HandSolder; LCSC Part C5199872
C2, C3: 10n; C_0603_1608Metric_Pad1.08x0.95mm_HandSolder; LCSC Part C1589
J1: JST SH; JST_SH_SM05B-SRSS-TB_1x05-1MP_P1.00mm_Horizontal; LCSC Part C7433426
J2: Pin headers; PinHeader_1x05_P2.54mm_Vertical_simple_pad1gnd
JP1, JP2: SolderJumper_2_Bridged; SolderJumper-2_P1.3mm_Bridged_RoundedPad1.0x1.5mm
LED1: Ice Blue; LED_0402_1005Metric_Pad0.77x0.64mm_HandSolder; LCSC Part C7496805
LED2: White; LED_0402_1005Metric_Pad0.77x0.64mm_HandSolder; LCSC Part C20613596
LED3: Green; LED_0402_1005Metric_Pad0.77x0.64mm_HandSolder; LCSC Part C7496801
RN1, RN2: 10K; R_Array_Convex_4x0603; LCSC Part C110924
SW1: RotaryEncoder_Switch_MP; RotaryEncoder_Alps_EC11E-Switch_Vertical_H20mm

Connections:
BUTTON: J1.3 (SW), J2.3, JP1.1 (A), RN2.3 (R3.1), SW1.S1
CLK: C2.1, J1.5 (CLK), J2.5, RN1.3 (R3.1), RN2.1 (R1.1), SW1.A
DT: C3.1, J1.4 (DT), J2.4, RN1.4 (R4.1), RN2.2 (R2.1), SW1.B
GND: C1.2, C2.2, C3.2, J1.1 (GND), J1.MP, J2.1, RN1.1 (R1.1), RN1.8 (R1.2), RN2.4 (R4.1), RN2.5 (R4.2), SW1.C, SW1.MP, SW1.S2
LED_VCC: JP2.2 (B), LED1.2 (A), LED2.2 (A), LED3.2 (A)
unnamed: JP1.2 (B), RN1.2 (R2.1)
unnamed: LED1.1 (K), RN2.8 (R1.2)
unnamed: LED2.1 (K), RN2.7 (R2.2)
unnamed: LED3.1 (K), RN2.6 (R3.2)
VCC: C1.1, J1.2 (+3V3), J2.2, JP2.1 (A), RN1.5 (R4.2), RN1.6 (R3.2), RN1.7 (R2.2)

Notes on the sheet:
CERN-OHL-P v2



Board: 2 copper layers, 15.0 x 21.2 mm, 13 parts (12 on the bottom side), 10 nets.

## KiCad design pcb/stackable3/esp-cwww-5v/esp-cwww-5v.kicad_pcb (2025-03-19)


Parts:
C7, C8: 10n; C_0402_1005Metric; LCSC Part C60133
C9: 0u1; C_0402_1005Metric; LCSC Part C152814
C10: 1u; C_0402_1005Metric; LCSC Part C52923
J1: JST PH; STEMMA-Signal-SMD-horizontal; LCSC Part C5372880
J2: Qwiic; Qwiic-SMD-horizontal; LCSC Part C19270571
J3: JST SH; JST_SH_SM05B-SRSS-TB_1x05-1MP_P1.00mm_Horizontal; LCSC Part C7433426
LED0: XL-1606UWC; LED_SideEmitter_1.7x1.1mm; LCSC Part C965866
PIX1, PIX2, PIX3, PIX4: SK6812SIDE-A; LED_SK6812SIDE-A_4.0x1.6mm; LCSC Part C2890037
Q1: ZC010DNG; PDFN-8_L3.2-W3.1-P0.65-LS3.4-BL-EP2; LCSC Part C36499170
Q2: G2N7002X; SOT-523; LCSC Part C5258971
R0: 5K1; R_0402_1005Metric; LCSC Part C25905
R1, R2, R4, R5: 10K; R_0402_1005Metric; LCSC Part C25744
R6, R7: 10R; R_0402_1005Metric; LCSC Part C25077
RN1: 10K; R_Array_Convex_4x0402; LCSC Part C7422173
SM1: ESP32-C3-Super-Mini-Pins
SR1: R020; R_2512_6332Metric_Pad1.40x3.35mm_HandSolder; LCSC Part C5375467
SW1: RotaryEncoder_Switch_MP; RotaryEncoder_Alps_EC11-Switch_Horizontal_H20mm
U2: INA226; VSSOP-10_3x3mm_P0.5mm; LCSC Part C49851

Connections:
5V_SHUNT: J1.3, R7.1, SR1.2
5V_SHUNT_LOW: C9.2, R7.2, U2.8 (Vbus), U2.9 (Vin-)
+3V3: C10.1, J2.2 (+3V3), J3.2 (+3V3), Q2.1 (G), R1.1, RN1.5 (R4.2), RN1.6 (R3.2), RN1.7 (R2.2), SM1.3V3 (+3.3V), U2.6 (VS)
+5V: PIX1.2 (VDD), PIX2.2 (VDD), PIX3.2 (VDD), PIX4.2 (VDD), R2.1, R6.1, SM1.5V (+5V), SR1.1
/PIX2_DATA_S: PIX1.3 (DOUT), PIX2.1 (DIN)
/PIX3_DATA_S: PIX2.3 (DOUT), PIX3.1 (DIN)
/PIX4_DATA_S: PIX3.3 (DOUT), PIX4.1 (DIN)
BUTTON: J3.3 (SW), RN1.4 (R4.1), SM1.3 (ADC/GPIO3), SW1.S1
CLK: C7.1, J3.5 (CLK), RN1.2 (R2.1), SM1.0 (ADC/GPIO0), SW1.A
CW_K: J1.2, Q1.5 (D)
CW_PWM_S: Q1.2 (G), R4.1, SM1.6 (GPIO6/MOSI)
DT: C8.1, J3.4 (DT), RN1.3 (R3.1), SM1.1 (ADC/GPIO1), SW1.B
GND: C7.2, C8.2, C10.2, J1.MP (MountPin), J2.1 (GND), J2.MP, J3.1 (GND), J3.MP, LED0.1 (K), PIX1.4 (VSS), PIX2.4 (VSS), PIX3.4 (VSS), PIX4.4 (VSS), Q1.1 (S), Q1.3 (S), R4.2, R5.2, RN1.1 (R1.1), RN1.8 (R1.2), SM1.G (GND), SW1.C, SW1.MP, SW1.S2, U2.1 (A1), U2.2 (A0), U2.7 (GND)
NEOPIXEL_DATA_3V3: Q2.2 (S), R1.2, SM1.10 (GPIO10)
NEOPIXEL_DATA_5V: PIX1.1 (DIN), Q2.3 (D), R2.2
unnamed: LED0.2 (A), R0.1
unnamed: C9.1, R6.2, U2.10 (Vin+)
SCL: J2.4 (SCL), SM1.9 (~GPIO9/SCL), U2.5 (SCL)
SDA: J2.3 (SDA), SM1.8 (~GPIO8/SDA), U2.4 (SDA)
STATUS_LED: R0.2, SM1.2 (ADC/~GPIO2)
WW_K: J1.1, Q1.6 (D)
WW_PWM_S: Q1.4 (G), R5.1, SM1.7 (GPIO7/SS)

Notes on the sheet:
Onboard Neopixels
Logic level translation, filtering
Connectors
Power PWM
Power measurement
Rotary encoder
Microcontroller
CERN-OHL-P v2



Board: 2 copper layers, 32.0 x 32.0 mm, 26 parts (5 on the bottom side), 22 nets.

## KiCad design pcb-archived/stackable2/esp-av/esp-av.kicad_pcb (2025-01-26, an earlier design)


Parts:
C1, C4, C5, C10, C11: 10u; C_0603_1608Metric
C2, C3, C6, C8, C12, C13: 0u1; C_0603_1608Metric
C7: 1u; C_0603_1608Metric
C14, C15, C16, C17, C18: 22u; C_0603_1608Metric
D0: D_TVS; D_SOD-123F; LCSC Part C7473216
D1, D2: 1N4148WS; D_SOD-323
F1: 16V 2A; Fuse_1206_3216Metric; LCSC Part C2982271
J0: DC-005; BarrelJack_DC-005_THT_Horizontal
J1: USB_C_Receptacle_USB2.0_16P; USB_C_Receptacle_GCT_USB4105-xx-A_16P_TopMnt_Horizontal; LCSC Part C2765186
J10: JST SH; JST_SH_SM05B-SRSS-TB_1x05-1MP_P1.00mm_Horizontal
J11: STEMMA-Signal; STEMMA-Signal-SMD-horizontal
JP5: 1-2; SolderJumper-3_P1.3mm_Bridged12_RoundedPad1.0x1.5mm
L1: 4u7; L_1008_2520Metric; LCSC Part C22471106
LED0: Red; LED_0603_1608Metric
LED5: SK6812SIDE-A; LED_SK6812SIDE-A_4.0x1.6mm; LCSC Part C2890037
Q1: PDNM6ET20V05; SOT-563; LCSC Part C918811
R1, R2: 5K1; R_0603_1608Metric
R3, R4, R9: 10K; R_0603_1608Metric
R8: 57K6; R_0603_1608Metric
RN3: 100K; R_Array_Convex_4x0603_HandSolder
SM1: ESP32-C3-WROOM-02
SW1: Reset; SW_Push_1P1T-MP_NO_4.6x3mm_Horizontal
SW2: Boot; SW_SPST_TL3342
U1: USBLC6-2P6; SOT-666; LCSC Part C29780639
U2: ME6211C33M5; SOT-23-5; LCSC Part C82942
U3: TPS563201; SOT-23-6; LCSC Part C116592
U11: SN74LVC1T45Z6; SOT-563; LCSC Part C441819

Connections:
+3V3: C3.1, C4.1, C5.1, C6.1, J10.2, RN3.5 (R4.2), RN3.6 (R3.2), RN3.7 (R2.2), RN3.8 (R1.2), SM1.1 (3V3), U2.5 (V_{OUT}), U11.6 (VCCB); also elsewhere on the board
+5V: C1.1, C2.1, C14.1, C15.1, J1.A4 (VBUS), J1.A9 (VBUS), J1.B4 (VBUS), J1.B9 (VBUS), J11.2 (V+), L1.2, LED5.2 (VDD), R8.2, U1.5 (VBUS), U2.1 (V_{IN}), U2.3 (CE), U11.1 (VCCA); also elsewhere on the board
+12V: C10.1, C11.1, C12.1, F1.2, LED0.1 (K), R3.1, U3.3 (VIN)
/CC1: J1.A5 (CC1), R2.2
/CC2: J1.B5 (CC2), R1.2
/DC_IN_RAW: C16.1, C17.1, C18.1, D0.2 (A2), F1.1, J0.1, R4.2
/PIXEL_DATA: JP5.2 (C), U11.3 (A)
/PIXEL_DIN: JP5.1 (A), LED5.1 (DIN)
/RX_5V_SW: D2.2 (A), Q1.1 (S)
/SW_5V: C13.2, L1.1, U3.2 (SW)
/USB_DM: J1.A7 (D-), J1.B7 (D-), U1.1 (I/O1)
/USB_DP: J1.A6 (D+), J1.B6 (D+), U1.3 (I/O2)
D+: SM1.14 (IO19/USB_D+), U1.4 (I/O2)
D-: SM1.13 (IO18/USB_D-), U1.6 (I/O1)
ESP32_EN: C7.1, C8.1, RN3.3 (R3.1), SM1.2 (EN), SW1.1
FB_5V: R8.1, R9.2, U3.4 (VFB)
GND: C1.2, C2.2, C3.2, C4.2, C5.2, C6.2, C7.2, C8.2, C10.2, C11.2, C12.2, C14.2, C15.2, C16.2, C17.2, C18.2, D0.1 (A1), J0.2, J1.A1 (GND), J1.A12 (GND), J1.B1 (GND), J1.B12 (GND), J1.S1 (SHIELD), J10.1, J10.MP (MountPin), J11.1 (Sig), J11.MP, LED5.4 (VSS), R1.1, R2.1, R9.1, SM1.9 (GND), SM1.19 (GND), SW1.2, SW1.MP (MountPin), SW2.2, U1.2 (GND), U2.2 (V_{SS}), U3.1 (GND), U11.2 (GND), U11.5 (DIR); also elsewhere on the board
GPIO2: RN3.1 (R1.1), SM1.16 (IO2); also elsewhere on the board
IO7/SW/DATA: J10.3, SM1.6 (IO7)
IO8/DT/LOAD: J10.4, RN3.2 (R2.1), SM1.7 (IO8)
IO9/CLK: J10.5, RN3.4 (R4.1), SM1.8 (IO9), SW2.1
LED_EN: SM1.3 (IO4); also elsewhere on the board
unnamed: LED0.2 (A), R4.1
unnamed: R3.2, U3.5 (EN)
unnamed: C13.1, U3.6 (VBST)
PIXEL_DATA_3V3: SM1.4 (IO5), U11.4 (B)
PIXEL_DOUT: J11.3 (GND), JP5.3 (B), LED5.3 (DOUT)
RX: Q1.6 (D); also elsewhere on the board
RX1_MODE: SM1.10 (IO10); also elsewhere on the board
RX2_MODE: SM1.15 (IO3); also elsewhere on the board
RX3_MODE: SM1.17 (IO1); also elsewhere on the board
RX4_MODE: SM1.18 (IO0); also elsewhere on the board
RX_3V3: SM1.11 (IO20/RXD); also elsewhere on the board
RX_TX_EN: Q1.2 (G), SM1.5 (IO6); also elsewhere on the board
TX: D1.1 (K), D2.1 (K); also elsewhere on the board
TX_3V3: D1.2 (A), SM1.12 (IO21/TXD)

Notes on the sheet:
5V to 3.3V LDO Regulator
Connectors
12 power input, 5V DC buck converter
Onboard Neopixel
Subsheets
Infrared RX->TX Control
USB-C Port
Microcontroller
CERN-OHL-P v2


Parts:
LED1, LED2: XL-1606UWC; LED_SideEmitter_1.7x1.1mm; LCSC Part C965866
LED3, LED4: XL-1606UBC; LED_SideEmitter_1.7x1.1mm; LCSC Part C965865
Q7, Q8, Q9: PDNM6ET20V05; SOT-563; LCSC Part C918811
R16, R18: 100K; R_0603_1608Metric
RN1: 5K1; R_Array_Convex_4x0603_HandSolder
RN2: 10K; R_Array_Convex_4x0603_HandSolder

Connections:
+3V3: R16.2, R18.2; also elsewhere on the board
+5V: RN1.5 (R4.2), RN1.6 (R3.2), RN1.7 (R2.2), RN1.8 (R1.2), RN2.6 (R3.2); also elsewhere on the board
GND: Q9.4 (S); also elsewhere on the board
GPIO2: Q9.2 (G), R16.1; also elsewhere on the board
LED_EN: Q9.5 (G), R18.1; also elsewhere on the board
LED_GND: Q7.1 (S), Q7.4 (S), Q8.1 (S), Q8.4 (S), Q9.1 (S), Q9.3 (D), RN2.1 (R1.1), RN2.2 (R2.1), RN2.4 (R4.1)
unnamed: LED1.2 (A), RN1.4 (R4.1)
unnamed: LED1.1 (K), Q9.6 (D)
unnamed: LED2.2 (A), RN1.3 (R3.1)
unnamed: LED2.1 (K), Q8.6 (D)
unnamed: LED3.2 (A), RN1.1 (R1.1)
unnamed: LED3.1 (K), Q7.3 (D)
unnamed: LED4.2 (A), RN1.2 (R2.1)
unnamed: LED4.1 (K), Q7.6 (D)
unnamed: Q8.2 (G), Q8.3 (D), RN2.3 (R3.1)
RX: Q7.5 (G), RN2.8 (R1.2); also elsewhere on the board
RX_TX_EN: Q8.5 (G), RN2.5 (R4.2); also elsewhere on the board
TX: Q7.2 (G), RN2.7 (R2.2); also elsewhere on the board

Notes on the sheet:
LED brightness and toggle
Indicator LEDs


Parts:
D3, D4, D5, D6: 1N4148WS; D_SOD-323
J2, J3, J4, J5: PJ-327U; Jack_3.5mm_PJ-327U-SMT_Horizontal; LCSC Part C397453
U4, U5: NC7WZ14P6X; SOT-363_SC-70-6_HandSolder; LCSC Part C5207816
U6, U7, U8, U9: SN74LVC1G157DC; SOT-363_SC-70-6_HandSolder; LCSC Part C22469913
U10: SN74LVC1T45Z6; SOT-563; LCSC Part C441819

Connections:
+3V3: U10.1 (VCCA); also elsewhere on the board
+5V: J2.R, J3.R, J4.R, J5.R, U4.5 (V_{CC}), U5.5 (V_{CC}), U6.5 (V_{CC}), U7.5 (V_{CC}), U8.5 (V_{CC}), U9.5 (V_{CC}), U10.6 (VCCB); also elsewhere on the board
GND: J2.S, J3.S, J4.S, J5.S, U4.2 (GND), U5.2 (GND), U6.2 (GND), U7.2 (GND), U8.2 (GND), U9.2 (GND), U10.2 (GND), U10.5 (DIR); also elsewhere on the board
unnamed: D3.2 (A), U6.4 (Y)
unnamed: D4.2 (A), U7.4 (Y)
unnamed: D5.2 (A), U8.4 (Y)
unnamed: D6.2 (A), U9.4 (Y)
RX: D3.1 (K), D4.1 (K), D5.1 (K), D6.1 (K), U10.4 (B); also elsewhere on the board
RX1_5V: J2.T, U4.1 (1A), U6.1 (I1)
RX1_5V_INV: U4.6 (1Y), U6.3 (I0)
RX1_MODE: U6.6 (S); also elsewhere on the board
RX2_5V: J3.T, U4.3 (2A), U7.1 (I1)
RX2_5V_INV: U4.4 (2Y), U7.3 (I0)
RX2_MODE: U7.6 (S); also elsewhere on the board
RX3_5V: J4.T, U5.1 (1A), U8.1 (I1)
RX3_5V_INV: U5.6 (1Y), U8.3 (I0)
RX3_MODE: U8.6 (S); also elsewhere on the board
RX4_5V: J5.T, U5.3 (2A), U9.1 (I1)
RX4_5V_INV: U5.4 (2Y), U9.3 (I0)
RX4_MODE: U9.6 (S); also elsewhere on the board
RX_3V3: U10.3 (A); also elsewhere on the board

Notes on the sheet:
Signal inverters
3.5mm TRS connectors
5V to 3.3V logic level translation
Signal selectors

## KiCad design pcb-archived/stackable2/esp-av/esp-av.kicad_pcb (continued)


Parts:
C9: 1000u; CP_Elec_8x10
C19, C20, C21, C22: 22u; C_0603_1608Metric
J6, J7, J8, J9: PJ-327U; Jack_3.5mm_PJ-327U-SMT_Horizontal; LCSC Part C397453
JP1, JP2, JP3, JP4: Open; SolderJumper-2_P1.3mm_Open_TrianglePad1.0x1.5mm
Q1: PDNM6ET20V05; SOT-563; LCSC Part C918811
Q3, Q4, Q5, Q6: AO3401A; SOT-23
R5, R6, R7, R17: 100K; R_0603_1608Metric
R10, R11: 2K2; R_0603_1608Metric
R12, R13, R14, R15: 15R; R_1206_3216Metric

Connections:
+5V: C9.1, C19.1, C20.1, C21.1, C22.1, JP1.1 (A), JP2.1 (A), JP3.1 (A), JP4.1 (A), Q3.2 (S), Q4.2 (S), Q5.2 (S), Q6.2 (S), R11.1; also elsewhere on the board
/Infrared Transmitter/TX1_5V_J: J6.R, JP1.2 (B)
/Infrared Transmitter/TX1_A_P: Q3.3 (D), R14.1
/Infrared Transmitter/TX2_5V_J: J7.R, JP2.2 (B)
/Infrared Transmitter/TX2_A_P: Q4.3 (D), R12.1
/Infrared Transmitter/TX3_5V_J: J8.R, JP3.2 (B)
/Infrared Transmitter/TX3_A_P: Q5.3 (D), R15.1
/Infrared Transmitter/TX4_5V_J: J9.R, JP4.2 (B)
/Infrared Transmitter/TX4_A_P: Q6.3 (D), R13.1
GND: C9.2, C19.2, C20.2, C21.2, C22.2, J6.S, J7.S, J8.S, J9.S, Q1.4 (S), R5.2, R6.2, R7.2, R10.2, R17.2; also elsewhere on the board
TX: Q1.5 (G), R10.1; also elsewhere on the board
TX1_A: J6.T, R5.1, R14.2
TX2_A: J7.T, R6.1, R12.2
TX3_A: J8.T, R7.1, R15.2
TX4_A: J9.T, R13.2, R17.1
TX_INV: Q1.3 (D), Q3.1 (G), Q4.1 (G), Q5.1 (G), Q6.1 (G), R11.2

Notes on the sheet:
Signal inverter
3.5mm TRS connectors
Signal drivers



Board: 2 copper layers, 82.0 x 40.0 mm, 97 parts (7 on the bottom side), 71 nets.

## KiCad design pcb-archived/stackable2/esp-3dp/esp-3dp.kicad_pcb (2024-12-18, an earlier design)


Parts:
C1, C2, C8, C9: 10u; C_0603_1608Metric
C3, C4, C10, C11: 0u1; C_0402_1005Metric
C5, C6: 22u; C_0805_2012Metric
C7: 470u; CP_Elec_8x10
C12, C13: 22u; C_0603_1608Metric
C14: 1000u; CP_Elec_8x10
D1: DSK34W; D_SOD-123F; LCSC Part C3014041
D2: D_TVS; D_SOD-123F
D3: 10V; D_SOD-523
F1: 30V 2A; Fuse_1812_4532Metric
J0, J1: DC-050; BarrelJack_DC-050_SMT_Horizontal
J2, J3: JST SH; JST_SH_SM05B-SRSS-TB_1x05-1MP_P1.00mm_Horizontal
J4: STEMMA-Signal; STEMMA-Signal-SMD-horizontal
J5: Qwiic; Qwiic-SMD-horizontal
L1: 22u; L_Power_7.0x6.6mm_0630
L2: 4u7; L_1008_2520Metric
LED1: LED_Small; LED_0603_1608Metric
LED2: Red; LED_0402_1005Metric
M1: KF2510; FanPinHeader_1x04_P2.54mm_Horizontal
PIX1, PIX2: SK6812; LED_SK6812_PLCC4_5.0x5.0mm_P3.2mm
Q1: 2N7002DW; SOT-363_SC-70-6_HandSolder; LCSC Part C5190214
Q3: AO3401A; SOT-23
R0: 5K1; R_0603_1608Metric
R1: 100K; R_0402_1005Metric
R2: 5K1; R_0402_1005Metric
R3, R6, R7: 10K; R_0402_1005Metric
R4: 57K6; R_0402_1005Metric
R12: 17K4; R_0603_1608Metric
RN1: 10K; R_Array_Convex_4x0603_HandSolder
RN2: 100R; R_Array_Convex_4x0603_HandSolder
SM1: ESP32-C3-Super-Mini-Castellated-SMD-only
U1: TPS54202DDCR; SOT-23-6; LCSC Part C191884
U2: TPS563201; SOT-23-6
U4, U5: SN74LVC1T45Z6; SOT-563; LCSC Part C441819

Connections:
+3V3: J2.2, J3.2, J5.2 (+3V3), Q1.2 (G), RN1.6 (R3.2), SM1.3V3 (+3.3V), U4.6 (VCCB), U5.6 (VCCB)
+5V: C12.1, C13.1, C14.1, J4.2 (V+), L2.2, PIX1.3 (VDD), PIX2.3 (VDD), R4.2, RN1.5 (R4.2), SM1.5V (+5V), U4.1 (VCCA), U5.1 (VCCA)
+12V: C5.1, C6.1, C8.1, C9.1, C10.1, D1.1 (K), L1.2, M1.2 (+), R1.2, R7.1, U2.3 (VIN)
+24V: C1.1, C2.1, C3.1, D3.1 (K), F1.2, LED2.1 (K), Q3.2 (S), R12.1, U1.3 (VIN)
/24V_IN_RAW: C7.1, D2.2 (A2), F1.1, J0.1, R3.2
/FAN_PWM_3V3_R: Q1.1 (S), RN1.3 (R3.1), RN2.5 (R4.2)
/NP_1_DATA_3V3_R: RN2.2 (R2.1), U4.4 (B)
/NP_2_DATA_3V3_R: RN2.1 (R1.1), U5.4 (B)
/N_GATE_1: Q1.5 (G), RN1.1 (R1.1), RN2.6 (R3.2)
/N_SRC_1: Q1.4 (S), RN1.2 (R2.1)
/P_GATE_1: D3.2 (A), Q1.3 (D), Q3.1 (G), R12.2
/SW_5V: C11.2, L2.1, U2.2 (SW)
/SW_12V: C4.2, L1.1, U1.2 (SW)
FAN_BUTTON: J3.3, SM1.10 (GPIO10)
FAN_CLK: J3.5, SM1.3 (ADC/GPIO3)
FAN_DT: J3.4, SM1.4 (SCK/ADC/GPIO4)
FAN_PWM_3V3: RN2.4 (R4.1), SM1.21 (GPIO21/TX)
FAN_PWM_5V: M1.4 (PWM), Q1.6 (D), RN1.4 (R4.1)
FB_5V: R4.1, R6.2, U2.4 (VFB)
FB_12V: R1.1, R2.2, U1.4 (FB)
GND: C1.2, C2.2, C3.2, C5.2, C6.2, C7.2, C8.2, C9.2, C10.2, C12.2, C13.2, C14.2, D1.2 (A), D2.1 (A1), J0.2, J1.2, J2.1, J2.MP (MountPin), J3.1, J3.MP (MountPin), J4.3 (GND), J4.MP, J5.1 (GND), J5.MP, LED1.1 (K), M1.1 (-), PIX1.1 (VSS), PIX2.1 (VSS), R2.1, R6.1, RN1.7 (R2.2), RN1.8 (R1.2), SM1.G (GND), U1.1 (GND), U2.1 (GND), U4.2 (GND), U4.5 (DIR), U5.2 (GND), U5.5 (DIR)
LIGHT_BUTTON: J2.3, SM1.5 (GPIO5/MISO)
LIGHT_CLK: J2.5, SM1.7 (GPIO7/SS)
LIGHT_DT: J2.4, SM1.6 (GPIO6/MOSI)
LIGHT_OUT: J1.1, Q3.3 (D)
LIGHT_PWM_3V3: RN2.3 (R3.1), SM1.20 (GPIO20/RX)
NEOPIXEL_1_DATA_3V3: RN2.7 (R2.2), SM1.1 (ADC/GPIO1)
NEOPIXEL_1_DATA_5V: PIX1.2 (DIN), U4.3 (A)
NEOPIXEL_2_DATA_3V3: RN2.8 (R1.2), SM1.0 (ADC/GPIO0)
NEOPIXEL_2_DATA_5V: J4.1 (Sig), U5.3 (A)
unnamed: LED1.2 (A), R0.1
unnamed: LED2.2 (A), R3.1
unnamed: PIX1.4 (DOUT), PIX2.2 (DIN)
unnamed: C4.1, U1.6 (BOOT)
unnamed: R7.2, U2.5 (EN)
unnamed: C11.1, U2.6 (VBST)
SCL: J5.4 (SCL), SM1.9 (~GPIO9/SCL)
SDA: J5.3 (SDA), SM1.8 (~GPIO8/SDA)
STATUS_LED: R0.2, SM1.2 (ADC/~GPIO2)

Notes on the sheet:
5V DC buck converter
Power input
12V DC buck converter
Microcontroller
PWM power outputs
Onboard Neopixels
Pins and Connectors
Logic level translation, filtering
Power PWM
CERN-OHL-P v2



Board: 2 copper layers, 40.0 x 40.0 mm, 52 parts (5 on the bottom side), 39 nets.

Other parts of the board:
MH_NE: MountingHole_3.2mm_M3_Pad_Via_corner_compact
MH_NW: MountingHole_3.2mm_M3_Pad_Via_corner_compact
MH_SE: MountingHole_3.2mm_M3_Pad_Via_corner_compact
MH_SW: MountingHole_3.2mm_M3_Pad_Via_corner_compact

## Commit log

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2024-03-24 Add TP4056 charge, LS, protect board
    This also moves graphics footprints from the custom footprints library
    to a new graphics footprints library
    [power-tp4056-ls.kicad_pcb, power-tp4056-ls.kicad_sch]
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2024-03-24 Update LCSC part numbers and JLCPCB positioning info
    [power-tp4056-ls.kicad_pcb, power-tp4056-ls.kicad_sch]
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2024-03-25 Replace XB5307H with XB5350D0 for Li-Ion battery protection
    XB5307H has an overcharge cutoff voltage of 4.425V, while XB5350D0 has
    an overcharge cutoff voltage of 4.25V. Both ICs have an underdischarge
    cutoff voltage of 3V.
    [power-tp4056-ls-boost.kicad_pcb, power-tp4056-ls-boost.kicad_sch, power-tp4056-ls.kicad_pcb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]
2024-03-25 Update silkscreen and datasheet links for battery protection ICs
    [power-tp4056-ls-boost.kicad_pcb, power-tp4056-ls-boost.kicad_sch, power-tp4056-ls.kicad_pcb]
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2024-03-29 Improve TP4056 exposed pad connectivity to GND plane
    [power-tp4056-5v-ups.kicad_pcb]
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2024-05-30 Move TP4056 UPS board README to correct directory
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2024-07-21 Implement garage door control circuit diagram and mock board
    [garage-door-control.kicad_pcb, garage-door-control.kicad_sch]
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2024-07-27 Rework garage board with sensors and for PCB printing
    [garage-door-control.kicad_pcb, garage-door-control.kicad_sch]
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2024-07-27 Swap power symbols in template
    [{{ cookiecutter.project_name }}.kicad_sch]
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2024-08-06 Rework power-dev-buck-tps54202
    [power-dev-buck-tps54202.kicad_pcb, power-dev-buck-tps54202.kicad_sch]
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2024-08-10 Fix symlinks in power-dev-ip5209-ups
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2024-08-10 Remove extra diode, fix silkscreen text on power-tp4056-5v-ups
    [power-tp4056-5v-ups.kicad_pcb, power-tp4056-5v-ups.kicad_sch]
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2024-08-13 Rework resistors and traces
    [breadboard-power.kicad_pcb, breadboard-power.kicad_sch]
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2024-08-20 Support SMD JST XH connector as option on breadboard power PCB
    [breadboard-power.kicad_pcb, breadboard-power.kicad_sch]
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2024-08-20 Update cross-power circuit and rework PCB layout
    [breadboard-power.kicad_pcb, breadboard-power.kicad_sch]
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2024-08-23 Update IP5209T board to rev2 after testing
    - Connect IP5209T NTC pin to GND
    - Connect flashlight LED source to VBAT instead of GND
    [battery_charger.kicad_sch, power-dev-ip5209-ups.kicad_pcb]
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2024-08-23 Flip pin headers to bottom of board
    [power-dev-ip5209-ups.kicad_pcb]
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2024-08-23 Replace XB5350D0 with XB3306D for battery protection
    [battery_protection.kicad_sch, power-dev-ip5209-ups.kicad_pcb]
2024-08-23 Replace MT3608 with FP6276BXR for boost converter IC
    [battery_charger.kicad_sch, boost_converter.kicad_sch, power-dev-ip5209-ups.kicad_pcb]
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2024-08-23 Replace AMS1117 with MT6211 on breadboard microcontroller power board
    [breadboard-power-microcontroller.kicad_pcb, breadboard-power-microcontroller.kicad_sch]
2024-08-23 Rework traces and layout
    [breadboard-power-microcontroller.kicad_pcb]
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2024-08-24 Update inductor footprint on tps54202 buck dev board
    [power-dev-buck-tps54202.kicad_pcb]
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2024-08-24 Redesign power-dev-buck-tps54202
    [power-dev-buck-tps54202.kicad_pcb, power-dev-buck-tps54202.kicad_sch]
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2024-08-28 Rework Aliexpress module symbols/footprints, add ESP32-CAM
2024-08-28 Update garage-door-control board to rev2 for footprint updates
    [garage-door-control.kicad_pcb]
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2024-09-08 Fix symlinks in power-dev-buck-tps563201
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2024-09-13 Drive ETA6003 STAT LED from VIN instead of SYS
    [power-dev-eta6003-ups.kicad_sch]
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2024-09-13 Fix B+ track near terminal block
    [power-dev-eta6003-ups.kicad_pcb]
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2024-09-15 Add missing footprints for power-18650-holder
    [power-18650-holder.kicad_pcb, power-18650-holder.kicad_sch]
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2024-09-15 Move breadboard jig PCBs to new pcb-jigs directory
    [dip-adapters.kicad_pcb, dip-adapters.kicad_sch, led-jig-pico.kicad_pcb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]
2024-09-15 Move in-development stackable boards to new pcb-stackable-dev directory
    [connectors.kicad_sch, esp-sensors.kicad_pcb, esp-sensors.kicad_sch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]
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2024-09-15 NFC: Update symbols and footprints in garage-door-control
    Adds some minor silkscreen and trace updates, but no functional changes
    [garage-door-control.kicad_pcb, garage-door-control.kicad_sch]
2024-09-15 NFC: Use SM designators, add module names to AliExpress module symbols
    [garage-door-control.kicad_pcb, garage-door-control.kicad_sch]
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2024-09-15 Fixup relay-module-5v-x2 file names and references
    [relay-module-5v-x2.kicad_pcb, relay-module-5v-x2.kicad_sch]
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2024-09-15 Support JST XH 1x03 along with screw terminals on relay boards
    [relay-module-5v-half.kicad_pcb, relay-module-5v-half.kicad_sch, relay-module-5v-x2.kicad_pcb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]
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2024-09-15 Add reverse-mount Neopixel footprint to LCSC library
2024-09-15 Swap switch polarity on stackable 5V relay dev boards
    [relay-module-5v-half.kicad_pcb, relay-module-5v-half.kicad_sch, relay-module-5v-x2.kicad_pcb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]
2024-09-16 Support JST PH connectors in relay-module-5v-half connector footprints
    [relay-module-5v-half.kicad_pcb, relay-module-5v-half.kicad_sch]
2024-09-16 Fixup relay test button functionality in stackable relay module boards
    [relay-module-5v-half.kicad_pcb, relay-module-5v-half.kicad_sch, relay-module-5v-x2.kicad_pcb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]
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2024-10-05 Rework mounting hole footprints for board edge clearance
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2024-10-05 Fix ch1/2 silkscreen markings on esp-neopixel-driver
    [esp-neopixel-driver.kicad_pcb]
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2024-10-10 Add missing SMD electrolytic/ceramic capacitor combo footprint
2024-10-10 Add WA icon to jig boards, square ground pads on μbuck/μboost
    [555-timer-jig.kicad_pcb, esp-doorbell-button-jig.kicad_pcb, power-dev-microboost.kicad_pcb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]
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2024-10-10 Fix file names in power-eta6003-5v-ups
    [power-eta6003-5v-ups.kicad_pcb, power-eta6003-5v-ups.kicad_sch]
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2024-10-15 Rework esp-3dp with 2x buck converters
    [esp-3dp.kicad_pcb, esp-3dp.kicad_sch]
2024-10-15 Rework esp-3dp with buck converter and LDO
    [esp-3dp.kicad_pcb, esp-3dp.kicad_sch]
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2024-10-17 Tweak M3 mounting hole corner curve footprints for edge clearance
2024-10-17 Update rotary encoder footprint on rotary encoder module
    [rotary-encoder-module.kicad_pcb, rotary-encoder-module.kicad_sch]
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2024-10-17 Add SMD pin sockets for LCD module on esp-lcd-dev
    [esp-lcd-dev.kicad_pcb, esp-lcd-dev.kicad_sch]
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2024-10-28 Fix X2-DFN1210-8 footprint properties
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2024-10-30 Fix silkscreen value on back of usb-pd-decoy-husb237
    [usb-pd-decoy-husb237.kicad_pcb]
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2024-11-26 Update relative library paths in project files and library tables
    [555-timer-jig.kicad_pcb, breadboard-power-jig.kicad_pcb, breadboard-power-microcontroller.kicad_pcb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]
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2024-11-30 Migrate GC9A01 symbol and FPC footprint to modules
    [lcd-round.kicad_pcb, lcd-round.kicad_sch]
2024-11-30 Migrate 0.96" OLED symbol, footprint, and model to modules
    [esp-doorbell-dev.kicad_pcb, esp-doorbell-dev.kicad_sch]
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2024-11-30 Move JLCPCB PCBA tooling hole footprint from `custom` to `mechanical`
    [buck-tps54202-compact.kicad_pcb, ip5209-ups.kicad_pcb, ip5306-ups.kicad_pcb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]
2024-11-30 Migrate JST SH connector footprints from `custom` to `connectors` library
    [connectors.kicad_sch, esp-3dp.kicad_pcb, esp-3dp.kicad_sch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]
2024-11-30 Migrate JST PH connector footprints from `custom` to `connectors` library
    [esp-cwww.kicad_pcb, esp-cwww.kicad_sch]
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2024-11-30 Fix `gr6048` project file names
    [gr6408.kicad_pcb, gr6408.kicad_sch]
2024-11-30 Fix schematic filename detection in `rename-project`
2024-11-30 Fix schematic file names in all projects
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2024-12-01 Rework scons builders, print DRC report on errors
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2024-12-02 Fix 2n7002DW datasheet file name extension case
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2024-12-02 Move retired PCB projects to new `pcb-archived` directory
    [battery-eta9740-bom.csv, battery-eta9740.kicad_pcb, battery-eta9740.kicad_sch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]
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2024-12-03 Fix and update esp-cwww
    Fixes:
    - Fix SK6812SIDE pinout
    - Add courtyard to SK6812SIDE footprint
    - Swap WW/CW in GPIO and connector pinout
    Updates:
    - Update board info on silkscreen
    - Use `packages` SOT-23-6 footprint for TPS563201
    - Avoid thermal relief on DC barrel jack GND pad
    - Modify shunt resistor value
    - Update LCSC part numbers
    Features:
    - Add JST SH connector for optional external rotary encoder, with board
    edge inset
    [esp-cwww.kicad_pcb, esp-cwww.kicad_sch]
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2024-12-03 Create `L_Power_7.0x6.6mm_0630` based on `L_Changjiang_FXL0630`
    This new inductor footprint replaces `IND-SMD_L7.0-W6.6` in `lcsc`
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2024-12-03 Create `L_Power_5.7x5.2mm_0530` based on `L_Changjiang_FXL0530`
    This new inductor footprint replaces `IND-SMD_L5.7-W5.2` in `lcsc`
2024-12-03 Fix indicator LED order on 555-timer jig
    [555-timer.kicad_pcb]
2024-12-03 Fix potentiometer pinout on 555-timer jig
    [555-timer.kicad_pcb, 555-timer.kicad_sch]
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2024-12-03 Change 555-timer jig front title string and font
    [555-timer.kicad_pcb]
2024-12-04 Fix footprints and filters for SOT-363 dual MOSFET symbols in `lcsc`
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2024-12-04 Remove fabrication outputs for boards that were never ordered
    [buck-tps54202-compact-bom.csv, esp-neopixel-driver-bom.csv, ip5306-ups-bom.csv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]
2024-12-04 Rework neopixel-driver as simpler board
    [esp-neopixel-driver.kicad_pcb, esp-neopixel-driver.kicad_sch]
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2024-12-07 Rework esp-3dp as revision 2
    - Add 24V input power protection circuitry (TVS, capacitor, fuse)
    - Replace 5V LDO regulator with buck converter using TPS563201
    - Reverse front/back connector placements. Power input is now on the
    back, while fan and light outputs are now on the front.
    - Remove 2P JST XH connector for 12V fan
    - Add 3P JST PH connector for external Neopixels
    - Replace onboard 2020 WS2811 neopixels with 5050 SK6812 neopixels
    - Remove redundant pin headers for rotary encoder
    [esp-3dp.kicad_pcb, esp-3dp.kicad_sch]
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2024-12-16 Rename `connectors` symbol and footprint libraries to `connector`
    [connectors.kicad_sch, esp-3dp.kicad_pcb, esp-3dp.kicad_sch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]
2024-12-16 Rename `modules` symbol and footprint libraries to `module`
    [esp-3dp.kicad_pcb, esp-3dp.kicad_sch, esp-cwww.kicad_pcb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]
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2024-12-16 Remove no longer used `E6C0805RQBC2UDA` symbol, footprint, and model
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2024-12-16 Migrate `VEML6030`, `VEML7700` symbols from `lcsc` to `discrete`
    [esp-lcd-dev.kicad_sch, esp-neopixel-driver.kicad_sch]
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2024-12-16 Update footprints from libraries to resolve DRC errors
    [esp-doorbell-dev.kicad_pcb, eta-buck.kicad_pcb, eta6003.kicad_pcb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]
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2024-12-16 Rework XB3306D symbol to match layout of KiCAD built-in BMS symbols
    [eta6003.kicad_sch, max17048.kicad_sch]
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2024-12-16 Restore correct XD3306D circuit in eta6003
    [eta6003.kicad_sch]
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2024-12-16 Rework `HLK-LD2410C` to match KiCAD symbol conventions
    [esp-doorbell-dev.kicad_pcb, esp-doorbell-dev.kicad_sch]
2024-12-16 Rework `BH1750` symbol to match KiCAD symbol conventions
2024-12-16 Rework `AHT20+BMP280` symbol to match KiCAD symbol conventions
    [garage-door-control.kicad_sch]
2024-12-16 Rework `ENS160+AHT2x` symbol to match KiCAD symbol conventions
    [garage-door-control.kicad_pcb, garage-door-control.kicad_sch]
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2024-12-16 Recreate `74AUP2G06FW4-7` symbol using dual schmitt inverter symbol
    [reflow-mini.kicad_pcb, reflow-mini.kicad_sch, reflow.kicad_pcb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]
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2024-12-16 Rework side-mount 1.7x1.1mm LED footprint as `LED_SideEmitter_1.7x1.1mm`
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2024-12-17 Rework XL-2012RGBC footprints, migrate from `lcsc` to `discrete`
    [led-micro.kicad_pcb, led-micro.kicad_sch]
2024-12-17 Rework XL-B1010RGBT-HF footprints, migrate from `lcsc` to `discrete`
    [reflow-mini.kicad_pcb, reflow-mini.kicad_sch, reflow.kicad_pcb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]
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2024-12-17 Rework P4-1209RGBTCA1-0.9T-A footprint, migrate to `discrete`
2024-12-17 Rework FM-3510RGBA-SG footprints, migrate from `lcsc` to `discrete`
    [esp-neopixel-driver.kicad_pcb, esp-neopixel-driver.kicad_sch]
2024-12-17 Replace 5730 LED footprint in `discrete` footprint library
2024-12-17 Update led-micro and neopixel-micro to resolve DRC errors
    [neopixel-micro.kicad_pcb]
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2024-12-17 Rework, migrate small SMD push button footprint to `electromechanical`
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2024-12-17 Rework 7x7mm DPDT toggle switch footprint
    [breadboard-power-microcontroller.kicad_pcb, breadboard-power-microcontroller.kicad_sch]
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2024-12-17 Rework 18650 battery holder footprint, migrate to `connector`
    [eta6003.kicad_sch]
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2024-12-17 Recreate 3-pin SPDT THT slide switch footprint to replace LCSC footprint
    [breadboard-power.kicad_pcb, breadboard-power.kicad_sch]
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2024-12-17 Rework, migrate TEMT6000X01 footprint from `custom` to `discrete`
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2024-12-17 Correct 1.27mm pitch IRM footprint
2024-12-18 Rework FSP-8 footprint for WS2811 symbol
    [esp-doorbell-button.kicad_pcb, esp-doorbell-button.kicad_sch, esp-doorbell-dev.kicad_pcb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]
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2025-01-20 Pin KiCAD container image to version 8.0.7 in CI
    This can be removed once the fix for
    https://gitlab.com/kicad/code/kicad/-/issues/19521 is released.
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2025-01-30 Fix ESP32-{C,S}3 Super Mini THT/SMD combo footprint pads
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2025-01-31 Fix courtyards in 3.2mm M3 5.4mm mounting hole footprints
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2025-02-03 Fix stackable3 template edge rounding
    [{{ cookiecutter.project_name }}.kicad_pcb]
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2025-02-03 Fix edge cut curve symmetry in stackable3 template
    [{{ cookiecutter.project_name }}.kicad_pcb]
2025-02-03 Change GPIO assignments on stackable3/esp-av
    This prevents the IR transmitter and shift register from boot and
    firmware update-related transient states
    [esp-av.kicad_pcb, esp-av.kicad_sch]
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2025-02-08 Use new JST SH rotary encoder connector symbol in rotary encoder module
    [rotary-encoder-module.kicad_pcb, rotary-encoder-module.kicad_sch]
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2025-02-08 Replace discrete resistor footprints with built-ins on stackable3 boards
    [esp-av.kicad_pcb, ir-trx.kicad_pcb, ir-trx.kicad_sch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]
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2025-02-09 Update stackable3/esp-av IR repeater control circuit
    This replaces the N-channel repeater signal control MOSFET with a
    P-channel MOSFET (driven by an N-channel MOSFET at -5V)
    [esp-av.kicad_pcb, esp-av.kicad_sch, tx.kicad_sch]
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2025-02-09 Expose unused GPIOs via JST PH port on the back of stackable3/esp-cwww
    [esp-cwww.kicad_pcb, esp-cwww.kicad_sch]
2025-02-11 Rework misc/esp-doorbell-dev as stackable3/esp-doorbell-dev board
    This removes the previous fab outputs for misc/esp-doorbell-dev
    [esp-doorbell-dev-bom.csv, esp-doorbell-dev.kicad_pcb, esp-doorbell-dev.kicad_sch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]
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2025-02-13 Fix rotary encoder net label directions on stackable3/esp-cwww
    [esp-cwww.kicad_sch]
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2025-02-13 Fix rotary encoder net label directions on stackable3/esp-3dp
    [esp-3dp.kicad_pcb, esp-3dp.kicad_sch]
2025-02-13 Fix net label directions on stackable3/esp-neopixel-driver
    [esp-neopixel-driver.kicad_sch]
2025-02-13 Fix rotary encoder net label directions on stackable3/esp-rgb-driver
    [esp-rgb-driver.kicad_pcb, esp-rgb-driver.kicad_sch]
2025-02-13 Fix net label direction, tweak schematic on stackable3/esp-av
    [esp-av.kicad_pcb, esp-av.kicad_sch]
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2025-02-13 Fix `IO0/SW/DATA` net label direction on stackable3/esp-neopixel-driver
    [esp-neopixel-driver.kicad_pcb, esp-neopixel-driver.kicad_sch]
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2025-02-20 Invert LED logic on rotary-encoder-module, update to v2
    This also changes the solder jumpers to bridged by default
    [rotary-encoder-module.kicad_pcb, rotary-encoder-module.kicad_sch]
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2025-02-20 Fix solder jumper clearance violation
    [rotary-encoder-module.kicad_pcb]
2025-03-08 Fix silkscreen GPIO labels on stackable3/esp-neopixel-driver
    [esp-neopixel-driver.kicad_pcb]
2025-03-08 Fix LEDs MOSFET direction in stackable3/shift-registers-74hc165 circuit
    [shift-registers-74hc165.kicad_pcb, shift-registers-74hc165.kicad_sch]
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2025-03-15 Rework stackable3/esp-rgb-driver as v3
    - Add pull-up resistors to inverter inputs
    - Add optional onboard 1x1 RGB LEDs for each output channel
    [esp-rgb-driver.kicad_pcb, esp-rgb-driver.kicad_sch, rgb.kicad_sch]
2025-03-15 Fix courtyard in `R_Array_Convex_4x0402_HandSolder` footprint
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2025-04-16 Update stackable3/esp-av to v2
    Feature changes:
    - Add 38kHz RX signal modulation
    - Add onboard infrared receiver module (IRM)
    - Add JST SH connector for 595 daisy chain outputs
    - Add transmit pin socket connector tied to TX1
    - Remove neopixel daisy-chain output connectors
    - Move indicator LEDs toggle to a 595 output
    - Swap RX multiplexer inputs so low select input is non-inverted signal
    - Invert repeater enable logic to enable when low
    - Add two more mounting holes to PCB
    Circuit changes:
    - Add power rail short protection on RX connectors
    - Add reset IC for 595 start-up state control
    - Connect indicator LED MOSFET gate pull-down resistors to ground
    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
    [esp-av.kicad_pcb, esp-av.kicad_sch, led.kicad_sch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]
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2025-04-17 Refill zones to resolve DRC errors
    [flexypin-esp32c3-wroom-jig.kicad_pcb]
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
